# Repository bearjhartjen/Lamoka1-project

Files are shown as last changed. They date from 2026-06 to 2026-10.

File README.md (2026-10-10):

<div align="center">

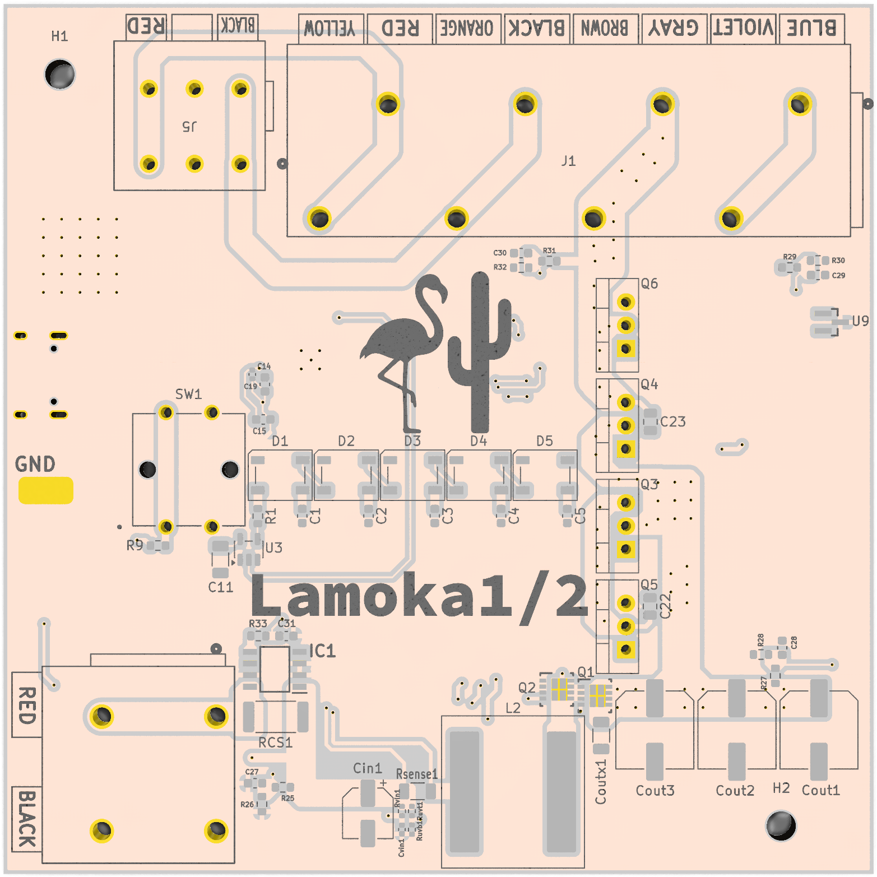
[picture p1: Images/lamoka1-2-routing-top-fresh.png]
Lamoka1/2 main PCB


<br>

<a href="https://www.bestpractices.dev/projects/14750">
  
</a>
&nbsp;&nbsp;
<a href="https://www.repo-grade.com/report/bearjhartjen/lamoka1-project">
  
</a>

</div>

---

## Owego Rotary craft fair 

 For the Owego Rotary craft fair, taking place at the Elks Lodge in Owego, NY, on November 14th from 9am to 3pm, the main project being presented by Flamingo and Cactus will be the Lamoka1/2, an inverter-only version of the Lamoka1. More details will be presented after the event. 

## What is the Lamoka1?

 The Lamoka1 is an open-source inverter/charger system designed for complete transparency and control. Unlike market alternatives that are locked-down black boxes, the Lamoka1 gives you full access to your power conversion. If you don't have technical experience, that's completely fine—our Portal Interface Engine (Lamoka's operating system) provides a solid stock setup. But if you want to get technical, feel free to customize and modify the unit however you like.

---

## Specifications 

 The Lamoka1 inverter section takes an 11V–14V input, steps it up to a 17V rail via the LM5122QMHX-NOPB boost converter, and feeds it into an H-bridge (four CSD19536KCS NMOSs driven by two UCC27735DR gate drivers) controlled by an RP2354A microcontroller—giving you total flexibility to program whatever waveform or output you need. From there, it passes into a VPT24-4170 transformer to step up the voltage.

 We use a Qualtek FAD1-04010BHLW11 fan powered from the 5V buck rail for cooling. GPIO5 and GPIO6 are unused, so the MCU provides no PWM speed control or tach feedback for the fan. The two TMP235A2DBZR temperature sensors are monitored by the system. Voltage and current monitoring is handled by the ADS7128IRTER multiplexer, the 5V rail by the TPS62160DSGR buck converter, and the user interface by ten WS2812B LEDs with a B3F-4055 button.

---

## Usage of AI in this repository 

This repository is checked, maintained, and updated by humans. The Lamoka series is neither “vibe coded” nor blindly applied. Thought, testing, engineering judgment, and practical experience go into every decision made throughout the project.

AI is used as a tool to help us bridge the gap between our current resources and the scale of what we want to accomplish. It may assist with research, development, documentation, and other aspects of the project, but its output is not treated as inherently correct. Human review, testing, and engineering judgment remain essential to the development process.

PIE OS is an exception in that a significant portion of its code was generated with the assistance of AI. However, it has been reviewed, tested extensively, and refined to meet the same standards we apply to the rest of our work.

At Flamingo and Cactus, our goal is to provide the best products, services, and experiences we can to as many people as possible. As a small team, there are limits to what we can accomplish on our own. We have very large dreams, and AI allows us to act as a much larger team without losing the human judgment and responsibility behind what we create.

---

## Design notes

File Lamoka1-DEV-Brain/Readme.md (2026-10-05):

<p align="center">
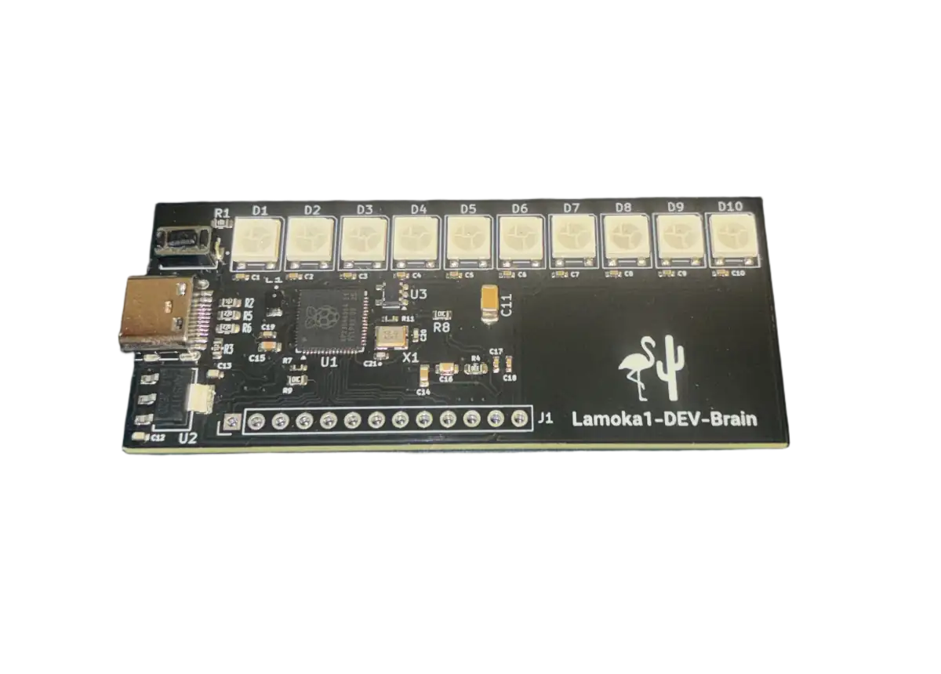
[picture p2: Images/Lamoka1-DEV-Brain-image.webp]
Lamoka1 DEV Brain
  
</p>

<p align="center">
  <strong>Lamoka1-DEV-Brain</strong>
</p>

<p align="center">
  This board can now be ordered
  <a href="https://www.pcbway.com/project/shareproject/Lamoka1_DEV_Brain_49e4fd0a.html">here</a>.
</p>

<p align="center">
  PIE versions v1.8 and below will function on this board.
  For more information on PIE, go
  <a href="../SOFTWARE/README.md">here</a>.
</p>

<p align="center">
  <a href="https://htmlpreview.github.io/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">
    <strong>View Interactive BOM</strong>
  </a>
</p>

---

> [!CAUTION]
> This device is purely for testing. Many decisions were made due to cost and time constraints. The component layout does not follow Raspberry Pi’s recommended layout guidance. Utilize these files at your own discretion.

 Flamingo and Cactus have paid PCBway to manufacture and assemble the DEV Brain. It has arrived and works much better than expected. It does, however, make some high-frequency audible noise when plugged into low-quality power sources, so it is quite sensitive to low-quality sources. 

The DEV-Brain brings the Lamoka1’s MCU, lights, and simplicity into a 70x30mm laminated sandwich (PCB).

We are using the DEV-Brain to get an idea of how things work on the control side. We can use this model board to develop code for the lights and button. We think that the DEV-Brain will be very similar to the Lamoka1, with only ten RGB LEDs and one button.

This board was run through Tomachie to get the design checked; the link is [here](https://tomachie.com/r/a1f3f256-a8ca-43de-aa92-e70ef981c3c2/Lamoka1-DEV-board_report.html#design-summary).

## Why did we develop the Lamoka1-DEV-Brain?

We need an easy platform to better understand how and where to work on the Lamoka1 control. Without a doubt, the control and logic side of the Lamoka1 is extremely important, as it allows us to expose our creativity and community for free, and to just truly have fun. The DEV-Brain also just progresses the project quite a bit and gets us moving; we don't know what to do on designing the inverter and charger sections without getting control down.
 
## How does one reproduce the Lamoka1-DEV-Brain?

 We have published the board to PCBway's share projects platform [here](https://www.pcbway.com/project/shareproject/Lamoka1_DEV_Brain_49e4fd0a.html). There, you will be able to order the Lamoka1-DEV-Brain exactly as we did. 

## Project files

- **KiCad source** — the full KiCad 10 project lives in the `Kicad files` folder. Open [Lamoka1-DEV-board.kicad_sch](<Kicad files/Lamoka1-DEV-board.kicad_sch>) for the schematic, [Lamoka1-DEV-board.kicad_pcb](<Kicad files/Lamoka1-DEV-board.kicad_pcb>) for the board layout, and [Lamoka1-DEV-board.kicad_pro](<Kicad files/Lamoka1-DEV-board.kicad_pro>) for the project settings. The `.kicad_sch` and `.kicad_pcb` files carry embedded symbol, footprint, and 3D model copies, so the design opens and renders without requiring anyone to provide copyrighted material.
- **Fab files** — everything needed to have the board manufactured yourself is in the `Lamoka1-DEV-Brain fab files` folder: the [bill of materials](<Lamoka1-DEV-Brain fab files/Lamoka1-DEV-board BOM.csv>), the [pick and place file](<Lamoka1-DEV-Brain fab files/Lamoka1-DEV-board Pick and Place.csv>), the [Gerber and drill package](<Lamoka1-DEV-Brain fab files/Lamoka1-DEV-board>), and the [PCBway assembly file](<Lamoka1-DEV-Brain fab files/PCBway files/T-1N4W1065266A-1units-Lamoka1-DEV-board+BOM(2026-07-15).xls>) we sent when we ordered our own boards.

## Tests

We were able to run the Lamoka1-DEV-Brain for 72 hours running the idle blue dot bouncing animation seen in [PIE v1.8](<../SOFTWARE/Portal Interface Engine/V1.8.ino>). The environment was an average of 70 degrees Fahrenheit, and an average humidity of 70 percent. We stopped the test early (there were no signs of issues) because we needed to use the Lamoka1-DEV-Brain to test the HTML file creation concept for getting diagnostic data on the Lamoka1.

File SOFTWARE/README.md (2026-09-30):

## What is the Portal Interface Engine?

PIE is the operating system that Lamoka models run on. It provides simple "portals" to whatever you would like with your unit. 

## Compatibility

 PIE versions v1.8 and below will work on the Lamoka1-DEV-Brain (with v1.8 working best). Due to the inclusion of voltage, temperature, and current monitoring on the ADC pins of the Lamoka1, we cannot fully guarantee successful operation of anything newer than v1.8 on the Lamoka1-DEV-Brain.

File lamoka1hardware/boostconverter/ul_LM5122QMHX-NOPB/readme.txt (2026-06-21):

Notes:
 
1. All drill sizes are the maximum size provided by the manufacture (as required to calculate the minimum pad size).
2. All dimensions in building footprints are the maximum (including any tolerance) as defined by the manufacturer with the exception of row pitch (which is always nominal).  If only the normal sizing is provided we will input that dimension in mils, rounded to the nearest mil per our standards.
3. Slots are currently identified as entities describing the size of the slot (arcs, lines, etc.) on the board outline layer.  The extremities are identified with a via at each end.  These slots will either need to be:
	a. identified and dimensioned on your fabrication document
	b. or they will need to be converted to slots (assuming the targeted tool has a slot capability) using the process defined in your cad tool for identifying a padstack as a slot.  
		i. Typically this is only capable of a width and length of the slot and a size of the mill radius that creates the slot.  
		ii. Choosing to use the native tool slots will require removing entities on the board outline and the associated pads in the footprint.

		"I greatly appreciate Texas Instruments for their absolute commitment to providing the best doccumentation, tools, calculators, etc."
		-Bear J. Hartjen

		Texas Instruments is fully responsible for the creation of the LM5122 these kicad files were found on ultra librarian.

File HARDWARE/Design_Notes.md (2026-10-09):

## MCU GPIO pin connections

 GPIO0: Connected high to 3v3 by a 10k resistor, then goes to a B3F-4055 button made by Aratas that, when pressed, pulls the pin low to ground 

 GPIO1: Controls Q3 MOSFET (CSD19536KCS made by TI) through UCC27735DR IC made by TI

 GPIO2: Controls Q5 MOSFET (CSD19536KCS made by TI) through UCC27735DR IC made by TI

 GPIO3: Controls Q4 MOSFET (CSD19536KCS made by TI) through UCC27735DR IC made by TI

 GPIO4: Controls Q6 MOSFET (CSD19536KCS made by TI) through UCC27735DR IC made by TI

 GPIO5: Not in use (unused, no connection)

 GPIO6: Not in use (unused, no connection)

 GPIO8: Connects to ADS7128IRTER made by TI SDA pin for serial data pulled up to 3v3 by a 4.7k resistor

 GPIO9: Connects to ADS7128IRTER made by TI SCL pin for serial clock pulled up to 3v3 by a 4.7k resistor

 GPIO11: Goes to a level shifter to get up to 5v, then to a 330 ohm resistor, then connects to a string of ten WS2812B lights made by WorldSemi arranged next to each other from left to right with D1 starting and D10 finishing. The press button (B3F-4055 made by Aratas) is to the left of D1.

 GPIO26: Output of the TMP235A2DBZR temp sensor made by TI located in the Control-Section

 GPIO27: Output of the TMP235A2DBZR temp sensor made by TI located in the Inverter-Section 

---

## MUX AIN pin connections (ADS7128IRTER made by TI)

 AIN0: input rail voltage sensing, top resistor 36.5k, bottom resistor 10k, 47nF cap to ground on AIN pin  

 AIN1: output of 17v boost converter voltage sensing, top resistor 43.2k, bottom resistor 10k, 47nF cap to ground on AIN pin 

 AIN2: SW_A (Leg A of H-bridge) voltage sensing, top resistor 45.3k, bottom resistor 10k, 47nF cap to ground on AIN pin

 AIN3: SW_B (Leg B of H-bridge) voltage sensing, top resistor 45.3k, bottom resistor 10k, 47nF cap to ground on AIN pin 

 AIN4: Current sensing for source rail, 11-14v goes through a 2m shunt; the shunt is connected to the INA240A2DR IC, the OUT pin of that IC goes to a 22 ohm resistor to the AIN pin, the AIN pin has a 100nF cap to ground.

---

## H-bridge (Inversion-Section) — four CSD19536KCS NMOSs made by TI, two UCC27735DR gate drivers made by TI

| H-bridge leg | High-side MOSFET | Low-side MOSFET | Gate driver | RP2354A control |
|---|---|---|---|---|
| Leg A | Q3 | Q5 | U5 | GPIO1 / GPIO2 |
| Leg B | Q4 | Q6 | U6 | GPIO3 / GPIO4 |

> **H-bridge switching:** Q3/Q5 and Q4/Q6 are the complementary MOSFET pairs for Leg A and Leg B respectively. Dead time must be implemented between the high-side and low-side devices of each leg to prevent shoot-through.

---

## Design constraints

 We are refraining from putting in a 5v USB output for the Lamoka1. This is because our 11-14v to 5v buck converter (TPS62160DSGR made by TI) is designed for usage up to one amp. In future Lamoka models, if a USB output (preferably USB-C) is established, the buck converter would have to be beefed up; however, it would be even better if we had a USB-C PD circuit in so the user could get a better experience across a wider range of usage. 

 The transformer applied to the Lamoka1 is the VPT24-4170 made by Triad Magnetics, five pounds and around $80. We understand this may be a strong downside to some people; however, we found this was the best widely available option, plus it adds efficiency prospects. 

## User interface board

Unfortunately, we had to create a whole separate board for the user interface due to how large the VPT24-4170 transformer is. Both boards will be attached with mouse bites so that they can be easily fabricated and assembled together; then you can simply break them apart when you receive them. The two boards will be attached by a wired connector, allowing us to route in a heatsink and other airflow-conscious design choices, instead of having to accommodate ten RGB LEDs and a button.

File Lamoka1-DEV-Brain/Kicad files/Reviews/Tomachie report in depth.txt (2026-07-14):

Generated by Tomachie v3.85 2026-07-14 13:27:31
Copyright © 2026 Tomachie LLC. All rights reserved.

Lamoka1-DEV-board Design Analysis
1  Design Summary

  97
  out of 100

Design TypeFlat (1 sheets)
Total Components92
Total Pins293
Total Nets42
Total Test Points0

Improve your score:

Improve fault coverage (opens/shorts) +2
Use IPC-compliant footprint names +1

Points deducted for open High/Medium AI findings:

0 High, 1 Medium -0.5

AI findings to review:

Power findings — 1 Medium

AI assistance is enabled for this report. Each section marked "AI-Assisted" contains AI-generated engineering observations produced during schematic-phase design review. Findings are based solely on connectivity, component values, and net annotations present in the schematic data at the time of analysis. The AI has no access to PCB layout, routing, thermal data, BOM pricing or availability, assembly constraints, or any information outside the schematic. Findings are observations to investigate, not pass/fail judgments. The absence of a finding for a given device or net does not constitute a clearance. STANDARD MODE — this analysis was produced by the standard model tier.
1.1  Design Overview
AI-Assisted —
The board is a single-sheet microcontroller development platform built around U1, a Raspberry Pi RP2040 dual-core Arm Cortex-M0+ microcontroller (marked SC1511-A4) in a QFN-60 package with an exposed pad. The design pairs the microcontroller with a USB 2.0 Type-C interface, a 12.000 MHz crystal timebase, a ten-node addressable RGB LED chain, a general-purpose I/O header, and a single momentary pushbutton. The board is fully instrumented with flying-probe test points across its signal and power nets.

Processing and Clocking

U1 provides the digital core, on-chip QSPI flash interface, ADC inputs, and USB full-speed PHY. The system timebase is X1, an Abracon ABM8-272-T3 12.000 MHz fundamental-mode crystal with a 10 pF load capacitance, matched to two 15p loading capacitors and a series/return network on the XIN/XOUT terminals. The crystal is rated -40°C to +85°C. Programming and debug are served by the RP2040 SWD port.

Interfaces

External connectivity is provided by J3, a 14-pin USB Type-C receptacle wired for USB 2.0 signalling, with the two CC pins terminated through 5.1k configuration resistors R2 and R3 establishing the board as an upstream-facing (device) port. The D+/D- pair reaches U1 through 27 series resistors R5 and R6. J1 is a 1x13 vertical 2.54 mm pin header breaking out thirteen GPIO lines and supply/ground for expansion. SW1 is a momentary pushbutton on GPIO0. Ten Worldsemi WS2812B integrated RGB LEDs (D1-D10) form a single-wire NZR data chain running from U1 through a level-translating buffer; the WS2812B operates over -25°C to +80°C junction. U3, a Texas Instruments SN74AHCT1G125 single tri-state buffer, level-shifts the 3V3 LED data output up to the 5V logic level required by the WS2812B chain.

Power Tree

Board power originates from the USB Type-C VBUS at 5 V, forming the 5V rail that supplies the LED chain and the buffer. U2, an Advanced Monolithic Systems AMS1117-3.3 SOT-223 linear regulator, derives the 3V3 rail from 5V; its datasheet typical output is 3.300 V. The RP2040 on-chip core regulator generates the 1V1 core rail through switching node VREG_LX and the 3.3u inductor L1, and VREG_AVDD supplies the regulator's analog domain. Detailed rail sourcing and pin connectivity are covered in the power analysis section.

Temperature Range

The assembled operating range is bounded by the WS2812B LEDs at -25°C to +80°C; the crystal (-40°C to +85°C), regulator, and buffer are all rated at or beyond that window.

Boundary Scan

No boundary-scan-capable device with a matched BSDL model is present on this board; the RP2040 exposes an SWD debug port rather than an IEEE 1149.1 TAP, and no other device provides a boundary-scan chain. Interconnect and structural coverage rely on the flying-probe test-point instrumentation, which is addressed in the Design-for-Test section.
1.2  Processed Sheets

#Sheet Name

1Lamoka1-DEV-board.kicad_sch

1.3  Footprint Compliance
Production pick-n-place, AOI, AXI, ATE and Design Quality tools rely on proper descriptions of component footprints.

Footprint NamingStatus

15 SMT footprints do not follow IPC-7351B naming✗
2 footprints (connectors, specialty) — compliance unknown
1 footprints could not be classified for inspection✗

2  Component Value Properties
Component values should be in the VALUE property, either as a direct value (e.g. 100nF) or as a formula reference (e.g. =Capacitance). The typed property (Resistance, Capacitance, Inductance, Impedance, etc.) holds the actual electrical value; VALUE should point to it or contain the same data.

Value Property Check

TypeCheckCountComponentsStatus

CapacitorsValues in VALUE or Capacitance21C4, C2, C11, C14, C1, C15, C7, C3 (+13 more)
ResistorsValues in VALUE or Resistance10R2, R8, R1, R7, R9, R3, R6, R11 (+2 more)
InductorsValues in VALUE or Inductance1L1
OscillatorsValues in VALUE or Frequency1X1

3  Pin Connectivity Report
All pins properly connected or marked.
3.1  Implied/Hidden Net Connections
No components with implied/hidden net connections found.
3.2  Open-Collector Pull-up Audit
Examined 0 candidate pin(s) on 0 net(s).
3.3  Summary

Total NO_ERC markers in design26
Pins needing attention (warnings)0
Pins for information only0

4  Power Overview

Power rails2
Power management sources identified1

Analysis of passive component footprint suitability, voltage ratings, and power dissipation is not performed in this revision.
Power architecture overview. For test point coverage, see Design-for-Test section.
4.1  Power Rail Analysis

Power Rails

RailVoltageSourceConsumers

5V5.00VJ1ExternalU2 (AMS1117-3.3),U3 (SN74AHCT1G125DBVR)
GND-J1External-

4.2  AI-Assisted Analysis
This section is created by AI and should be reviewed for accuracy. There may be some incorrect analysis, especially if any errors are called out in the Design Summary or Component Value sections. STANDARD MODE — this analysis was produced by the standard model tier.
4.2.1  Power Tree Overview
AI-Assisted —
Board power originates off-board at 5 V: USB Type-C VBUS (J3 pins A4/A9/B4/B9) and header J1 pin 13 form the 5V rail. The rail is bulk-decoupled with 111 µF total (1x100u + 1x10u + 10x100n). 5V feeds three loads: the AMS1117-3.3 LDO (U2) input, the SN74AHCT1G125 buffer (U3) VCC, and the VDD of the ten WS2812B pixels (D1-D10). U2 produces the 3V3 rail (VOUT typ 3.300 V, AMS1117 datasheet p.2), which supplies the RP2354 (U1) IOVDD/ADC_AVDD/USB_OTP_VDD group and the internal-regulator input VREG_VIN (pin 49). U1's on-chip buck regulator switches on VREG_LX (pin 48) through the 3.3u inductor L1 to generate the 1V1 core rail that returns to VREG_FB (pin 50) and powers the DVDD pins. Sequencing is monotonic and self-timed: 5V rises first, the LDO brings up 3V3, then the RP2354 internal regulator brings up 1V1; RUN (pin 26) is released by the 10k pull-up R8 to 3V3, so the core comes out of reset only once 3V3 is valid. All supply and ground pins of both power devices (U2 VIN/VOUT/GND; U1 VREG_VIN/VREG_PGND/VREG_LX/VREG_FB) sit on nets with proper DC paths.
4.2.2  AMS1117-3.3 Linear Regulator (U2)
AI-Assisted —
The fixed 3.3 V SOT-223 LDO takes 5V on VIN (pin 3) and drives 3V3 on the doubled VOUT pins (2, 4); GND (pin 1) returns to the ground rail. Input decoupling on 5V is generous. The dropout at 0.8 A is 1.1 V typ (datasheet p.3), so 1.7 V of headroom from 5 V is ample. At an estimated few-hundred-mA core/IO load the SOT-223 dissipates roughly 0.5 W (1.7 V x 0.3 A); with θ_JA 55-80 °C/W (datasheet Table 1, p.5) the junction rise stays well below the 165 °C thermal-shutdown point. The concern is output capacitance: the AMS1117 datasheet (p.4) calls for a 22 µF solid tantalum output capacitor for loop compensation. The 3V3 node carries C13 10u + C14 4.7u + C17 100n + C18 100n (about 14.9 µF nominal, all ceramic, further derated under DC bias) plus C16 4.7u behind R4 33. The total is below the 22 µF minimum and uses low-ESR ceramic rather than the specified tantalum, which can compromise the regulator's stability margin.
4.2.3  RP2354 On-Chip Core Regulator (U1, 1V1)
AI-Assisted —
The RP2354's integrated buck regulator generates the 1.1 V core. VREG_VIN (pin 49) is powered from 3V3; the switching node VREG_LX (pin 48) drives inductor L1 (3.3u) to the 1V1 output; VREG_FB (pin 50) senses 1V1; VREG_PGND (pin 47) returns to GND. The 1V1 rail carries C15 4.7u + C19 100n (4.8 µF) of output decoupling to GND, and the DVDD core pins (6, 23, 39) sit on it. The regulator's analog supply VREG_AVDD (pin 46) is filtered from 3V3 by R4 33 with C16 4.7u to GND, forming an RC supply filter. The output-referenced feedback and inductor topology match an internally compensated buck; L1 is a 3.3u part, consistent with the switching converter. No external ground- or supply-pin faults exist on the regulator pins.
4.2.4  5 V Input, USB and LED Signal Domain
AI-Assisted —
USB Type-C is configured as a sink/UFP: CC1 and CC2 carry 5.1k pull-downs to GND (R2 on Net-(J3-CC1), R3 on USB_CC2), the correct Rd terminations. D+/D- pairs are strapped together and series-terminated with 27 R (R6 on USB_CONN_DP, R5 on USB_CONN_DM) into U1's USB_DP/USB_DM. The connector shield bonds to logic ground through net-tie NT2. The WS2812B pixels run their VDD on 5V, inside the device's 4.5-5.5 V operating window (WS2812B datasheet p.3); each pixel has a 100n local bypass (C1-C10), meeting the datasheet's 0.1 µF-per-device recommendation (p.5). Because the WS2812B input threshold is VIH = 0.7·VDD = 3.5 V at 5 V VDD, the 3.3 V GPIO11 cannot drive DIN directly; U3 (SN74AHCT1G125, TTL-compatible, VIH min 2 V) correctly translates the level to 5 V, with its OE (pin 1) tied low to keep the output enabled, and R1 330 R provides series damping into the D1 DIN. The bootsel/QSPI_SS sense (R7 1k from BTN to QSPI_SS_N, R9 10k pull-up, SW1 to GND) is the standard button arrangement; the RP2354A's on-die flash makes external QSPI memory unnecessary, so the unused QSPI pins are intentionally left open.
4.3  Observations
AI-Assisted —
The 5V input has no series overcurrent fuse or TVS between the Type-C connector and the downstream loads; for a development board this is acceptable but leaves VBUS unprotected against a downstream short or transient. The 12.000 MHz crystal X1 (Abracon ABM8-272, CL 10 pF) uses two 15p load capacitors (C20, C21) with a 1k series resistor R11 on the XOUT leg; the resulting effective load of about 11.5 pF (7.5 pF from the two caps plus stray) slightly exceeds the crystal's 10 pF specification and will pull the frequency marginally low, still within the USB clock budget. Every regulator supply and ground pin has been traced to a valid DC node. All capacitors on the board are ceramic (unpolarized), so no polarity risk exists.
4.4  Findings
AI-Assisted —

DeviceRailObservationSeverity

U2 (AMS1117-3.3)3V3Output capacitance ~14.9 µF ceramic (C13/C14/C17/C18), below the 22 µF solid-tantalum minimum specified for loop stability; low-ESR ceramic differs from recommended dielectric (AMS1117 datasheet p.4)Medium
X1 (ABM8-272)-12.000 MHz, R11 1k series on XOUT, 15p load caps give ~11.5 pF effective vs 10 pF spec CL — slight low-frequency pull, within USB budget (Abracon ABM8-272 datasheet)Review
J3 (USB-C)5VNo series fuse or TVS between VBUS and downstream loads — acceptable for a dev board but VBUS is unprotected (design review note)Review
U2 (AMS1117-3.3)5V→3V3VIN (pin 3) on 5V, VOUT (pins 2/4) on 3V3, GND (pin 1) on GND — all supply/ground pins have valid DC paths (AMS1117 datasheet p.1)
U2 (AMS1117-3.3)5VInput decoupling 111 µF (100u+10u+10x100n) ample (AMS1117 datasheet p.4)
U2 (AMS1117-3.3)3V31.7 V drop vs 1.1 V dropout at 0.8 A; ~0.5 W in SOT-223, θ_JA 55-80 °C/W keeps Tj below 165 °C shutdown (AMS1117 datasheet p.3, Table 1 p.5)
U1 (RP2354 VREG)1V1On-chip buck: VREG_LX→L1 3.3u→1V1, VREG_FB senses output, output decoupling C15 4.7u + C19 100n = 4.8 µF to GND
U1 (RP2354 VREG)3V3/1V1/GNDVREG_VIN (49) on 3V3, VREG_PGND (47) on GND, VREG_LX (48)/VREG_FB (50) correctly on switching/feedback nets — all DC paths valid
U1 (RP2354)VREG_AVDDAnalog regulator supply RC-filtered from 3V3 via R4 33 + C16 4.7u to GND
U1 (RP2354)RUNReset released by 10k pull-up R8 (pin 1 on 3V3) to RUN_N — correct power-up sequencing
U1 (RP2354)QSPI_SS_NBOOTSEL sense via R7 1k to BTN with R9 10k pull-up (pin 1 on 3V3) and SW1 to GND; internal flash makes external QSPI memory unnecessary
U3 (SN74AHCT1G125)5VAHCT buffer level-shifts 3.3 V GPIO to 5 V for WS2812B (VIH 0.7·VDD = 3.5 V); OE (pin 1) tied low = output enabled (TI SN74AHCT1G125 datasheet p.4, WS2812B datasheet p.3)
U3 (SN74AHCT1G125)-R1 330 R series damping on buffered data into D1 DIN
D1-D10 (WS2812B)5VVDD at 5 V within 4.5-5.5 V window; 100n per pixel (C1-C10) meets 0.1 µF decoupling recommendation (WS2812B datasheet p.3/p.5)
J3 (USB-C)-CC1/CC2 5.1k Rd pull-downs (R2/R3) configure device/UFP role correctly
J3 (USB-C)-D+/D- 27 R series terminations (R5/R6) into U1 USB pins
NT2-USB shield bonded to logic GND through the net tie — intended chassis-to-signal bond

4.5  Citations
AI-Assisted —

References

ABM8-272 (Abracon) — datasheetdatasheet.lcsc.com/datasheet/pdf/d5520a242c89eeaef42f6496...
AMS1117-3.3 (Advanced Monolithic Systems) — datasheet, cited pages 1micmodshop.ir/wp-content/uploads/2021/11/AMS1117-DataShee...
SN74AHCT1G125 (Texas Instruments) — datasheetwww.ti.com/lit/ds/symlink/sn74ahct1g125.pdf
WS2812B (Worldsemi) — datasheet, cited pages 1,5cdn-shop.adafruit.com/datasheets/WS2812B.pdf

5  Connector Pinouts

Total connectors2

5.1  J1 TSW-113-07-G-S

J1 - TSW-113-07-G-S (TSW-113-07-G-S)

PinPin NameNetNotes

1Pin_1GPIO1
2Pin_2GPIO2
3Pin_3GPIO3
4Pin_4GPIO4
5Pin_5GPIO5
6Pin_6GPIO6
7Pin_7GPIO7
8Pin_8GPIO8
9Pin_9GPIO9
10Pin_10GPIO10
11Pin_11GND
12Pin_123V3
13Pin_135V

5.2  J3 TYPE-C-31-M-12

J3 - TYPE-C-31-M-12 (TYPE-C-31-M-12)

PinPin NameNetNotes

A1GNDGND
A4VBUS5V
A5CC1Net-(J3-CC1)
A6D+USB_CONN_DP
A7D-USB_CONN_DM
A9VBUS5V
A12GNDGND
B1GNDGND
B4VBUS5V
B5CC2USB_CC2
B6D+USB_CONN_DP
B7D-USB_CONN_DM
B9VBUS5V
B12GNDGND
SHSHIELDSHIELD_GND_TYPE_C

6  Indicator Documentation
10 indicator device(s) found.
6.1  Indicator Assignments

Indicators

RefDesTypeColorSignalSheetNotes

D6WS2812B-LED_D6_DOUTLamoka1-DEV-board.kicad_schNo current-limiting resistor; A:5V K:LED_D6_DOUT
D5WS2812B-LED_D5_DOUTLamoka1-DEV-board.kicad_schNo current-limiting resistor; A:5V K:LED_D5_DOUT
D8WS2812B-LED_D8_DOUTLamoka1-DEV-board.kicad_schNo current-limiting resistor; A:5V K:LED_D8_DOUT
D3WS2812B-LED_D3_DOUTLamoka1-DEV-board.kicad_schNo current-limiting resistor; A:5V K:LED_D3_DOUT
D2WS2812B-LED_D2_DOUTLamoka1-DEV-board.kicad_schNo current-limiting resistor; A:5V K:LED_D2_DOUT
D10WS2812B-LED_D9_DOUTLamoka1-DEV-board.kicad_schNo current-limiting resistor
D4WS2812B-LED_D4_DOUTLamoka1-DEV-board.kicad_schNo current-limiting resistor; A:5V K:LED_D4_DOUT
D1WS2812B-LED_D1_DOUTLamoka1-DEV-board.kicad_schR1 (330); A:5V K:LED_D1_DOUT
D9WS2812B-LED_D9_DOUTLamoka1-DEV-board.kicad_schNo current-limiting resistor; A:5V K:LED_D9_DOUT
D7WS2812B-LED_D7_DOUTLamoka1-DEV-board.kicad_schNo current-limiting resistor; A:5V K:LED_D7_DOUT

6.2  Indicator Testability
10 of 10 indicators have test coverage.

Indicator Testability

RefDesDriverControl SignalDFT StatusTestable

D6DirectLED_D6_DOUTTestpoint available. Drive HIGH to turn on.
D5DirectLED_D5_DOUTTestpoint available. Drive HIGH to turn on.
D8DirectLED_D8_DOUTTestpoint available. Drive HIGH to turn on.
D3DirectLED_D3_DOUTTestpoint available. Drive HIGH to turn on.
D2DirectLED_D2_DOUTTestpoint available. Drive HIGH to turn on.
D10DirectLED_D9_DOUTTestpoint available. Drive HIGH to turn on.
D4DirectLED_D4_DOUTTestpoint available. Drive HIGH to turn on.
D1DirectLED_D1_DOUTTestpoint available. Drive HIGH to turn on.
D9DirectLED_D9_DOUTTestpoint available. Drive HIGH to turn on.
D7DirectLED_D7_DOUTTestpoint available. Drive HIGH to turn on.

7  Switch Documentation
1 switch(es) found in design.
7.1  Switch Configurations

  A
  B

SW1 Contact Pairs (PTS636 SM43J SMTR LFS)

ContactPin ANet APin BNet BWhen OpenWhen ClosedNotes

12GND1BTNSIGNALLOW

SW1 All Pins

Pin #Pin NameNetPaired WithType

22GND1CONTACT
11BTN2CONTACT

7.2  Switch DFT Analysis
Switches for mode selection are useful for development and manual debug, but production test environments require electrical override capability. Latching switches (DIP) that hold a signal to GND need isolation resistors so ATE can override. Momentary switches (push buttons) don't hold the signal, but ATE still needs test point access to stimulate the signal.

  VCC

  IC Pin

  TP

  Rs

  SW

  GND

    Testpoint and Rs isolation resistor placement

Design Rationale: Switches for mode selection are valuable for engineering development and bench debug. However, production test and field returns require electrical override capability without manual intervention. Adding test points and isolation resistors creates a lifecycle-robust design that works across development, production test, and field returns without requiring procedure documentation or specialized knowledge of switch positions. The goal is a self-documenting, procedure-proof test interface. BOM impact: One 0201/0402 resistor per controlled signal.

SwitchSignalFunctionPullupRailIssueTest Point?

SW1QSPI_SS_NSwitch-controlled signal(not found)BTNExisting isolation R7 — add TP on QSPI_SS_N

8  Low-Speed Serial Interfaces (LSSI)
Detected: 1 SWD
8.1  SWD

SWD

SignalNet NameConnectorTest Point

SWCLK(none)(none)
SWDIO(none)(none)

8.2  LSSI DFT Analysis
2 signal(s) missing test point coverage. Test points allow ATE to run tests without requiring operator intervention and setup. They should be considered mandatory for high volume products.
During test, ATE can override functional operation to explicitly test through the interface in ways that functional operation cannot, or is not available at certain test stages.

Missing Test Points

SignalNet NameConnectorInterface

SWCLK(none)SWD
SWDIO(none)SWD

9  High-Speed Serial Interfaces (HSSI)
No controlled impedance nets detected in design.
10  Memory Interface Analysis
No memory devices with detectable bus interfaces found.
11  Functional Analysis
5 device(s) to review across 1 category(ies)

Device Inventory

RefDesCategoryPart NumberDescriptionInterfacesHSSI

NT1DEVICENetTie_2Net tie, 2 pins--
NT2DEVICEUSB_SHIELD_BONDExplicit USB Type-C shield-to-logic-ground bond intent--
U1DEVICESC1511-A4A microcontroller by Raspberry Pi, dual CPU architecture (ARM Cortex-M33 / RISC-V Hazard3), 150MHz, 2MB flash, 520KB SRAM, 12 PIO state machines, VQFN-60--
U3DEVICESN74AHCT1G125DBVRSingle Buffer Gate Tri-State, Low-Voltage CMOS--
X1DEVICEABM8-272-T3--

11.1  Functional Analysis
This section is created by AI and should be reviewed for accuracy. There may be some incorrect analysis, especially if any errors are called out in the Design Summary or Component Value sections. STANDARD MODE — this analysis was produced by the standard model tier.
11.1.1  Microcontroller U1 (SC1511-A4 / RP2350)
AI-Assisted —
The core switch-mode supply matches the RP2350 reference design: VREG_LX drives a 3.3µF inductor (L1, AOTA-B201610S3R3, 3.3u) into the 1V1 core rail, VREG_FB senses 1V1 for regulation, and the core rail carries 4.8µF of decoupling (1x4.7u + 1x100n). VREG_VIN and the analog rails derive from 3V3; VREG_AVDD is correctly filtered by R4 (33) with C16 (4.7u) to the pin, and ADC_AVDD ties to 3V3. Both ground returns, U1_61 GND and U1_47 VREG_PGND, sit on the GND net with a valid DC path. RUN is held by R8 (10k) to 3V3 as reset pull-up. The BOOTSEL path is correct: SW1 pulls the QSPI chip-select node low through R7 (1k) against R9 (10k) pull-up on GPIO0/BTN. The external QSPI data/clock pins are intentionally left unconnected, consistent with use of the device's internal 2MB flash. USB D+/D- use 27R series resistors R6/R5 to the Type-C receptacle, and CC1/CC2 each carry an independent 5.1k Rd pull-down (R2, R3) — the correct sink (UFP) termination. One observation: the 3V3 rail feeds six IOVDD pins plus ADC_AVDD, VREG_VIN, USB_OTP_VDD and QSPI_IOVDD, but only two 100n high-frequency capacitors (plus 10u and 4.7u bulk) are present; Raspberry Pi guidance suggests ~100nF per supply pin, so additional local decoupling would improve margin. Not a functional defect on a development board.
11.1.2  Crystal X1 (ABM8-272-T3, 12 MHz)
AI-Assisted —
X1 provides the 12.000 MHz reference. Terminal 1 connects directly to XIN and terminal 2 returns through R11 (1k) to XOUT — the series drive resistor recommended for the RP2350 crystal oscillator, which limits drive level against the crystal's 200µW maximum. Load capacitors C20 and C21 (15p each, C0G) sit from each crystal terminal to GND; for the datasheet load capacitance of 10 pF the required per-leg value with a few pF of stray is ~14–16 pF, so 15p is well matched. The two case pads (X1_2, X1_4) are grounded. Frequency tolerance and stability of ±30 ppm are comfortably within USB full-speed timing requirements. Wiring and passive values are correct per the Abracon ABM8-272 datasheet.
11.1.3  Level Buffer U3 (SN74AHCT1G125DBVR)
AI-Assisted —
U3 is used as a 3.3 V→5 V level translator for the WS2812B data line, exploiting the TTL-compatible AHCT inputs: input A (pin 2) receives the 3.3 V LED_DATA_3V3 signal from U1 GPIO11, and the buffered output Y (pin 4) drives the LED chain through a 330 series resistor (R1). Per the TI SN74AHCT1G125 datasheet VIH(min) is 2 V, so the 3.3 V logic high is reliably recognized. VCC (pin 5) is on the 5V rail, within the recommended 4.5–5.5 V range, and GND (pin 3) is on GND. Output-enable OE (pin 1) is tied to GND, holding the output permanently enabled — a legitimate fixed-enable configuration. For bench debug a resistor soft-tie plus a test point on OE would improve testability, but this is a preference, not a fault. The 5V rail carries ample 100n decoupling adjacent to the device, satisfying the datasheet's 0.1 µF bypass recommendation. The fitted DBVR (SOT-23-5) order option is production status; only the DBVT/DCKT reel variants are obsolete, so no lifecycle concern applies here.
11.1.4  Ground and Shield Net Ties (NT1, NT2)
AI-Assisted —
NT1 is a deliberate copper net tie merging the regulator ground reference into the main GND node as a single star point; both pins reside on GND. This is an intentional join, not a shorted or duplicated net. NT2 implements the Type-C shield-to-logic-ground bond, connecting the receptacle SHIELD/CHASSIS_GND to GND. Both are intended connectivity. The direct shield bond is acceptable; a parallel resistor-plus-capacitor bond is an alternative EMC option but not required, and either choice is a design preference.
11.2  Findings
AI-Assisted —

DeviceFindingSeverity

U1 (SC1511-A4)3V3 supplies many IOVDD/analog pins but only two 100n high-frequency caps; below Raspberry Pi ~100nF-per-pin guidance — added local decoupling would improve margin.Review
U1 (SC1511-A4)Core SMPS correct: VREG_LX→L1 (3.3u)→1V1, VREG_FB senses 1V1, 4.8µF core decoupling — matches RP2350 reference design.
U1 (SC1511-A4)VREG_AVDD filtered from 3V3 via R4 (33) + C16 (4.7u); ADC_AVDD on 3V3 per datasheet.
U1 (SC1511-A4)Ground returns U1_61 (GND) and U1_47 (VREG_PGND) both on GND — valid DC path.
U1 (SC1511-A4)USB D+/D- use 27R series resistors (R6/R5) to Type-C; correct series termination.
U1 (SC1511-A4)USB-C CC1/CC2 each carry independent 5.1k Rd pull-down (R2/R3) — correct sink termination.
U1 (SC1511-A4)RUN held to 3V3 by R8 (10k) reset pull-up; BOOTSEL via QSPI_SS/R7 (1k)/SW1 against R9 (10k) — correct.
U1 (SC1511-A4)External QSPI data/clock pins intentionally unused, consistent with internal 2MB flash.
X1 (ABM8-272-T3)12 MHz crystal: 15p load caps (C20/C21) match datasheet CL=10pF with stray; XOUT series R11 (1k) limits drive per RP2350 oscillator guidance.
X1 (ABM8-272-T3)±30 ppm tolerance/stability adequate for USB full-speed; case pads grounded.
U3 (SN74AHCT1G125DBVR)AHCT TTL inputs perform 3.3V→5V translation for WS2812B data; VIH(min)=2V recognizes 3.3V high (TI datasheet).
U3 (SN74AHCT1G125DBVR)VCC on 5V within 4.5–5.5V recommended range; GND on GND; 0.1µF bypass present on 5V rail.
U3 (SN74AHCT1G125DBVR)OE tied to GND = permanently enabled — legitimate fixed-enable configuration, not a fault.
NT1 (NetTie_2)Intentional net tie joining regulator ground into GND star point; both pins on GND.
NT2 (USB_SHIELD_BOND)Intentional Type-C shield-to-GND bond; acceptable EMC choice.

11.3  Citations
AI-Assisted —

References

ABM8-272 (Abracon) — datasheetdatasheet.lcsc.com/datasheet/pdf/d5520a242c89eeaef42f6496...
AMS1117-3.3 (Advanced Monolithic Systems) — datasheet, cited pages 1micmodshop.ir/wp-content/uploads/2021/11/AMS1117-DataShee...
SN74AHCT1G125 (Texas Instruments) — datasheetwww.ti.com/lit/ds/symlink/sn74ahct1g125.pdf
WS2812B (Worldsemi) — datasheet, cited pages 1,5cdn-shop.adafruit.com/datasheets/WS2812B.pdf

12  Designer Annotated Nets
No designer-annotated nets found.
13  EMC & ESD Protection Checks

Checks run1
Passed1
Issues found0

EMC Check Summary

CheckIssuesStatus

Connector Shell Grounding0

13.1  EMC & ESD Analysis
This section is created by AI and should be reviewed for accuracy. There may be some incorrect analysis, especially if any errors are called out in the Design Summary or Component Value sections. STANDARD MODE — this analysis was produced by the standard model tier.
13.1.1  EMC Architecture — Grounding, Filtering and Shielding
AI-Assisted —
The board runs a single logic ground (GND) with one deliberate star join: NT1 merges VREG_GND into GND. The USB Type-C shell is not dropped onto that same logic net — J3 pin SH lands on a dedicated node SHIELD_GND_TYPE_C, which reaches GND only through the explicit bond part NT2. This captures the shield-bond strategy as design intent and gives the layout engineer net-level guidance to keep the connector shield pour separable from the plane. Line filtering that is present is appropriate: the two USB high-speed pairs carry R5/R6 27-ohm series resistors (matching the Raspberry Pi RP2040 Hardware Design guide recommendation for USB_DP/USB_DM edge control), the WS2812B chain input carries R1 330-ohm series damping, and the crystal net uses R11 1k series with C20/C21 15p load caps. The 5V rail entering from VBUS is bulk/HF decoupled with 111uF total (1x100u + 1x10u + 10x100n). Clock energy from X1 (ABM8) and the WS2812B 800 kHz data edges are the primary internal emission sources; the series resistors slow those edges and support CISPR 32 / EN 55032 radiated-emission margins for consumer equipment.
13.1.2  USB Type-C Receptacle (J3) — External Consumer Port
AI-Assisted —
J3 is a 14-pin USB 2.0 Type-C receptacle and is the only enclosure-penetrating, user-mated interface — it is subject to IEC 61000-4-2 contact/air discharge and USB Type-C R2.5. Configuration channel handling is correct for a fixed sink: CC1 and CC2 each carry a 5.1k pull-down to GND (R2 on Net-(J3-CC1), R3 on USB_CC2), the Rd presentation required by the Type-C spec; neither CC pin drives a PD controller, so the board is a 5V-only device. VBUS (A4/A9/B4/B9) feeds the 5V rail and U2 VIN. The two data pairs are shorted per Type-C convention (A6/B6, A7/B7) and pass through R6/R5 27-ohm series resistors to U1 USB_DP/USB_DM. No transient-voltage protection is fitted on VBUS, D+/D- or CC. The RP2040 pads carry only device-level HBM ESD tolerance, well below the ±8 kV contact / ±15 kV air stress a user port sees under IEC 61000-4-2; a low-capacitance USB TVS array on the data pair and a VBUS clamp are worth investigating for field robustness. The shield (SH) is bonded to GND via NT2 on the dedicated SHIELD_GND_TYPE_C net, satisfying USB-C R2.5 Section 3.2.1 (shell to PCB ground).
13.1.3  USB Type-C Shield Bond — Enclosure-Dependent Options
AI-Assisted —
The schematic shows J3's shell on SHIELD_GND_TYPE_C bonded to logic GND through NT2, so the intent is explicit and layout-visible. The correct completion depends on enclosure type, which the schematic does not reveal. In a plastic consumer enclosure (Scenario A) no earth exists, the logic GND plane is the only ESD sink, and the shell pour should tie directly to GND through dense via stitching with no isolation network so the plane and shell rise together during a strike, keeping pin-to-pin differential near zero. In a metal-chassis / earthed product (Scenario B) review whether a 1 Mohm || 4.7 nF (>=2 kV) R||C isolation between the shield pour and logic GND, plus a mechanical bond of the pour to chassis at the opening, is needed to avoid ground loops while still shunting HF ESD. Either way the shell pad wants thermal reliefs plus compensating vias into a low-inductance pour under J3 for an IEC 61000-4-2 return path. No layout claim is made here — only that the net-level bond intent exists and the enclosure decision remains open.
13.2  Observations
AI-Assisted —
J1 is a 13-pin 2.54 mm pin header breaking out GPIO0-GPIO10 plus 3V3 (pin 12), GND (pin 11) and 5V (pin 13). It is an unshielded board-level expansion/debug header with no series filtering or ESD clamps on the GPIO lines; if wiring leaves the enclosure through it, immunity and radiated behavior become dependent on the attached harness, and the mating assembly would carry any needed protection. All fitted capacitors are ceramic (X7R/X5R/C0G classes per the specified part numbers) — there are no electrolytic or tantalum parts and no polarity-sensitive passives to orient, and no directional TVS/zener devices exist in the design, so no orientation faults arise. The WS2812B devices D1-D10 are four-terminal addressable LED-drivers with explicitly numbered VDD/VSS/DIN/DOUT pins rather than simple diodes; their daisy-chained DOUT->DIN data path is intact from LED_DATA_IN through to LED_D9_DOUT and orientation follows the pin table, not a symbol graphic. No conducted-emissions concern is introduced on the 5V input because power arrives from the USB cable rather than a mains supply.
13.3  Findings
AI-Assisted —

ConnectorFindingSeverity

J3USB Type-C shell (SH) bonded to logic GND via dedicated net SHIELD_GND_TYPE_C and bond part NT2 — shield-bond intent captured per USB-C R2.5 Sec. 3.2.1; final direct-bond vs R||C isolation is enclosure-dependent (IEC 61000-4-2).Review
J3No TVS/ESD array on D+/D- or CC lines; port is user-mated and subject to IEC 61000-4-2 ±8 kV contact / ±15 kV air. Investigate a low-capacitance USB TVS array; RP2040 pads carry only device-level HBM rating.Review
J3No transient clamp on VBUS/5V input; consumer USB port. Investigate a VBUS clamp for hot-plug/ESD robustness (IEC 61000-4-2, CISPR 35).Review
J1Unshielded 13-pin GPIO/power expansion header, no series filtering or ESD clamp on GPIO0-GPIO10; if routed off-board the harness/mating assembly must provide protection (IEC 61000-4-2).Review
D1-D10WS2812B are four-terminal LED-driver ICs with numbered VDD/VSS/DIN/DOUT pins; daisy-chain DOUT->DIN intact, orientation per device datasheet pin table, not a diode polarity concern.Review
J3CC1/CC2 each present a 5.1k pull-down to GND (R2, R3) — correct Rd sink configuration per USB Type-C spec R2.5.
J3USB_DP/USB_DM carry 27-ohm series resistors (R6/R5) to U1 — matches Raspberry Pi RP2040 Hardware Design guide.
J35V rail from VBUS decoupled with 111µF total (1x100u + 1x10u + 10x100n) — adequate bulk/HF bypass, supports CISPR 32 emissions margin.
GeneralSingle logic GND with one deliberate star join (NT1 merges VREG_GND into GND) — clean single-point ground architecture, supports EMC (CISPR 32).
GeneralWS2812B data chain (D1-D10) damped by R1 330-ohm series at the buffer output; edge-rate control aids radiated-emission margin (CISPR 32/EN 55032).
GeneralCrystal X1 network (R11 1k series, C20/C21 15p) contains clock energy; internal source, no enclosure penetration.
GeneralAll capacitors are ceramic; no electrolytic/tantalum or directional TVS/zener parts — no polarity or orientation faults present.

14  Design-for-Test
Design for Testability (DFT) analysis for ICT/bed-of-nails test coverage.
14.1  DFx Options Selected

OptionSettingDescription

Test Point Insertion
Insert on power railsNoPlace test points on power rail nets in schematic
Insert on all netsNoExtend TP insertion to signal nets beyond power rails
Exclude HSSI netsYesExclude HSSI/differential pair nets from TP insertion
Exclude DRAM netsYesExclude SDRAM/DDR nets from TP insertion
Exclude BSCAN opens (full)YesExclude nets with 100% boundary scan opens coverage
Exclude BSCAN opens (partial)NoExclude nets with partial boundary scan opens coverage
Exclude BSCAN shortsNoExclude nets with boundary scan shorts coverage
GND test points6Number of GND test points to insert for BON fixture ground connections
Target PCOLA-SOQ0%Insert TPs in priority order until this PCOLA-SOQ % is reached
Target fault coverage0%Insert TPs in priority order until this shorts/opens fault coverage % is reached
Kelvin min resistance0.000 ohmLower bound (ohms) for Kelvin 4-wire TP insertion range
Kelvin max resistance1.000 ohmUpper bound (ohms) for Kelvin 4-wire TP insertion range
Tester Styles
OpticalAOIAutomated Optical Inspection of visible solder joints
AXIYesAutomated X-ray Inspection of hidden solder joints (BGA, QFN)
ATENoneNo automated test equipment
Test Access
JTAG/LSSI ConnectorNoConnector access to JTAG, SPI, I2C buses
IO ConnectorsYesIO connectors available for external stimulus/observation
TP AccessFlying_probeFlying probe access without fixture
Test Point Identification
BON TP refdesTP#,TP-*,TP_*,TP#*Refdes patterns identifying BON test points
BON TP footprints*All footprints accepted
FP TP refdesTP#,TP-*,TP_*,TP#*,MP#Refdes patterns identifying flying probe test points
FP TP footprints*All footprints accepted
LoopbackNoneNo loopback cables
Test Types
Powered-Off Shorts/OpensYesUnpowered shorts and opens detection via probe access
PassivesNoR, C, L value measurement via probe or fixture access
Active AnalogNoVoltage regulator, reference, and op-amp output verification
Non-BSCAN DigitalNoDigital ICs without boundary scan: pin observability analysis
Boundary ScanNoneNo boundary scan analysis
LSSINoJTAG chain, SPI, I2C, UART bus test coverage analysis
JTAG FunctionalNoFunctional verification beyond structural scan
Require Rail TPs for Diode TestNoRequire TPs on all IO power rails for ESD diode opens test (default: basic test with GND TP only)
Capacitance Probe Plate Target Devices—Refdes or footprint patterns for capacitance probe plate targets (ICs and vertical connectors)
Use Boundary Scan for Capacitance Probe Plate StimulusNoCount boundary scan drive cells on other devices as valid stimulus for the capacitance probe plate (applicable to VTEP / IEEE 1149.8.1-capable hardware)
NVM Programming
Default MethodDirectProgram via direct pin access; TPs on flash data/control lines
Environment
Test environmentlabPrototype/NPI: manual probing, bench JTAG, longer test times acceptable

14.2  Power Rail Test Point Check

Power rails found2
Rails with TPs2
Rails without TPs0

Power Rail Coverage

Net NameAnnotationTest PointStatus

5VTP1
GNDTP23

14.3  Kelvin Test Points Check

Threshold0.000 < R ≤ 1.000 Ω
Current sense resistors found0

No current sense resistors found in range (0 < R < 1.000 ohm).
14.4  Current Test Points

Total test points41

Test Points by Footprint

FootprintDescriptionCount

TPS127Tomachie_TP_E41

14.4.1  By Sheet

Test PointNet NameFootprint

Lamoka1-DEV-board (41 test points)
TP15VTPS127
TP2GNDTPS127
TP3GNDTPS127
TP43V3TPS127
TP51V1TPS127
TP6GPIO1TPS127
TP7GPIO2TPS127
TP8GPIO3TPS127
TP9GPIO4TPS127
TP10GPIO5TPS127
TP11GPIO6TPS127
TP12GPIO7TPS127
TP13GPIO8TPS127
TP14GPIO9TPS127
TP15GPIO10TPS127
TP16BTNTPS127
TP17XINTPS127
TP18XOUTTPS127
TP19USB_DMTPS127
TP20USB_DPTPS127
TP21USB_CONN_DPTPS127
TP22USB_CONN_DMTPS127
TP23GNDTPS127
TP24USB_CC2TPS127
TP25QSPI_SS_NTPS127
TP26RUN_NTPS127
TP27VREG_LXTPS127
TP28VREG_AVDDTPS127
TP29XTAL_RETURNTPS127
TP30LED_DATA_3V3TPS127
TP31LED_DATA_5V_BUFTPS127
TP32LED_DATA_INTPS127
TP33LED_D1_DOUTTPS127
TP34LED_D2_DOUTTPS127
TP35LED_D3_DOUTTPS127
TP36LED_D4_DOUTTPS127
TP37LED_D5_DOUTTPS127
TP38LED_D6_DOUTTPS127
TP39LED_D7_DOUTTPS127
TP40LED_D8_DOUTTPS127
TP41LED_D9_DOUTTPS127

14.4.2  All Test Points

Test PointNet NameSheetFootprint

TP15VLamoka1-DEV-boardTPS127
TP2GNDLamoka1-DEV-boardTPS127
TP3GNDLamoka1-DEV-boardTPS127
TP43V3Lamoka1-DEV-boardTPS127
TP51V1Lamoka1-DEV-boardTPS127
TP6GPIO1Lamoka1-DEV-boardTPS127
TP7GPIO2Lamoka1-DEV-boardTPS127
TP8GPIO3Lamoka1-DEV-boardTPS127
TP9GPIO4Lamoka1-DEV-boardTPS127
TP10GPIO5Lamoka1-DEV-boardTPS127
TP11GPIO6Lamoka1-DEV-boardTPS127
TP12GPIO7Lamoka1-DEV-boardTPS127
TP13GPIO8Lamoka1-DEV-boardTPS127
TP14GPIO9Lamoka1-DEV-boardTPS127
TP15GPIO10Lamoka1-DEV-boardTPS127
TP16BTNLamoka1-DEV-boardTPS127
TP17XINLamoka1-DEV-boardTPS127
TP18XOUTLamoka1-DEV-boardTPS127
TP19USB_DMLamoka1-DEV-boardTPS127
TP20USB_DPLamoka1-DEV-boardTPS127
TP21USB_CONN_DPLamoka1-DEV-boardTPS127
TP22USB_CONN_DMLamoka1-DEV-boardTPS127
TP23GNDLamoka1-DEV-boardTPS127
TP24USB_CC2Lamoka1-DEV-boardTPS127
TP25QSPI_SS_NLamoka1-DEV-boardTPS127
TP26RUN_NLamoka1-DEV-boardTPS127
TP27VREG_LXLamoka1-DEV-boardTPS127
TP28VREG_AVDDLamoka1-DEV-boardTPS127
TP29XTAL_RETURNLamoka1-DEV-boardTPS127
TP30LED_DATA_3V3Lamoka1-DEV-boardTPS127
TP31LED_DATA_5V_BUFLamoka1-DEV-boardTPS127
TP32LED_DATA_INLamoka1-DEV-boardTPS127
TP33LED_D1_DOUTLamoka1-DEV-boardTPS127
TP34LED_D2_DOUTLamoka1-DEV-boardTPS127
TP35LED_D3_DOUTLamoka1-DEV-boardTPS127
TP36LED_D4_DOUTLamoka1-DEV-boardTPS127
TP37LED_D5_DOUTLamoka1-DEV-boardTPS127
TP38LED_D6_DOUTLamoka1-DEV-boardTPS127
TP39LED_D7_DOUTLamoka1-DEV-boardTPS127
TP40LED_D8_DOUTLamoka1-DEV-boardTPS127
TP41LED_D9_DOUTLamoka1-DEV-boardTPS127

14.5  Powered-off Testing
40 nets with test points: 84 pins with opens coverage, 18 pins with partial opens, 182 pins with shorts coverage.
Open pin faults may be masked when two or more IC pins share a net (current flow through one internal pin ESD diode may mask the open on another).

Export to Excel

Powered-off Test Coverage by Net

Pin ⇅Net ⇅Type ⇅Opens ⇅Shorts ⇅

C15_11V1Capacitor-●
C19_11V1Capacitor-●
L1_21V1Passive●●
U1_61V1IC◐●
U1_231V1IC◐●
U1_391V1IC◐●
U1_501V1IC◐●
C13_13V3Capacitor-●
C14_13V3Capacitor-●
C17_13V3Capacitor-●
C18_13V3Capacitor-●
J1_123V3Connector-●
R4_13V3Passive●●
R8_13V3Passive●●
R9_13V3Passive●●
U1_13V3IC◐●
U1_113V3IC◐●
U1_203V3IC◐●
U1_303V3IC◐●
U1_383V3IC◐●
U1_443V3IC◐●
U1_453V3IC◐●
U1_493V3IC◐●
U1_533V3IC◐●
U1_543V3IC◐●
U2_23V3IC◐●
U2_43V3IC◐●
C1_15VCapacitor-●
C2_15VCapacitor-●
C3_15VCapacitor-●
C4_15VCapacitor-●
C5_15VCapacitor-●
C6_15VCapacitor-●
C7_15VCapacitor-●
C8_15VCapacitor-●
C9_15VCapacitor-●
C10_15VCapacitor-●
C11_15VCapacitor-●
C12_25VCapacitor-●
D1_15VPassive●●
D2_15VPassive●●
D3_15VPassive●●
D4_15VPassive●●
D5_15VPassive●●
D6_15VPassive●●
D7_15VPassive●●
D8_15VPassive●●
D9_15VPassive●●
D10_15VPassive-●
J1_135VConnector-●
J3_A45VConnector-●
J3_A95VConnector-●
J3_B45VConnector-●
J3_B95VConnector-●
U2_35VIC-●
U3_55VIC-●
R7_1BTNPassive●●
R9_2BTNPassive●●
SW1_1BTNPassive●●
U1_2BTNIC●●
C1_2GNDCapacitor-●
C2_2GNDCapacitor-●
C3_2GNDCapacitor-●
C4_2GNDCapacitor-●
C5_2GNDCapacitor-●
C6_2GNDCapacitor-●
C7_2GNDCapacitor-●
C8_2GNDCapacitor-●
C9_2GNDCapacitor-●
C10_2GNDCapacitor-●
C11_2GNDCapacitor-●
C12_1GNDCapacitor-●
C13_2GNDCapacitor-●
C14_2GNDCapacitor-●
C15_2GNDCapacitor-●
C16_2GNDCapacitor-●
C17_2GNDCapacitor-●
C18_2GNDCapacitor-●
C19_2GNDCapacitor-●
C20_2GNDCapacitor-●
C21_2GNDCapacitor-●
D1_3GNDPassive●●
D2_3GNDPassive●●
D3_3GNDPassive●●
D4_3GNDPassive●●
D5_3GNDPassive●●
D6_3GNDPassive●●
D7_3GNDPassive●●
D8_3GNDPassive●●
D9_3GNDPassive●●
D10_3GNDPassive-●
J1_11GNDConnector-●
J3_A1GNDConnector-●
J3_A12GNDConnector-●
J3_B1GNDConnector-●
J3_B12GNDConnector-●
NT1_1GNDPassive●●
NT1_2GNDPassive●●
NT2_2GNDPassive-●
R2_2GNDPassive-●
R3_2GNDPassive●●
SW1_2GNDPassive●●
U1_47GNDIC-●
U1_61GNDIC-●
U2_1GNDIC-●
U3_1GNDIC-●
U3_3GNDIC-●
X1_2GNDPassive●●
X1_4GNDPassive●●
J1_1GPIO1Connector-●
U1_3GPIO1IC●●
J1_10GPIO10Connector-●
U1_14GPIO10IC●●
J1_2GPIO2Connector-●
U1_4GPIO2IC●●
J1_3GPIO3Connector-●
U1_5GPIO3IC●●
J1_4GPIO4Connector-●
U1_7GPIO4IC●●
J1_5GPIO5Connector-●
U1_8GPIO5IC●●
J1_6GPIO6Connector-●
U1_9GPIO6IC●●
J1_7GPIO7Connector-●
U1_10GPIO7IC●●
J1_8GPIO8Connector-●
U1_12GPIO8IC●●
J1_9GPIO9Connector-●
U1_13GPIO9IC●●
D1_2LED_D1_DOUTPassive●●
D2_4LED_D1_DOUTPassive●●
D2_2LED_D2_DOUTPassive●●
D3_4LED_D2_DOUTPassive●●
D3_2LED_D3_DOUTPassive●●
D4_4LED_D3_DOUTPassive●●
D4_2LED_D4_DOUTPassive●●
D5_4LED_D4_DOUTPassive●●
D5_2LED_D5_DOUTPassive●●
D6_4LED_D5_DOUTPassive●●
D6_2LED_D6_DOUTPassive●●
D7_4LED_D6_DOUTPassive●●
D7_2LED_D7_DOUTPassive●●
D8_4LED_D7_DOUTPassive●●
D8_2LED_D8_DOUTPassive●●
D9_4LED_D8_DOUTPassive●●
D9_2LED_D9_DOUTPassive●●
D10_4LED_D9_DOUTPassive-●
U1_15LED_DATA_3V3IC◐●
U3_2LED_DATA_3V3IC◐●
R1_2LED_DATA_5V_BUFPassive●●
U3_4LED_DATA_5V_BUFIC●●
D1_4LED_DATA_INPassive●●
R1_1LED_DATA_INPassive●●
R7_2QSPI_SS_NPassive●●
U1_60QSPI_SS_NIC●●
R8_2RUN_NPassive●●
U1_26RUN_NIC●●
J3_B5USB_CC2Connector-●
R3_1USB_CC2Passive●●
J3_A7USB_CONN_DMConnector-●
J3_B7USB_CONN_DMConnector-●
R5_1USB_CONN_DMPassive●●
J3_A6USB_CONN_DPConnector-●
J3_B6USB_CONN_DPConnector-●
R6_1USB_CONN_DPPassive●●
R5_2USB_DMPassive●●
U1_51USB_DMIC●●
R6_2USB_DPPassive●●
U1_52USB_DPIC●●
C16_1VREG_AVDDCapacitor-●
R4_2VREG_AVDDPassive●●
U1_46VREG_AVDDIC●●
L1_1VREG_LXPassive●●
U1_48VREG_LXIC●●
C21_1XINCapacitor-●
U1_21XINIC●●
X1_1XINPassive●●
R11_2XOUTPassive●●
U1_22XOUTIC●●
C20_1XTAL_RETURNCapacitor-●
R11_1XTAL_RETURNPassive●●
X1_3XTAL_RETURNPassive●●

14.6  Inspection
Total: 49 components, 202 of 208 pins with inspection coverage.
14.6.1  AOI

Assumed Classification (Non-IPC Footprints)
Footprint names are not IPC-7351B or IPC-7251. Package type inferred from Pkg Type property or designator prefix. Classification may be incorrect.

FootprintSize (mil)Pkg TypeClassificationMethodCountPinsRefdes

Opens + Shorts (all joints visible)
Package_TO_SOT_SMD
SOT-23-5SOT (Small Outline Transistor)Footprint15U3
components
SOT-223_UMWSOT (Small Outline Transistor)Footprint14U2
Capacitor_SMD
C_0402_1005MetricChip PassiveDesignator24C20, C21
C_1206_3216MetricChip PassiveDesignator12C11
Resistor_SMD
R_0603_1608MetricChip PassiveDesignator48R1, R4, R5, R6
components
AOTAB201610S3R3101TChip PassiveDesignator12L1
CAP_0402_SAMChip PassiveDesignator1326C1, C10, C17, C18, C19, C2, C3, C4 ...+5 more
CAP_0603_CL10A_1P6XP8_SAMChip PassiveDesignator36C14, C15, C16
CAP_CL_05_SAMChip PassiveDesignator24C12, C13
RC0402N_PANChip PassiveDesignator24R11, R7
RC0603N_YAGChip PassiveDesignator24R2, R3
RES_CRCW_0603Chip PassiveDesignator24R8, R9
LED_SMD
LED_WS2812B_PLCC4_5.0x5.0mm_P3.2mmSOD (Diode Package)Designator1040D1, D10, D2, D3, D4, D5, D6, D7 ...+2 more
Subtotal: 44 components, 113 pins
Presence check (manual verification)
Connector_PinHeader_2.54mm
PinHeader_1x13_P2.54mm_VerticalConnectorDesignator113J1
Connector_USB
USB_C_Receptacle_HRO_TYPE-C-31-M-12ConnectorDesignator115J3
Subtotal: 2 components, 28 pins

14.6.2  AXI

Assumed Classification (Non-IPC Footprints)
Hidden-joint classification inferred from Pkg Type property or designator prefix. Footprint names are not IPC-7351B or IPC-7251.

FootprintSize (mil)Pkg TypeClassificationMethodCountPinsRefdes

Package_DFN_QFN
QFN-60-1EP_7x7mm_P0.4mm_EP3.4x3.4mmQFN/DFN (No-Lead)Footprint161U1
Subtotal: 1 components, 61 pins

14.6.3  Unclassified Components

These components could not be classified for inspection. The library model lacks a Pkg Type property and the footprint name is not IPC-7351B or IPC-7251.

FootprintSize (mil)Pkg TypeClassificationMethodCountPinsRefdes

components
ABM8-272-T3_ABROscillator / CrystalDesignator14X1
SW_PTS636_CNKUnclassifiedUnknown12SW1
Subtotal: 2 components, 6 pins

14.7  Pin Fault Coverage
Predicted status of each pin for shorts and opens based on DFx options selected in section 13.1.
14.7.1  Fault Coverage Summary

Fault Coverage Summary (212 pins)

Test MethodOpensShorts

X-ray (AXI)0 (0.0%)0 (0.0%)
Optical (AOI)0 (0.0%)0 (0.0%)
Electrical
   Powered-off Testing89 (42.0%)182 (85.8%)
   Boundary Scan--
   LSSI--
   Total89 (42.0%)182 (85.8%)
Total Fault Coverage89 (42.0%)182 (85.8%)
No coverage123 (58.0%)30 (14.2%)

14.7.2  Uncovered Pins (30)

Export to Excel

These pins have no electrical, optical, or X-ray test coverage even with all available test techniques applied.

Pin ⇅Net ⇅

R2_1Net-(J3-CC1)
J3_SHSHIELD_GND_TYPE_C
J3_A5Net-(J3-CC1)
D10_2
U1_27
U1_28
U1_25
U1_24
U1_19
U1_18
U1_17
U1_55
U1_16
U1_56
U1_57
U1_35
U1_58
U1_59
U1_29
U1_43
U1_42
U1_41
U1_40
U1_31
U1_32
U1_33
U1_34
U1_36
U1_37
NT2_1SHIELD_GND_TYPE_C

14.7.3  Per-Pin Coverage Matrix
● = Detected  ◐ = Partially detected  - = Not tested   |   E = Electrical (ICT/flying probe)  O = Optical (AOI)  X = X-ray (AXI)

Export to Excel

Pin ⇅Net ⇅E Opens ⇅E Shorts ⇅O Opens ⇅O Shorts ⇅X Opens ⇅X Shorts ⇅

D6_15V●●----
D6_3GND●●----
D6_2LED_D6_DOUT●●----
D6_4LED_D5_DOUT●●----
D5_15V●●----
D5_3GND●●----
D5_2LED_D5_DOUT●●----
D5_4LED_D4_DOUT●●----
R2_1Net-(J3-CC1)------
R2_2GND-●----
D8_15V●●----
D8_3GND●●----
D8_2LED_D8_DOUT●●----
D8_4LED_D7_DOUT●●----
J3_B12GND-●----
J3_SHSHIELD_GND_TYPE_C------
J3_A12GND-●----
J3_B45V-●----
J3_A95V-●----
J3_B1GND-●----
J3_B95V-●----
J3_B7USB_CONN_DM-●----
J3_B6USB_CONN_DP-●----
J3_B5USB_CC2-●----
J3_A5Net-(J3-CC1)------
J3_A7USB_CONN_DM-●----
J3_A45V-●----
J3_A6USB_CONN_DP-●----
J3_A1GND-●----
C4_15V-●----
C4_2GND-●----
C2_15V-●----
C2_2GND-●----
D3_15V●●----
D3_3GND●●----
D3_2LED_D3_DOUT●●----
D3_4LED_D2_DOUT●●----
C11_15V-●----
C11_2GND-●----
SW1_2GND●●----
SW1_1BTN●●----
C14_13V3-●----
C14_2GND-●----
L1_1VREG_LX●●----
L1_21V1●●----
D2_15V●●----
D2_3GND●●----
D2_2LED_D2_DOUT●●----
D2_4LED_D1_DOUT●●----
R8_2RUN_N●●----
R8_13V3●●----
R1_2LED_DATA_5V_BUF●●----
R1_1LED_DATA_IN●●----
C1_15V-●----
C1_2GND-●----
R7_2QSPI_SS_N●●----
R7_1BTN●●----
D10_15V-●----
D10_3GND-●----
D10_2------
D10_4LED_D9_DOUT-●----
R9_2BTN●●----
R9_13V3●●----
C15_11V1-●----
C15_2GND-●----
D4_15V●●----
D4_3GND●●----
D4_2LED_D4_DOUT●●----
D4_4LED_D3_DOUT●●----
D1_15V●●----
D1_3GND●●----
D1_2LED_D1_DOUT●●----
D1_4LED_DATA_IN●●----
U1_453V3-●----
U1_26RUN_N●●----
U1_27------
U1_28------
U1_48VREG_LX●●----
U1_12GPIO8●●----
U1_25------
U1_493V3-●----
U1_24------
U1_231V1-●----
U1_501V1-●----
U1_22XOUT●●----
U1_51USB_DM●●----
U1_21XIN●●----
U1_203V3-●----
U1_19------
U1_52USB_DP●●----
U1_18------
U1_17------
U1_55------
U1_16------
U1_56------
U1_15LED_DATA_3V3-●----
U1_57------
U1_14GPIO10●●----
U1_13GPIO9●●----
U1_35------
U1_58------
U1_59------
U1_443V3-●----
U1_60QSPI_SS_N●●----
U1_29------
U1_61GND-●----
U1_43------
U1_42------
U1_41------
U1_40------
U1_113V3-●----
U1_9GPIO6●●----
U1_10GPIO7●●----
U1_31------
U1_4GPIO2●●----
U1_5GPIO3●●----
U1_303V3-●----
U1_391V1-●----
U1_46VREG_AVDD●●----
U1_543V3-●----
U1_13V3-●----
U1_32------
U1_383V3-●----
U1_61V1-●----
U1_33------
U1_34------
U1_36------
U1_47GND-●----
U1_533V3-●----
U1_2BTN●●----
U1_3GPIO1●●----
U1_7GPIO4●●----
U1_8GPIO5●●----
U1_37------
C7_15V-●----
C7_2GND-●----
R3_1USB_CC2●●----
R3_2GND●●----
NT1_1GND●●----
NT1_2GND●●----
C3_15V-●----
C3_2GND-●----
R6_2USB_DP●●----
R6_1USB_CONN_DP●●----
D9_15V●●----
D9_3GND●●----
D9_2LED_D9_DOUT●●----
D9_4LED_D8_DOUT●●----
C21_1XIN-●----
C21_2GND-●----
C13_13V3-●----
C13_2GND-●----
U3_3GND●●----
U3_4LED_DATA_5V_BUF●●----
U3_55V●●----
U3_1GND●●----
U3_2LED_DATA_3V3-●----
C8_15V-●----
C8_2GND-●----
D7_15V●●----
D7_3GND●●----
D7_2LED_D7_DOUT●●----
D7_4LED_D6_DOUT●●----
J1_3GPIO3-●----
J1_1GPIO1-●----
J1_2GPIO2-●----
J1_6GPIO6-●----
J1_135V-●----
J1_123V3-●----
J1_8GPIO8-●----
J1_9GPIO9-●----
J1_10GPIO10-●----
J1_11GND-●----
J1_5GPIO5-●----
J1_4GPIO4-●----
J1_7GPIO7-●----
C6_15V-●----
C6_2GND-●----
R11_2XOUT●●----
R11_1XTAL_RETURN●●----
R5_2USB_DM●●----
R5_1USB_CONN_DM●●----
C19_2GND-●----
C19_11V1-●----
C5_15V-●----
C5_2GND-●----
C12_1GND-●----
C12_25V-●----
C16_1VREG_AVDD-●----
C16_2GND-●----
C9_15V-●----
C9_2GND-●----
U2_43V3-●----
U2_35V●●----
U2_23V3-●----
U2_1GND●●----
R4_13V3●●----
R4_2VREG_AVDD●●----
C20_1XTAL_RETURN-●----
C20_2GND-●----
C18_2GND-●----
C18_13V3-●----
X1_2GND●●----
X1_4GND●●----
X1_1XIN●●----
X1_3XTAL_RETURN●●----
C17_2GND-●----
C17_13V3-●----
C10_15V-●----
C10_2GND-●----
NT2_1SHIELD_GND_TYPE_C------
NT2_2GND-●----

14.8  PCOLA/SOQ Fault Coverage
PCOLA/SOQ scores how well the configured test methods cover each component and each connection. PCOLA evaluates five device-level properties: Presence, Correctness, Orientation, Live (functional), and Alignment. SOQ evaluates three connection-level properties: Shorts detection, Opens detection, and solder joint Quality. Scores are on a 0–100,000 scale where 100,000 means every property is fully covered. The Combined score is the average of PCOLA and SOQ.
14.8.1  Coverage by Test Method
P=Presence  C=Correctness  O=Orientation  L=Live  A=Alignment  |  S=Shorts  O(pins)=Opens  Q=Quality

PCOLA/SOQ coverage scores by test method. Scores: 0 (None), 0.5 (Partial), 1.0 (Full).

Test MethodPCOLASOpensSolder Quality

Electrical Test81.6%63.3%0.0%0.0%0.0%43.0%41.8%0.0%
Optical Inspection (AOI)0.0%0.0%0.0%0.0%0.0%0.0%0.0%0.0%
X-Ray Inspection (AXI)0.0%0.0%0.0%0.0%0.0%0.0%0.0%0.0%
Combined81.6%63.3%0.0%0.0%0.0%43.0%41.8%0.0%

14.8.2  PCB Device/Pin Count
Devices (PCOLA): 49Pins (SOQ): 208
14.8.3  Board-Level Scores

Board-Level Coverage (0 – 100,000 scale)

DimensionScoreCoverage

PCOLA28980 / 100,00029.0%
SOQ28285 / 100,00028.3%
Combined28632 / 100,00028.6%

Electrical vs Inspection

SourcePCOLA ScoreSOQ Score

Electrical Test28980 / 100,00028285 / 100,000
Optical/X-ray Inspection0 / 100,0000 / 100,000
Combined (max)28980 / 100,00028285 / 100,000

14.8.4  PCOLA (49 devices)
● = Full (1.0)   ◐ = Partial (0.5)   ○ = None (0)   — = N/A (excluded)* Footprint not IPC-7351B/7251 compliant — no inspection coverage scored

Export to Excel

Score ⇅RefDes ⇅Type / Footprint ⇅Class ⇅P ⇅C ⇅O ⇅L ⇅A ⇅Method ⇅

40%C2100n / CAP_0402_SAM *Capacitor●●○—○Passive_Meas, Powered_Off
40%R111k / RC0402N_PAN *Resistor●●○—○Passive_Meas, Powered_Off
40%R527 / R_0603_1608Metric *Resistor●●○—○Passive_Meas, Powered_Off
40%C19100n / CAP_0402_SAM *Capacitor●●○—○Passive_Meas, Powered_Off
40%C5100n / CAP_0402_SAM *Capacitor●●○—○Passive_Meas, Powered_Off
40%C4100n / CAP_0402_SAM *Capacitor●●○—○Passive_Meas, Powered_Off
40%R35.1k / RC0603N_YAG *Resistor●●○—○Passive_Meas, Powered_Off
40%C1210u / CAP_CL_05_SAM *Capacitor●●○—○Passive_Meas, Powered_Off
40%C11100u / C_1206_3216Metric *Capacitor●●○—○Passive_Meas, Powered_Off
40%C164.7u / CAP_0603_CL10A_1P6XP8_SAM *Capacitor●●○—○Passive_Meas, Powered_Off
40%C144.7u / CAP_0603_CL10A_1P6XP8_SAM *Capacitor●●○—○Passive_Meas, Powered_Off
40%L13.3u / AOTAB201610S3R3101T *Inductor●●○—○Passive_Meas, Powered_Off
40%C9100n / CAP_0402_SAM *Capacitor●●○—○Passive_Meas, Powered_Off
40%R810k / RES_CRCW_0603 *Resistor●●○—○Passive_Meas, Powered_Off
40%R1330 / R_0603_1608Metric *Resistor●●○—○Passive_Meas, Powered_Off
40%C1100n / CAP_0402_SAM *Capacitor●●○—○Passive_Meas, Powered_Off
40%R71k / RC0402N_PAN *Resistor●●○—○Passive_Meas, Powered_Off
40%R433 / R_0603_1608Metric *Resistor●●○—○Passive_Meas, Powered_Off
40%R910k / RES_CRCW_0603 *Resistor●●○—○Passive_Meas, Powered_Off
40%C154.7u / CAP_0603_CL10A_1P6XP8_SAM *Capacitor●●○—○Passive_Meas, Powered_Off
40%C2015p / C_0402_1005Metric *Capacitor●●○—○Passive_Meas, Powered_Off
40%C18100n / CAP_0402_SAM *Capacitor●●○—○Passive_Meas, Powered_Off
40%C17100n / CAP_0402_SAM *Capacitor●●○—○Passive_Meas, Powered_Off
40%C7100n / CAP_0402_SAM *Capacitor●●○—○Passive_Meas, Powered_Off
40%C10100n / CAP_0402_SAM *Capacitor●●○—○Passive_Meas, Powered_Off
40%C3100n / CAP_0402_SAM *Capacitor●●○—○Passive_Meas, Powered_Off
40%R627 / R_0603_1608Metric *Resistor●●○—○Passive_Meas, Powered_Off
40%C2115p / C_0402_1005Metric *Capacitor●●○—○Passive_Meas, Powered_Off
40%C1310u / CAP_CL_05_SAM *Capacitor●●○—○Passive_Meas, Powered_Off
40%C8100n / CAP_0402_SAM *Capacitor●●○—○Passive_Meas, Powered_Off
40%C6100n / CAP_0402_SAM *Capacitor●●○—○Passive_Meas, Powered_Off
10%D5WS2812B / LED_WS2812B_PLCC4_5.0x5.0mm_P3.2mm *Diode◐○○○○Powered_Off
10%R25.1k / RC0603N_YAG *Resistor◐○○—○Powered_Off
10%D8WS2812B / LED_WS2812B_PLCC4_5.0x5.0mm_P3.2mm *Diode◐○○○○Powered_Off
10%J3USB_C_Receptacle_USB2.0_14P / USB_C_Receptacle_HRO_TYPE-C-31-M-12 *Connector◐○○—○Powered_Off
10%D3WS2812B / LED_WS2812B_PLCC4_5.0x5.0mm_P3.2mm *Diode◐○○○○Powered_Off
10%SW1PTS636 SM43J SMTR LFS / SW_PTS636_CNK *Switch◐○○○○Powered_Off
10%D2WS2812B / LED_WS2812B_PLCC4_5.0x5.0mm_P3.2mm *Diode◐○○○○Powered_Off
10%D10WS2812B / LED_WS2812B_PLCC4_5.0x5.0mm_P3.2mm *Diode◐○○○○Powered_Off
10%D4WS2812B / LED_WS2812B_PLCC4_5.0x5.0mm_P3.2mm *Diode◐○○○○Powered_Off
10%D1WS2812B / LED_WS2812B_PLCC4_5.0x5.0mm_P3.2mm *Diode◐○○○○Powered_Off
10%U1RP2354A / QFN-60-1EP_7x7mm_P0.4mm_EP3.4x3.4mm *IC◐○○○○Powered_Off
10%D6WS2812B / LED_WS2812B_PLCC4_5.0x5.0mm_P3.2mm *Diode◐○○○○Powered_Off
10%U374AHCT1G125 / SOT-23-5 *IC◐○○○○Powered_Off
10%D9WS2812B / LED_WS2812B_PLCC4_5.0x5.0mm_P3.2mm *Diode◐○○○○Powered_Off
10%D7WS2812B / LED_WS2812B_PLCC4_5.0x5.0mm_P3.2mm *Diode◐○○○○Powered_Off
10%X1ABM8-272-T3 / ABM8-272-T3_ABR *Oscillator◐○○○○Powered_Off
10%J1Conn_01x13_Pin / PinHeader_1x13_P2.54mm_Vertical *Connector◐○○—○Powered_Off
10%U2AMS1117-3.3 / SOT-223_UMW *IC◐○○○○Powered_Off

14.8.5  SOQ (208 pins)
● = Full (1.0)   ◐ = Partial (0.5)   ○ = None (0)

Export to Excel

Score ⇅Pin ⇅Net ⇅S ⇅O ⇅Q ⇅

50%D6_15V◐●○
50%D6_3GND◐●○
50%D6_2LED_D6_DOUT◐●○
50%D6_4LED_D5_DOUT◐●○
50%D5_15V◐●○
50%D5_3GND◐●○
50%D5_2LED_D5_DOUT◐●○
50%D5_4LED_D4_DOUT◐●○
50%D7_4LED_D6_DOUT◐●○
50%R11_2XOUT◐●○
50%D8_15V◐●○
50%D8_3GND◐●○
50%D8_2LED_D8_DOUT◐●○
50%D8_4LED_D7_DOUT◐●○
50%U1_52USB_DP◐●○
50%R11_1XTAL_RETURN◐●○
50%R5_2USB_DM◐●○
50%R5_1USB_CONN_DM◐●○
50%U2_35V◐●○
50%U2_1GND◐●○
50%R4_13V3◐●○
50%R4_2VREG_AVDD◐●○
50%U1_14GPIO10◐●○
50%U1_13GPIO9◐●○
50%X1_2GND◐●○
50%X1_4GND◐●○
50%R1_1LED_DATA_IN◐●○
50%X1_1XIN◐●○
50%X1_3XTAL_RETURN◐●○
50%U1_60QSPI_SS_N◐●○
50%U1_3GPIO1◐●○
50%U1_9GPIO6◐●○
50%U1_10GPIO7◐●○
50%D3_15V◐●○
50%D3_3GND◐●○
50%D3_2LED_D3_DOUT◐●○
50%D3_4LED_D2_DOUT◐●○
50%U1_4GPIO2◐●○
50%U1_5GPIO3◐●○
50%SW1_2GND◐●○
50%SW1_1BTN◐●○
50%U1_46VREG_AVDD◐●○
50%U1_2BTN◐●○
50%L1_1VREG_LX◐●○
50%L1_21V1◐●○
50%D2_15V◐●○
50%D2_3GND◐●○
50%D2_2LED_D2_DOUT◐●○
50%D2_4LED_D1_DOUT◐●○
50%R8_2RUN_N◐●○
50%R8_13V3◐●○
50%R1_2LED_DATA_5V_BUF◐●○
50%U1_7GPIO4◐●○
50%U1_8GPIO5◐●○
50%R3_1USB_CC2◐●○
50%R7_2QSPI_SS_N◐●○
50%R7_1BTN◐●○
50%R3_2GND◐●○
50%R6_2USB_DP◐●○
50%R6_1USB_CONN_DP◐●○
50%D9_15V◐●○
50%R9_2BTN◐●○
50%R9_13V3◐●○
50%D9_3GND◐●○
50%D9_2LED_D9_DOUT◐●○
50%D4_15V◐●○
50%D4_3GND◐●○
50%D4_2LED_D4_DOUT◐●○
50%D4_4LED_D3_DOUT◐●○
50%D1_15V◐●○
50%D1_3GND◐●○
50%D1_2LED_D1_DOUT◐●○
50%D1_4LED_DATA_IN◐●○
50%D9_4LED_D8_DOUT◐●○
50%U1_26RUN_N◐●○
50%U3_3GND◐●○
50%U3_4LED_DATA_5V_BUF◐●○
50%U1_48VREG_LX◐●○
50%U1_12GPIO8◐●○
50%U3_55V◐●○
50%U3_1GND◐●○
50%D7_15V◐●○
50%D7_3GND◐●○
50%D7_2LED_D7_DOUT◐●○
50%U1_22XOUT◐●○
50%U1_51USB_DM◐●○
50%U1_21XIN◐●○
17%J3_A1GND◐○○
17%R2_2GND◐○○
17%J3_B12GND◐○○
17%C12_25V◐○○
17%J3_A12GND◐○○
17%J3_B45V◐○○
17%J3_A95V◐○○
17%J3_B1GND◐○○
17%J3_B95V◐○○
17%J3_B7USB_CONN_DM◐○○
17%J3_B6USB_CONN_DP◐○○
17%J3_B5USB_CC2◐○○
17%C16_1VREG_AVDD◐○○
17%J3_A7USB_CONN_DM◐○○
17%J3_A6USB_CONN_DP◐○○
17%D10_4LED_D9_DOUT◐○○
17%C4_15V◐○○
17%C4_2GND◐○○
17%C2_15V◐○○
17%C2_2GND◐○○
17%C11_15V◐○○
17%C11_2GND◐○○
17%C14_13V3◐○○
17%C14_2GND◐○○
17%J3_A45V◐○○
17%C1_15V◐○○
17%C1_2GND◐○○
17%D10_15V◐○○
17%D10_3GND◐○○
17%C16_2GND◐○○
17%C9_15V◐○○
17%C15_11V1◐○○
17%C15_2GND◐○○
17%U1_453V3◐○○
17%C9_2GND◐○○
17%U2_43V3◐○○
17%C10_2GND◐○○
17%U1_493V3◐○○
17%C7_15V◐○○
17%U1_231V1◐○○
17%U1_501V1◐○○
17%U1_203V3◐○○
17%C7_2GND◐○○
17%C20_1XTAL_RETURN◐○○
17%C20_2GND◐○○
17%C21_2GND◐○○
17%C18_2GND◐○○
17%C18_13V3◐○○
17%U1_15LED_DATA_3V3◐○○
17%C3_15V◐○○
17%C3_2GND◐○○
17%C17_2GND◐○○
17%C17_13V3◐○○
17%U1_443V3◐○○
17%U1_303V3◐○○
17%U1_391V1◐○○
17%C10_15V◐○○
17%U1_543V3◐○○
17%U1_13V3◐○○
17%C21_1XIN◐○○
17%J1_1GPIO1◐○○
17%C13_13V3◐○○
17%C13_2GND◐○○
17%U1_383V3◐○○
17%U1_61V1◐○○
17%U3_2LED_DATA_3V3◐○○
17%C8_15V◐○○
17%C8_2GND◐○○
17%U1_47GND◐○○
17%U1_533V3◐○○
17%J1_3GPIO3◐○○
17%J1_2GPIO2◐○○
17%J1_6GPIO6◐○○
17%J1_135V◐○○
17%J1_123V3◐○○
17%J1_8GPIO8◐○○
17%J1_9GPIO9◐○○
17%J1_10GPIO10◐○○
17%J1_11GND◐○○
17%J1_5GPIO5◐○○
17%J1_4GPIO4◐○○
17%J1_7GPIO7◐○○
17%C6_15V◐○○
17%C6_2GND◐○○
17%U1_113V3◐○○
17%U2_23V3◐○○
17%U1_61GND◐○○
17%C19_2GND◐○○
17%C19_11V1◐○○
17%C5_15V◐○○
17%C5_2GND◐○○
17%C12_1GND◐○○
0%J3_SHSHIELD_GND_TYPE_C○○○
0%J3_A5Net-(J3-CC1)○○○
0%D10_2○○○
0%R2_1Net-(J3-CC1)○○○
0%U1_27○○○
0%U1_28○○○
0%U1_25○○○
0%U1_24○○○
0%U1_19○○○
0%U1_18○○○
0%U1_17○○○
0%U1_16○○○
0%U1_56○○○
0%U1_57○○○
0%U1_35○○○
0%U1_58○○○
0%U1_59○○○
0%U1_40○○○
0%U1_55○○○
0%U1_36○○○
0%U1_37○○○
0%U1_42○○○
0%U1_43○○○
0%U1_33○○○
0%U1_41○○○
0%U1_32○○○
0%U1_31○○○
0%U1_34○○○
0%U1_29○○○

14.8.6  Scoring Matrix
PCOLA/SOQ scoring premises used for this analysis. Each cell shows the score assigned when a test method applies to a component or pin.

MethodPCOLASOpensQ

AOIFullFullFull—PartialPartialPartialPartial
AXI————PartialPartialPartialPartial
JTAG/BSCANFullFullFullPartial—FullFull—
BSCAN_PassivesFullFullFullFull—FullFull—
I2CPartialPartial—Partial—PartialPartial—
SPIPartialPartial—Partial—PartialPartial—
UART———Partial————
Passive_MeasFullFullFullFull—FullFull—
Powered_OffPartial————PartialFull—

15  Component Properties
Schematic symbol and library model quality analysis.
15.1  Library Model Grades
Grading schematic library model quality based on pin electrical type definitions:

Grade Definitions

GradeRatingDescription

AExcellentHas Power pins AND properly typed I/O pins (>=90% typed)
BGood>=70% typed OR (>=50% typed AND has Power)
CFairMix of typed and Passive pins (>=40% typed)
DPoorMostly Passive with few typed pins (>=10% typed)
FFailAll pins Passive/Unknown (<10% typed, no ERC)

IC Library Model Grades (sorted worst to best)

RefDesGrdPinsPwrInOutIOOCOEHiZPasPart NumberCreator

U1C611033370008RP2354A
U2B420200000AMS1117-3.3
U3A52200001074AHCT1G125

15.1.1  Library Quality Summary

Total ICs evaluated3
Grade A (excellent)1 (33.3%)
Grade B (good)1 (33.3%)
Grade C (fair)1 (33.3%)
Grade D (poor)0 (0.0%)
Grade F (fail)0 (0.0%)
OVERALL LIBRARY QUALITYA (3.60/4.00)

15.2  Component Library Validation
Checking for generic/incomplete library models using statistical patterns.

Library Model Issues (2 models)

Library NameIndustry NamePart NumberRefDesPinsDistributionIssues

AMS1117-3.3AMS1117-3.3-U24Pwr:2 O:2 Power-named pins not typed as Power - library pin types incomplete [VOUT=Output, VOUT=Output]
RP2354ASC1511-A4-U161P:8 Pwr:10 Bi:37 I:3 O:3 Pin 45 (IOVDD) at same location as pin 20 (IOVDD); Pin 45 (IOVDD) at same location as pin 11 (IOVDD); Pin 45 (IOVDD) at same location as pin 30 (IOVDD); Pin 45 (IOVDD) at same location as pin 1 (IOVDD); Pin 45 (IOVDD) at same location as pin 38 (IOVDD); Pin 23 (DVDD) at same location as pin 39 (DVDD); Pin 23 (DVDD) at same location as pin 6 (DVDD); Pin 20 (IOVDD) at same location as pin 11 (IOVDD); Pin 20 (IOVDD) at same location as pin 30 (IOVDD); Pin 20 (IOVDD) at same location as pin 1 (IOVDD); Pin 20 (IOVDD) at same location as pin 38 (IOVDD); Pin 11 (IOVDD) at same location as pin 30 (IOVDD); Pin 11 (IOVDD) at same location as pin 1 (IOVDD); Pin 11 (IOVDD) at same location as pin 38 (IOVDD); Pin 30 (IOVDD) at same location as pin 1 (IOVDD); Pin 30 (IOVDD) at same location as pin 38 (IOVDD); Pin 39 (DVDD) at same location as pin 6 (DVDD); Pin 1 (IOVDD) at same location as pin 38 (IOVDD); Power-named pins not typed as Power - library pin types incomplete [DVDD=Passive, VREG_FB=Passive, DVDD=Passive]

15.2.1  Validation Heuristics
All pins same type: Generic library with no electrical rules
High % passive pins on IC: Incomplete type information
No power pins: May indicate separate power symbol
Low type diversity: Very underspecified library model
Power-named pins not typed as Power: Library pin types incomplete
15.3  Shielded Connector Model Quality

Shielded connectors with missing pin names0

All shielded connectors have proper pin names for EMC analysis.
15.4  Footprints and Other Models

Components with model data57

Component Model Assignments

RefDesIndustry NamePinsModel TypeModel

D1TZ-5050S2RGB-5V-I4-H14FootprintLED_SMD:LED_WS2812B_PLCC4_5.0x5.0mm_P3.2mm
D2TZ-5050S2RGB-5V-I4-H14FootprintLED_SMD:LED_WS2812B_PLCC4_5.0x5.0mm_P3.2mm
D3TZ-5050S2RGB-5V-I4-H14FootprintLED_SMD:LED_WS2812B_PLCC4_5.0x5.0mm_P3.2mm
D4TZ-5050S2RGB-5V-I4-H14FootprintLED_SMD:LED_WS2812B_PLCC4_5.0x5.0mm_P3.2mm
D5TZ-5050S2RGB-5V-I4-H14FootprintLED_SMD:LED_WS2812B_PLCC4_5.0x5.0mm_P3.2mm
D6TZ-5050S2RGB-5V-I4-H14FootprintLED_SMD:LED_WS2812B_PLCC4_5.0x5.0mm_P3.2mm
D7TZ-5050S2RGB-5V-I4-H14FootprintLED_SMD:LED_WS2812B_PLCC4_5.0x5.0mm_P3.2mm
D8TZ-5050S2RGB-5V-I4-H14FootprintLED_SMD:LED_WS2812B_PLCC4_5.0x5.0mm_P3.2mm
D9TZ-5050S2RGB-5V-I4-H14FootprintLED_SMD:LED_WS2812B_PLCC4_5.0x5.0mm_P3.2mm
D10TZ-5050S2RGB-5V-I4-H14FootprintLED_SMD:LED_WS2812B_PLCC4_5.0x5.0mm_P3.2mm
J1TSW-113-07-G-S13FootprintConnector_PinHeader_2.54mm:PinHeader_1x13_P2.54mm_Vertical
J3TYPE-C-31-M-1215FootprintConnector_USB:USB_C_Receptacle_HRO_TYPE-C-31-M-12
TP1Tomachie_TP_E1FootprintPads:TPS127
TP2Tomachie_TP_E1FootprintPads:TPS127
TP3Tomachie_TP_E1FootprintPads:TPS127
TP4Tomachie_TP_E1FootprintPads:TPS127
TP5Tomachie_TP_E1FootprintPads:TPS127
TP6Tomachie_TP_E1FootprintPads:TPS127
TP7Tomachie_TP_E1FootprintPads:TPS127
TP8Tomachie_TP_E1FootprintPads:TPS127
TP9Tomachie_TP_E1FootprintPads:TPS127
TP10Tomachie_TP_E1FootprintPads:TPS127
TP11Tomachie_TP_E1FootprintPads:TPS127
TP12Tomachie_TP_E1FootprintPads:TPS127
TP13Tomachie_TP_E1FootprintPads:TPS127
TP14Tomachie_TP_E1FootprintPads:TPS127
TP15Tomachie_TP_E1FootprintPads:TPS127
TP16Tomachie_TP_E1FootprintPads:TPS127
TP17Tomachie_TP_E1FootprintPads:TPS127
TP18Tomachie_TP_E1FootprintPads:TPS127
TP19Tomachie_TP_E1FootprintPads:TPS127
TP20Tomachie_TP_E1FootprintPads:TPS127
TP21Tomachie_TP_E1FootprintPads:TPS127
TP22Tomachie_TP_W1FootprintPads:TPS127
TP23Tomachie_TP_W1FootprintPads:TPS127
TP24Tomachie_TP_W1FootprintPads:TPS127
TP25Tomachie_TP_W1FootprintPads:TPS127
TP26Tomachie_TP_W1FootprintPads:TPS127
TP27Tomachie_TP_W1FootprintPads:TPS127
TP28Tomachie_TP_W1FootprintPads:TPS127
TP29Tomachie_TP_W1FootprintPads:TPS127
TP30Tomachie_TP_W1FootprintPads:TPS127
TP31Tomachie_TP_W1FootprintPads:TPS127
TP32Tomachie_TP_W1FootprintPads:TPS127
TP33Tomachie_TP_W1FootprintPads:TPS127
TP34Tomachie_TP_W1FootprintPads:TPS127
TP35Tomachie_TP_W1FootprintPads:TPS127
TP36Tomachie_TP_W1FootprintPads:TPS127
TP37Tomachie_TP_W1FootprintPads:TPS127
TP38Tomachie_TP_W1FootprintPads:TPS127
TP39Tomachie_TP_W1FootprintPads:TPS127
TP40Tomachie_TP_W1FootprintPads:TPS127
TP41Tomachie_TP_W1FootprintPads:TPS127
U1SC1511-A461FootprintPackage_DFN_QFN:QFN-60-1EP_7x7mm_P0.4mm_EP3.4x3.4mm
U2AMS1117-3.34Footprintcomponents:SOT-223_UMW
U3SN74AHCT1G125DBVR5FootprintPackage_TO_SOT_SMD:SOT-23-5
X1ABM8-272-T34Footprintcomponents:ABM8-272-T3_ABR

15.5  IC Pin Electrical Properties

Unique IC models3
Total IC instances3

IC Library Models

Industry NameLibrary NameRefDesNotes

SN74AHCT1G125DBVR74AHCT1G125U3
AMS1117-3.3AMS1117-3.3U2
SC1511-A4RP2354AU1

15.5.1  74AHCT1G125 (SN74AHCT1G125DBVR)

PinPin NameElectricalNotes

1Input
2Input
3GNDPower In
4High Impedance
5VCCPower In

15.5.2  AMS1117-3.3 (AMS1117-3.3)

PinPin NameElectricalNotes

1GNDPower Out
2VOUTOutput
3VINPower In
4VOUTOutput

15.5.3  RP2354A (SC1511-A4)

PinPin NameElectricalNotes

1IOVDDPower In
2GPIO0Bidirectional
3GPIO1Bidirectional
4GPIO2Bidirectional
5GPIO3Bidirectional
6DVDDPower In
7GPIO4Bidirectional
8GPIO5Bidirectional
9GPIO6Bidirectional
10GPIO7Bidirectional
11IOVDDPassive
12GPIO8Bidirectional
13GPIO9Bidirectional
14GPIO10Bidirectional
15GPIO11Bidirectional
16GPIO12Bidirectional
17GPIO13Bidirectional
18GPIO14Bidirectional
19GPIO15Bidirectional
20IOVDDPassive
21XINInput
22XOUTOutput
23DVDDPassive
24SWCLKInput
25SWDIOBidirectional
26RUNInput
27GPIO16Bidirectional
28GPIO17Bidirectional
29GPIO18Bidirectional
30IOVDDPassive
31GPIO19Bidirectional
32GPIO20Bidirectional
33GPIO21Bidirectional
34GPIO22Bidirectional
35GPIO23Bidirectional
36GPIO24Bidirectional
37GPIO25Bidirectional
38IOVDDPassive
39DVDDPassive
40GPIO26/ADC0Bidirectional
41GPIO27/ADC1Bidirectional
42GPIO28/ADC2Bidirectional
43GPIO29/ADC3Bidirectional
44ADC_AVDDPower In
45IOVDDPassive
46VREG_AVDDPower In
47VREG_PGNDPower In
48VREG_LXPower Out
49VREG_VINPower In
50VREG_FBPassive
51USB_DMBidirectional
52USB_DPBidirectional
53USB_OTP_VDDPower In
54QSPI_IOVDDPower In
55QSPI_SD3Bidirectional
56QSPI_SCLKOutput
57QSPI_SD0Bidirectional
58QSPI_SD2Bidirectional
59QSPI_SD1Bidirectional
60QSPI_SSOutput
61GNDPower In

Generated by Tomachie v3.85 2026-07-14 13:27:32
https://tomachie.com

Copyright © 2026 Tomachie LLC. All rights reserved.

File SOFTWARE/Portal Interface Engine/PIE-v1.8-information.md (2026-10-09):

## Lamoka1 DEV-Brain — PIE Version V1.8

The **Lamoka1 DEV-Brain V1.8** is the Raspberry Pi RP2354A firmware that operates the Lamoka1-DEV-Brain's user interface, ten WS2812B RGB LEDs, and a single control button. V1.8 is built around a simple one-button interface, with the button's different press durations and combinations used to navigate menus, select modes, change settings, play the Fireball game, and return to the default idle state.

The firmware is written using Arduino functionality together with the **FastLED** library for LED control and the Raspberry Pi Pico boot ROM interface for USB BOOTSEL mode.

### Hardware Interface

V1.8 directly defines the following hardware connections (per HARDWARE/COMPONENTS.md, MCU is RP2354A made by Raspberry Pi):

* **GPIO 11** — WS2812B LED data (WS2812B made by WorldSemi)
* **GPIO 0** — User button (B3F-4055 made by Aratas)
* **GPIO 5** — Additional digital entropy input
* **GPIO 26 / ADC0**
* **GPIO 27 / ADC1**
* **GPIO 28 / ADC2**
* **GPIO 29 / ADC3**

The firmware controls **10 WS2812B LEDs** as a single FastLED array. The LEDs are configured for the WS2812B's **GRB** color order.

The default operating values are:

* **Brightness:** 6
* **Speed:** 100
* **Frame interval:** 16 ms
* **Menu timeout:** 16 seconds
* **Minimum brightness:** 6

The firmware also deliberately disables FastLED dithering.

### One-Button Interface

The entire user interface is controlled through one button connected using `INPUT_PULLUP`. V1.8 does not simply detect whether the button is pressed; it measures the length and timing of each press to determine what the user is trying to do.

The firmware recognizes five useful gestures:

* **Tap** — a short press
* **Double tap** — two taps within 380 ms
* **Hold** — approximately 550 ms
* **Long hold** — approximately 1200 ms
* **Very long hold** — approximately 2800 ms

Button input has a **28 ms debounce period** to prevent electrical switch bounce from being interpreted as multiple presses.

A tap behaves slightly differently depending on whether the user is already inside a menu. Outside a menu, the firmware waits to determine whether the tap becomes a double tap. Inside a menu, the tap is immediately returned as a menu-selection gesture.

This allows a single physical button to provide multiple controls without requiring additional switches.

### User Interface State Machine

V1.8 is organized around several UI states:

* **Mode** — normal lighting operation
* **Main Menu**
* **Games Menu**
* **Settings Menu**
* **Brightness**
* **Speed**
* **Info**
* **In Game**
* **Sleep**

The firmware uses these states to determine how each gesture should behave. For example, a tap in the main menu moves the cursor, while a tap during normal operation is passed to the currently active lighting mode.

The menus also remember their previous cursor positions. This means that returning to the Games or Settings menu does not automatically reset the cursor to the first item.

### Main Menu

The main menu contains six positions:

1. **Status**
2. **Fireplace**
3. **Lightsaber**
4. **Rainbow**
5. **Games**
6. **Settings**

The first four menu positions use the cactus-green menu color. Games is orange and Settings is blue.

The currently selected position is displayed in **hot pink** and uses a breathing brightness animation. This makes the cursor visually distinct from the menu items.

A tap moves forward through the menu, while a double tap moves backward. A hold selects the highlighted item.

A long hold from the menu returns directly to the default idle state.

### Default Status Mode

The default idle display is a **blue bouncing ball**.

The main blue LED moves from LED 0 through LED 9 and then back again. Two additional LEDs are used behind the main LED to create a short blue trail, giving the movement the appearance of a moving light rather than a single LED simply turning on and off.

The movement rate is affected by the global speed setting.

When the system starts, Status mode is selected automatically. Returning from shutdown, timing out of a menu, or using the appropriate long-hold action also returns the system to this default status mode.

### Fireplace Mode

The Fireplace mode is one of the major V1.8 upgrades. Instead of simply displaying a fixed red/orange pattern, it maintains a **10-element heat model** representing the temperature of each LED position.

When Fireplace mode starts, every LED receives an initial amount of heat. A moving heat source then injects energy into the model.

The source continuously chooses new target positions, moves toward them, and can receive a small velocity from the random system. The source is constrained to the middle portion of the LED array so the fire remains concentrated around its base rather than behaving like an unconstrained moving light.

The fire simulation contains several layers:

* **Heat cooling** — every LED gradually loses heat.
* **Source injection** — the moving fire source adds new heat.
* **Neighbor injection** — heat is also added around the source.
* **Diffusion** — neighboring LED temperatures are blended together.
* **Rising heat** — heat is biased upward to imitate hot air and flames rising.
* **Random flame licks** — occasional additional bursts appear above the source.
* **High sparks** — rare hotter events appear higher in the fire.
* **Base glow** — LED 0 is prevented from becoming completely cold.
* **Noise modulation** — FastLED noise changes the intensity of individual LEDs.
* **Flare effects** — button interactions can temporarily inject significantly more heat.

The color of each LED is calculated from its simulated heat. The palette progresses through several stages:

**dark red → red → orange → yellow → white-hot**

Low heat produces a dark red glow, while the hottest portions transition toward a pale white-hot color.

A normal tap creates a stronger flare. A double tap creates an even stronger flare and also changes the fire's source target and velocity. This gives the Fireplace mode an interactive component rather than making it a completely passive animation.

### Lightsaber Mode

Lightsaber mode generates a colored animated blade across the LED array.

Every time a blade is launched, V1.8 selects a new hue using the entropy system. The code explicitly prevents the newly selected hue from being identical to the previous blade's hue, so two consecutive launches cannot have exactly the same hue.

Each launch also randomly determines:

* Blade saturation
* Animation pattern
* Instability
* Ignition state

The blade starts with zero power and **extends** outward. The power value controls the visible blade length, allowing the blade to grow into position rather than appearing at full length immediately.

The blade has several animation patterns that can change its brightness, flicker, pulsing behavior, and instability. The first LEDs are also blended toward white to create a brighter blade core.

During the first 170 ms of ignition, LED 0 receives an additional white flash to emphasize the blade starting up.

A tap stops an extending blade. Once stopped, another tap launches a new blade. A double tap immediately launches another blade. A hold creates a short **clash effect**, during which portions of the blade are repeatedly brightened toward white.

Additional random white flashes are occasionally placed along the blade to make it look less static.

### Rainbow Mode

Rainbow mode continuously generates a rainbow across all ten LEDs using FastLED's `fill_rainbow()` function.

The rainbow has its own speed value, and the global speed setting also affects how quickly the hue moves.

A tap cycles through ten rainbow animation speeds.

A double tap reverses the direction of the rainbow.

When Rainbow mode is entered, the starting hue is randomized so it does not always begin at exactly the same point in the color spectrum.

### Fireball Game

V1.8 also contains a complete LED-based game called **Fireball**.

The game uses LED 0 as the target. The player waits for a fireball traveling from the opposite end of the LED array to reach that target and presses the button at the correct moment.

The game starts with:

* **3 lives**
* **115 ms fireball movement interval**
* **10 ms speed increase per successful catch**
* **30 ms minimum movement interval**

The fireball begins at LED 9 and travels toward LED 0.

The visual fireball consists of:

* A white leading LED
* A hot/orange section behind it
* A red trailing section

This creates a moving projectile rather than simply moving a single colored LED.

When the player taps while the fireball is exactly on LED 0, the catch is successful. The score increases by one and the fireball becomes faster. The game then produces a short expanding blast animation before displaying the score.

The score is displayed using the ten LEDs as a **binary display**. Each LED represents one binary bit, with the cactus-green LEDs showing the active bits.

If the player misses, one life is removed. The game briefly flashes red and then immediately launches another fireball if lives remain.

After all three lives are lost, the game enters the Game Over state. The LEDs display a pulsing red background while the binary score remains visible in cactus green.

A tap during Game Over starts a new game. A long hold while playing exits the game and returns to the Games menu, with the Games cursor remaining on Fireball.

### Settings Menu

The Settings menu contains six positions:

1. **Back**
2. **Brightness**
3. **Speed**
4. **Info**
5. **BOOTSEL**
6. **Shutdown**

The same one-button navigation system is used here: tap moves forward, double tap moves backward, and hold selects the current option.

### Brightness Control

Brightness provides ten predefined levels:

`6, 12, 20, 30, 42, 56, 72, 88, 106, 125`

The current level is represented across the ten LEDs. LEDs up to the selected position are hot pink, while the remaining LEDs are cactus green.

A tap moves to the next brightness level. A double tap moves to the previous level.

The selected value is immediately applied to FastLED.

The firmware also enforces a hard minimum brightness of **6**, meaning the brightness cannot be reduced below that value through the brightness setting.

### Speed Control

Speed also provides ten predefined values:

`40, 55, 70, 85, 100, 120, 145, 170, 200, 240`

The current speed level is displayed using the same ten-LED bar-style interface used for brightness.

A tap moves forward through the available speeds, while a double tap moves backward.

The global speed value is then used by the individual animations to change their timing or movement rate.

### Information Screen

The Info section contains three pages.

The first page displays all ten LEDs in cactus green with LED 0 highlighted hot pink.

The second page displays a changing number of illuminated LEDs based on the current time, creating a simple animated information display.

The third page displays the ten LEDs in cactus green.

A tap advances through the three pages and a double tap moves backward. A hold returns to the Settings menu.

### Entropy and Randomness

V1.8 contains a dedicated `EntropyService` rather than relying entirely on a fixed pseudo-random sequence.

The entropy service reads the four analog inputs and the additional digital entropy input, combines those readings with the microsecond timer, and repeatedly mixes the resulting value using XOR and bit-shift operations.

The service can then provide:

* 32-bit random values
* 8-bit random values
* Random values within a specified range
* Random true/false decisions

The entropy system is initialized by performing **300 mixing operations** before normal operation begins.

During normal operation, the entropy service is updated continuously.

This randomness is used throughout the firmware, including the Fireplace movement and flame behavior, Lightsaber colors and patterns, Rainbow starting position, game effects, and other animation variations.

### Menu Timeout

V1.8 includes an automatic menu timeout of **16 seconds**.

Whenever the user interacts with a menu, the firmware updates the menu activity timer. If the user stops interacting with the menu for more than 16 seconds, the firmware automatically leaves the menu and returns to the default blue Status mode.

Returning to idle resets the main mode to Status and resets the main cursor to the first position.

### Very-Long-Hold Function

A very long button hold is treated as a global escape command.

When the button has been held for approximately 2.8 seconds, the firmware briefly fills all ten LEDs with hot pink and then forces the interface back into the default Status mode.

This provides a general way to escape from the current interface state.

### Shutdown Mode

Shutdown is implemented as a software sleep state.

When Shutdown is selected, the firmware:

1. Changes the UI state to `UI_SLEEP`.
2. Clears the LEDs.
3. Sets FastLED brightness to zero.
4. Shows the blank LED state.
5. Waits for the button to be released.

Once the button has been released, holding it again for approximately **1.5 seconds** wakes the interface.

On wake-up, the firmware restores the configured brightness, returns to Status mode, resets the main cursor, and starts the blue bouncing-ball animation again.

While asleep, the LEDs remain off and the normal rendering loop is bypassed.

### USB BOOTSEL Mode

The Settings menu also provides a BOOTSEL option.

When selected, V1.8 turns the LEDs off, sets FastLED brightness to zero, waits briefly, and calls:

`reset_usb_boot(0, 0)`

This restarts the Raspberry Pi controller into USB boot mode so firmware can be loaded through the RP2354A's bootloader interface.

### Startup Sequence

At startup, V1.8 initializes FastLED for the ten WS2812B LEDs, disables dithering, applies the configured brightness, and clears the LEDs.

The entropy and button services are then initialized.

The firmware performs a short startup sweep across all ten LEDs. Each LED is assigned a different HSV hue as the sweep progresses, with the LEDs being displayed individually with an 18 ms delay.

After the sweep, the firmware waits briefly, clears the LEDs, and enters the default Status mode.

This means the board has a defined visual startup sequence before entering normal operation.

### Main Program Loop

The V1.8 main loop operates continuously.

On every iteration it:

1. Checks whether the system is in Shutdown mode.
2. Updates the entropy service.
3. Checks the menu timeout.
4. Polls the button for a gesture.
5. Passes the gesture to the appropriate UI or application.
6. Updates the LED animation when the 16 ms frame interval has elapsed.
7. Renders the current UI state.
8. Sends the resulting LED data to the WS2812B LEDs with `FastLED.show()`.

The normal renderer therefore operates at a target interval of approximately **16 ms per frame**, or about **62.5 frames per second**, while individual animations control their own movement rates internally.

Shutdown mode is handled separately so that normal animation rendering does not continue while the system is asleep.

### V1.8 Overall

In V1.8, the DEV-Brain is more than an LED controller. It is a complete single-button user interface running on the Raspberry Pi RP2354A.

The firmware combines:

* Ten individually controlled WS2812B RGB LEDs
* A single multi-gesture button interface
* Persistent menu cursors
* Four main lighting modes
* A simulated Fireplace effect
* An interactive Lightsaber effect
* A configurable Rainbow effect
* The Fireball LED game
* Adjustable brightness
* Adjustable animation speed
* An information interface
* Automatic menu timeout
* Software shutdown and wake-up
* USB BOOTSEL entry
* Hardware-derived entropy for randomized effects
* A centralized UI state machine
* A 16 ms animation/rendering cycle

The result is a self-contained control system for the Lamoka1-DEV-Brain where the same ten LEDs function both as the primary visual output and as the user interface itself. V1.8 uses those LEDs not only for animations, but also for menu selection, settings indicators, game graphics, binary score display, status information, and system-state feedback.

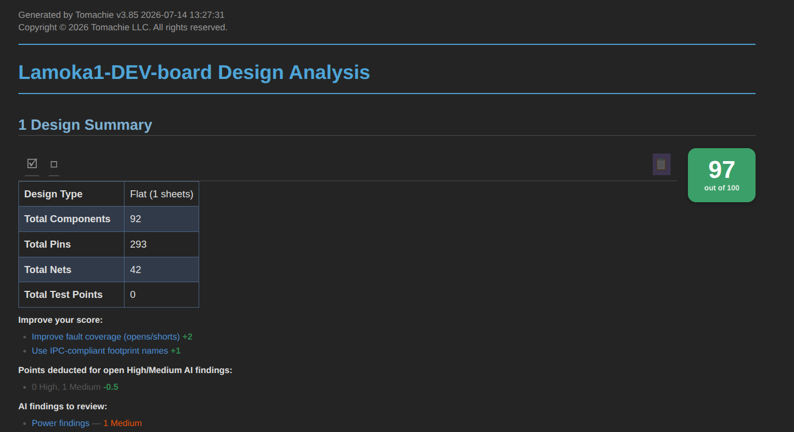
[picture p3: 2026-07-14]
Lamoka1-DEV-Brain/Kicad files/Reviews/Tomachie report.png

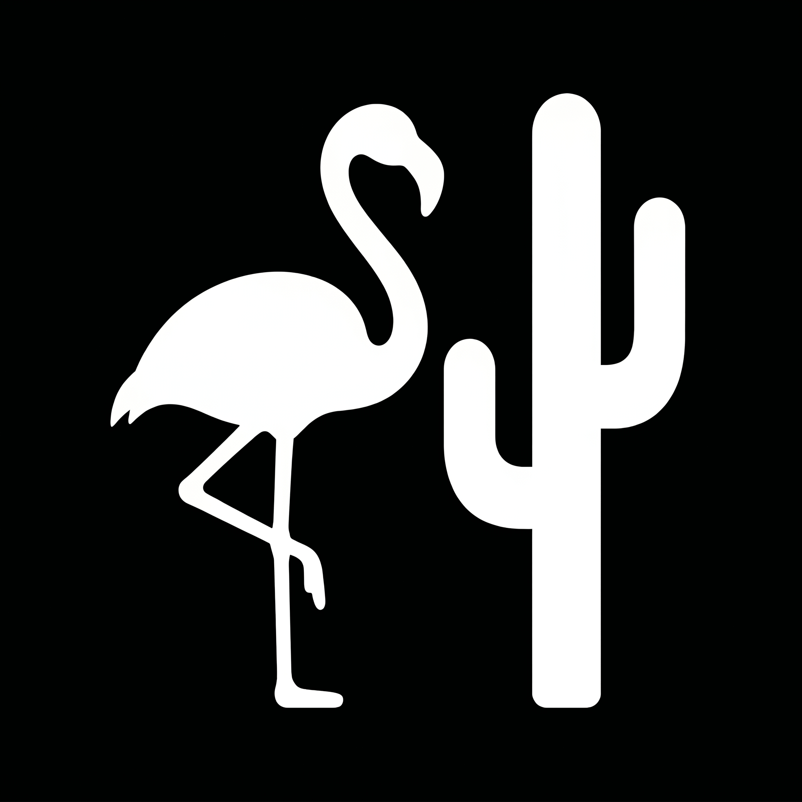
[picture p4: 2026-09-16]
Images/FlamingonCactus.png

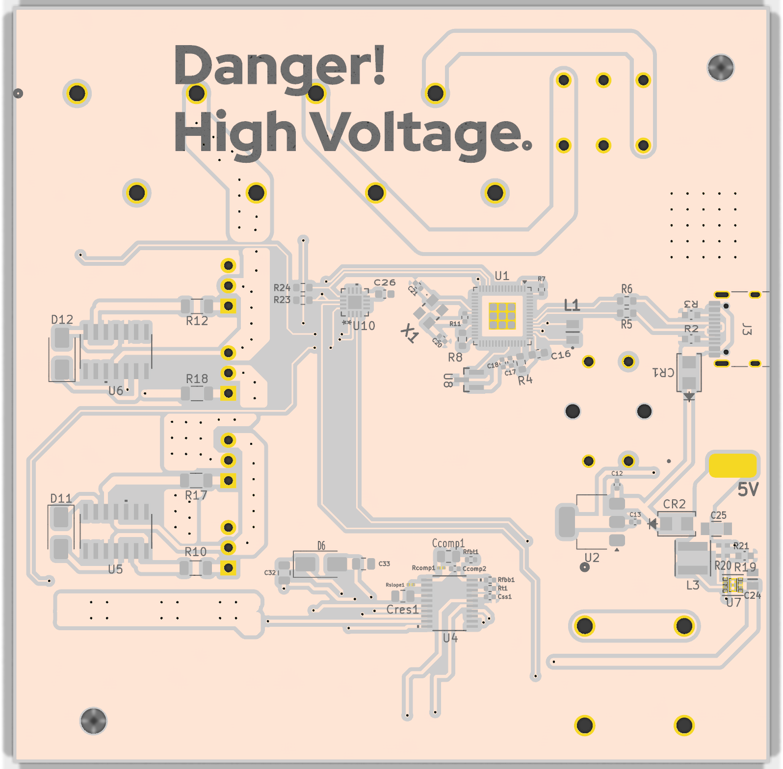
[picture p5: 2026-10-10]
Images/lamoka1-2-routing-bottom-fresh.png

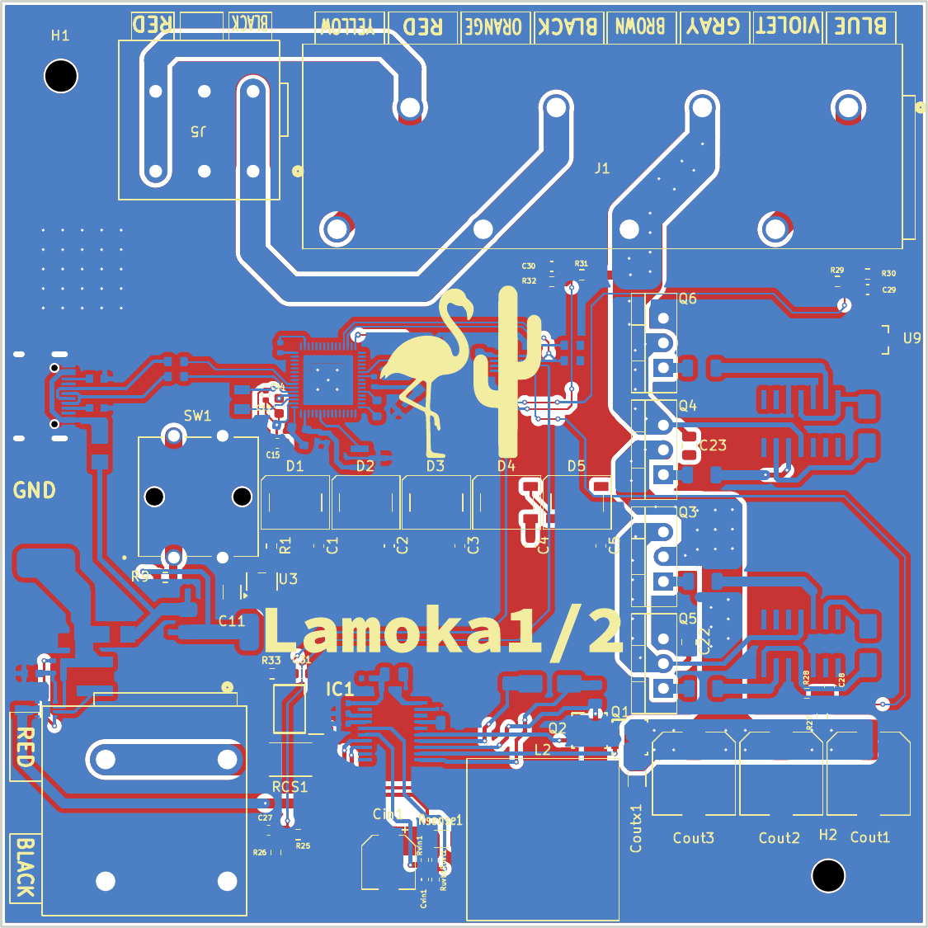
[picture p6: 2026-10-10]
Images/lamoka1-2-routing-copper-fresh.png

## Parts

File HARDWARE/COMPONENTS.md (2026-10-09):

## Exact manufacturer part numbers used in the schematic explained in plain English (component alternatives may be used) 

> [!Warning]
> This is not verified to be the full BOM for the Lamoka1. For all components, please refer to the official BOM. This is purely for reference and learning, not to be used as a BOM.

 NMOS for H-bridge (Inversion-section): CSD19536KCS made by TI  x4

 Transformer (Inversion-section): VPT24-4170 made by Triad Magnetics

 Main microcontroller for full system: RP2354A made by Raspberry Pi

 Addressable RGB LEDs: WS2812B made by WorldSemi

 Low-side NMOS for boost converter (Inversion-section): CSD17304Q3 made by TI

 High-side NMOS for boost converter (Inversion-section): CSD16323Q3 made by TI

 Gate driver for H-bridge NMOSs: UCC27735DR made by TI x2

 IC for 11-14v to 5v buck converter: TPS62160DSGR made by TI

 Input capacitor for buck converter: TMK212BBJ106KG made by Taiyo Yuden

 Cooling fan for unit: FAD1-04010BHLW11 made by Qualtek

 Pin header to connect fan to PCB: 0470531000 made by Molex

 Output capacitor for buck converter: GRM31CR71A226KE15L made by Murata

 Inductor for buck converter: PA4332.222NLT made by Pulse Electronics

 Bottom resistor for buck converter FB: RC0603FR-07180KL made by Yageo

 Top resistor for buck converter FB: CRCW0402953KFKED made by Vishay Dale

 Power-good pull-up resistor for buck converter: CRCW0402100KFKED made by Vishay Dale

 Diode for 5v source to eliminate buck output and USB 5v interactions: SS14-E3/61T made by Vishay x2

 Temp sensor for unit: TMP235A2DBZR made by TI x2

 Connector for transformer's connection to the PCB: 2606-1108/010-000 made by Wago

 Connector for 11-14v DC source: 2606-1352 made by Wago

 Outlet for inverter (120v AC North American): 3-119-054 made by SCHURTER Inc.

 Connector for hooking outlet to PCB: 2604-1103 made by Wago

 Multiplexer for voltage and current monitoring: ADS7128IRTER made by TI

 Tactile button for RP2354A control: B3F-4055 made by Aratas (Formerly Omron Components)

 IC for 11-14v to 17v boost converter: LM5122QMHX-NOPB made by TI

 Converter to go from 5v to 3v3 for control: AMS1117-3.3 made by Advanced Monolithic Systems

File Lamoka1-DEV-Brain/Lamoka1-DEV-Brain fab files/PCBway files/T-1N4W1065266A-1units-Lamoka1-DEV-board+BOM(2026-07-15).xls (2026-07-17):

PCBWay Bom Quotation, Product No.:T-1N4W1065266A
Item # | *Designator | *Qty | Manufacturer | *Mfg Part # | Description / Value | *Package/Footprint | Category | *Unit Price(1 unit) | *Total | *Delivery Time | *Actual Purchase Mfg Part # | *PCBWay Note | Customer Reply | PCBWay Update
1 | C1,C2,C3,C4,C5,C6,C7,C8,C9,C10,C17,C18,C19 | 13 | Samsung Electro-Mechanics | CL05B104KO5NNNC | 100 nF ceramic capacitor | 0402 | SMT | $0.021 | $0.273 |  | CL05B104KO5NNNC
2 | C11 | 1 | Murata Electronics | GRM31CR61A107MEA8K | 100 uF ceramic capacitor | 1206 | SMT | $2.265 | $2.265 |  | GRM31CR61A107MEA8K
3 | C12,C13 | 2 | Samsung Electro-Mechanics | CL05A106MQ5NUNC | 10 uF ceramic capacitor | 0402 | SMT | $0.405 | $0.810 |  | CL05A106MQ5NUNC
4 | C14,C15,C16 | 3 | Samsung Electro-Mechanics | CL10A475KP8NNNC | 4.7 uF ceramic capacitor | 0603 | SMT | $0.165 | $0.495 |  | CL10A475KP8NNNC
5 | C20,C21 | 2 | FH | 0402CG150J500NT | 15 pF C0G/NP0 ceramic capacitor | 0402 | SMT | $0.564 | $1.128 |  | 0402CG150J500NT
6 | D1,D2,D3,D4,D5,D6,D7,D8,D9,D10 | 10 | TUOZHAN | TZ-5050S2RGB-5V-I4-H1 | 5 V addressable RGB LED, WS2812B-compatible | 5050-4P | SMT | $0.071 | $0.710 |  | TZ-5050S2RGB-5V-I4-H1
7 | J3 | 1 | HRO Electronics | TYPE-C-31-M-12 | USB Type-C receptacle, USB 2.0 | HRO TYPE-C-31-M-12 | SMT / mechanical THT tabs | $1.110 | $1.110 |  | TYPE-C-31-M-12
8 | L1 | 1 | Abracon | AOTA-B201610S3R3-101-T | 3.3 uH power inductor | 2016 / 0806 | SMT | $0.688 | $0.688 | 7-10 Workdays | AOTA-B201610S3R3-101-T
9 | R1 | 1 | YAGEO | RC0603FR-07330RL | 330 ohm 1% resistor | 0603 | SMT | $0.457 | $0.457 | 7-10 Workdays | RC0603FR-07330RL
10 | R2,R3 | 2 | YAGEO | RC0603FR-075K1L | 5.1 kohm 1% resistor | 0603 | SMT | $0.054 | $0.108 |  | RC0603FR-075K1L
11 | R4 | 1 | YAGEO | RC0603FR-0733RL | 33 ohm 1% resistor | 0603 | SMT | $0.735 | $0.735 | 7-10 Workdays | RC0603FR-0733RL
12 | R5,R6 | 2 | YAGEO | RC0603FR-0727RL | 27 ohm 1% resistor | 0603 | SMT | $0.027 | $0.054 |  | RC0603FR-0727RL
13 | R7,R11 | 2 | YAGEO | RC0402FR-071KL | 1 kohm 1% resistor | 0402 | SMT | $0.147 | $0.294 |  | RC0402FR-071KL
14 | R8,R9 | 2 | YAGEO | RC0603FR-0710KL | 10 kohm 1% resistor | 0603 | SMT | $0.153 | $0.306 |  | RC0603FR-0710KL
15 | SW1 | 1 | C&K | PTS636SM43JSMTR LFS | Momentary tactile switch | PTS636 SMD | SMT | $0.812 | $0.812 | 7-10 Workdays | PTS636SM43JSMTR LFS
16 | U1 | 1 | Raspberry Pi | SC1511-A4 | RP2354A microcontroller | QFN-60 7x7 mm, 0.4 mm pitch, exposed pad | SMT / QFN | $1.719 | $1.719 | 7-10 Workdays | SC1511-A4
17 | U2 | 1 | EVVO | AMS1117-3.3 | 3.3 V linear regulator | SOT-223 | SMT | $0.937 | $0.937 | 7-10 Workdays | AMS1117-3.3 | AMS1117-3.3（5272-AMS1117-3.3CT-ND），Brand : EVVO Footprint ：SOT-223-3L ，pls confirm datasheet.
18 | U3 | 1 | Texas Instruments | SN74AHCT1G125DBVR | Single bus buffer / level shifter | SOT-23-5 | SMT | $0.138 | $0.138 |  | SN74AHCT1G125DBVR
19 | X1 | 1 | Abracon LLC | ABM8-272-T3 | Crystal resonator | SMD 3225-4P | SMT | $1.621 | $1.621 |  | ABM8-272-T3
 |  |  |  |  |  |  |  | Component Cost | $14.66
 |  |  |  |  |  |  |  | Assembly Cost | $29.00
 |  |  |  |  |  |  |  | PCB Cost | $5.00
 |  |  |  |  |  |  |  | V0 Member 0% off | $0.00
 |  |  |  |  |  |  |  | All Total 1 Units | $48.66

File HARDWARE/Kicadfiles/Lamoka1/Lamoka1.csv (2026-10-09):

Reference | Qty | Value | Footprint | MPN | Description
U5,U6 | 2 | UCC27735DR | UCC27735DR:SOIC_14L_TEX | UCC27735DR
U7 | 1 | TPS62160DSGR | TPS62160DSGR:DSG8_1P6X0P9 | TPS62160DSGR
U8,U9 | 2 | TMP235A2DBZR | TMP235A2DBZR:DBZ0003A-IPC_A | TMP235A2DBZR
C24 | 1 | 10uF | TMK212BBJ106KG-T:CAPC2114X145N | TMK212BBJ106KG-T
CR1,CR2 | 2 | 40V 1A Schottky | SS14-E3/61T:DO-214AC_VIS | SS14-E3/61T
RCS1 | 1 | 2m | Resistor_SMD:R_2512_6332Metric | CSNL2512FT2L00 | Resistor
R10,R12,R17,R18,Rsense1 | 5 | 10,2m | Resistor_SMD:R_1206_3216Metric | CSNL1206FT2L00,RC1206FR-0710RL | Resistor
R1,R4,R5,R6,R8,R9,R23,R24,R25,R26,R27,R28,R29,R30,R31,R32,R33 | 17 | 10k,22,27,33,330,36.5k,4.7k,43.2k,45.3k | Resistor_SMD:R_0603_1608Metric | RC0603FR-0710KL,RC0603FR-0722RL,RC0603FR-0727RL,RC0603FR-07330RL,RC0603FR-0733RL,RC0603FR-0736K5L,RC0603FR-0743K2L,RC0603FR-0745K3L,RC0603FR-074K7L | Resistor
R7,R11,Rfbb1,Rfbt1,Rt1,Ruvb1,Ruvt1,Rvin1 | 8 | 18.2k,1k,3.01,3.79k,49.9k,7.15k | Resistor_SMD:R_0402_1005Metric | CRCW040218K2FKED,CRCW04023K79FKED,CRCW04023R01FKED,CRCW040249K9FKED,CRCW04027K15FKED,RC0402FR-071KL | Resistor
Rcomp1,Rslope1 | 2 | 105k,28.7k | Resistor_SMD:R_0201_0603Metric | RC0201FR-07105KL,RC0201FR-0728K7L | Resistor
R2,R3,R19 | 3 | 180k,5.1k | RC0603FR-07180KL:RC0603N_YAG | RC0603FR-07180KL,RC0603FR-075K1L | Resistor
Q3,Q4,Q5,Q6 | 4 | 100V 150A N-Ch | Package_TO_SOT_THT:TO-220-3_Vertical | CSD19536KCS | N-channel NexFET power MOSFET, 100V 150A, TO-220 (1=G 2=D 3=S)
U3 | 1 | 74AHCT1G125 | Package_TO_SOT_SMD:SOT-23-5 | SN74AHCT1G125DBVR | Single Buffer Gate Tri-State, Low-Voltage CMOS
U2 | 1 | AMS1117-3.3 | Package_TO_SOT_SMD:SOT-223-3_TabPin2 | AMS1117-3.3 | 3.3 V SOT-223 linear regulator; output network is 10uF + 4.7uF + 2x100nF ceramic.
U1 | 1 | RP2354A | Package_DFN_QFN:QFN-60-1EP_7x7mm_P0.4mm_EP3.4x3.4mm | RP2354A | A microcontroller by Raspberry Pi, dual CPU architecture (ARM Cortex-M33 / RISC-V Hazard3), 150MHz, 2MB flash, 520KB SRAM, 12 PIO state machines, VQFN-60
L3 | 1 | 2.2uH | PA4332.222NLT:IND_PA4332.222NLT_PUL | PA4332.222NLT
U4 | 1 | LM5122MH/NOPB | LM5122QMHX-NOPB:PWP20_3P0X4P2 | LM5122MH/NOPB
D1,D2,D3,D4,D5 | 5 | WS2812B | LED_SMD:LED_WS2812B_PLCC4_5.0x5.0mm_P3.2mm | WS2812B | RGB LED with integrated controller
L2 | 1 | 1.8uH | Inductor_SMD:L_Coilcraft_XAL1580-182 | XAL1580-182MEB | Inductor
IC1 | 1 | INA240A2DR | INA240A2DR:SOIC127P600X175-8N | INA240A2DR | 80V, Low-/High-Side, Bi-Directional, Zero-Drift, Current Sense Amp w/Enhanced PWM Rejection
C25 | 1 | 22uF | GRM31CR71A226KE15L:G-31_MUR | GRM31CR71A226KE15L
D6,D11,D12 | 3 | D | Diode_SMD:D_SMA | SK215ATR,SS14-E3/61T | Diode
Q2 | 1 | 30V 56A N-Ch | CSD17304Q3:DQG0008A | CSD17304Q3
Q1 | 1 | 25V 60A N-Ch | CSD16323Q3:DQG0008A | CSD16323Q3
R20 | 1 | 953k | CRCW0402953KFKED:RC0402N_VIS | CRCW0402953KFKED
R21 | 1 | 100k | CRCW0402100KFKED:RES_CRCW_0402_VIS | CRCW0402100KFKED
J4,J6 | 2 | FAN 5V,FAN GND | Connector_Wire:SolderWirePad_1x01_SMD_3x6mm |  | Generic connector, single row, 01x01, script generated
J3 | 1 | USB_C_Receptacle_USB2.0_14P | Connector_USB:USB_C_Receptacle_HRO_TYPE-C-31-M-12 | TYPE-C-31-M-12 | USB 2.0-only 14P Type-C Receptacle connector
Cout1,Cout2,Cout3 | 3 | 180uF | Capacitor_SMD:CP_Elec_8x11.9 | 25SVPF180M | Unpolarized capacitor
Cin1 | 1 | 56uF | Capacitor_SMD:CP_Elec_5x5.9 | 20SVPF56MX | Unpolarized capacitor
C11,Coutx1 | 2 | 100u,47uF | Capacitor_SMD:C_1206_3216Metric | C3216X5R1E476M160AC,GRM31CR61A107MEA8K | Unpolarized capacitor
C22,C23,C32,C33,Ccomp1,Cres1 | 6 | 100nF,1uF,3.9nF,4.7uF,470nF | Capacitor_SMD:C_0805_2012Metric | 08053C104KAT2A,CGA4C2C0G1H392J060AA,GRM21BR71H105KA12L,MSAST21GAB5475MTNAO1,TMK212BJ474KD-T | Unpolarized capacitor
C1,C2,C3,C4,C5,C14,C15,C16,C26,C27,C28,C29,C30,C31 | 14 | 100n,100nF,1uF,4.7u,47nF | Capacitor_SMD:C_0603_1608Metric | CL10A105KA8NNNC,CL10A475KP8NNNC,CL10B104KB8NNNC,CL10B104KO8NNNC,CL10B473KB8NNNC | Unpolarized capacitor
C12,C13,C17,C18,C19,C20,C21,Ccomp2,Css1,Cvin1 | 10 | 100n,10u,130pF,15p,33nF,470nF | Capacitor_SMD:C_0402_1005Metric | 0402CG150J500NT,C1005X5R1V474K050BC,CL05A106MQ5NUNC,CL05B104KO5NNNC,GRM1555C1H131GA01D,GRM155R71A333KA01D | Unpolarized capacitor
SW1 | 1 | B3F-4055 | B3F-4055:SW_B3F-4050_OMR | B3F-4055
L1 | 1 | 3.3u | AOTA-B201610S3R3-101-T:AOTAB201610S3R3101T | AOTA-B201610S3R3-101-T | Inductor
U10 | 1 | ADS7128IRTER | ADS7128IRTER:WQFN16_RTE_TEX | ADS7128IRTER
X1 | 1 | ABM8-272-T3 | ABM8-272-T3:ABM8272T3 | ABM8-272-T3
J2 | 1 | 2606-1352 | 2606-1352:CONN2_2606-1352_WAG
J1 | 1 | 2606-1108/010-000 | 2606-1108/010-000:CONN8_2606-1108&slash_010-000_WAG
J5 | 1 | 2604-1103 | 2604-1103:CONN3_2604-1103_WAG

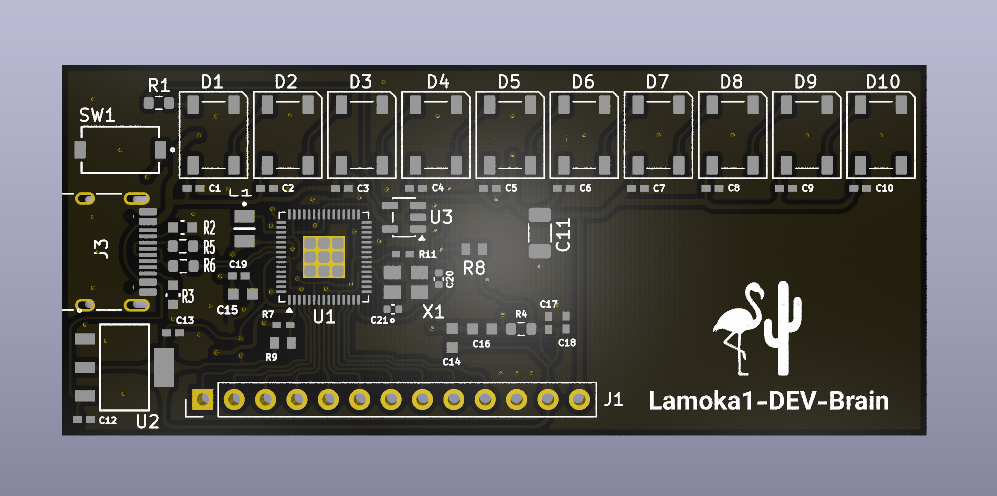
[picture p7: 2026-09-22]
Lamoka1-DEV-Brain/Renderings/Lamoka1-DEV-Brain-PCB-No-components.png

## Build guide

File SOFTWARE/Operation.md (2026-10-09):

When the Lamoka1/2 is connected to USB-C 5v, it will display a similar yet improved version of the PIE v1.8 interface. As soon as the unit's MUX (ADS7128IRTER made by TI) shows a voltage on the input net that is above 11v yet below 14v, the device will commence a boot-up sequence. The unit's fan (FAD1-04010BHLW11 made by Qualtek) is only connected to the buck 5v rail (TPS62160DSGR made by TI). The boot sequence will go upstream to verify everything is working correctly. 

 ## First phase 

 The MUX (ADS7128IRTER) will be detecting the source rail. If this rail is at an appropriate voltage (which it will be in order to even start the sequence), stage one will be validated as functioning. 

 ## Second phase

 Next, the MCU (RP2354A made by Raspberry Pi) verifies the buck 5V rail is present, which also powers the fan (FAD1-04010BHLW11). GPIO5 and GPIO6 are unused, so there is no PWM speed command or tach verification; the fan runs whenever the 5V rail is up. The two TMP235A2DBZR temperature sensors are monitored separately from fan control. Once the 5V rail is confirmed, the second phase will be confirmed functioning. 

 ## Third phase

 Up next, the MUX (ADS7128IRTER) will detect the output of the 11-14v to 17v boost converter (LM5122QMHX-NOPB made by TI). If this rail is within 3/4 of a volt of 17v, this stage will be verified as correctly operating. 

 ## Fourth phase

 Things will get a bit tricky now; we are monitoring alternating current waveforms after this point.

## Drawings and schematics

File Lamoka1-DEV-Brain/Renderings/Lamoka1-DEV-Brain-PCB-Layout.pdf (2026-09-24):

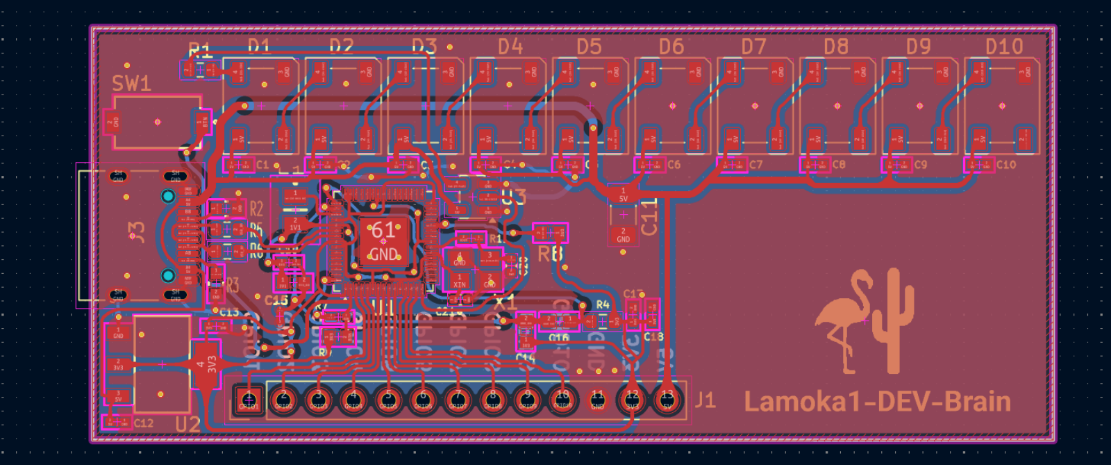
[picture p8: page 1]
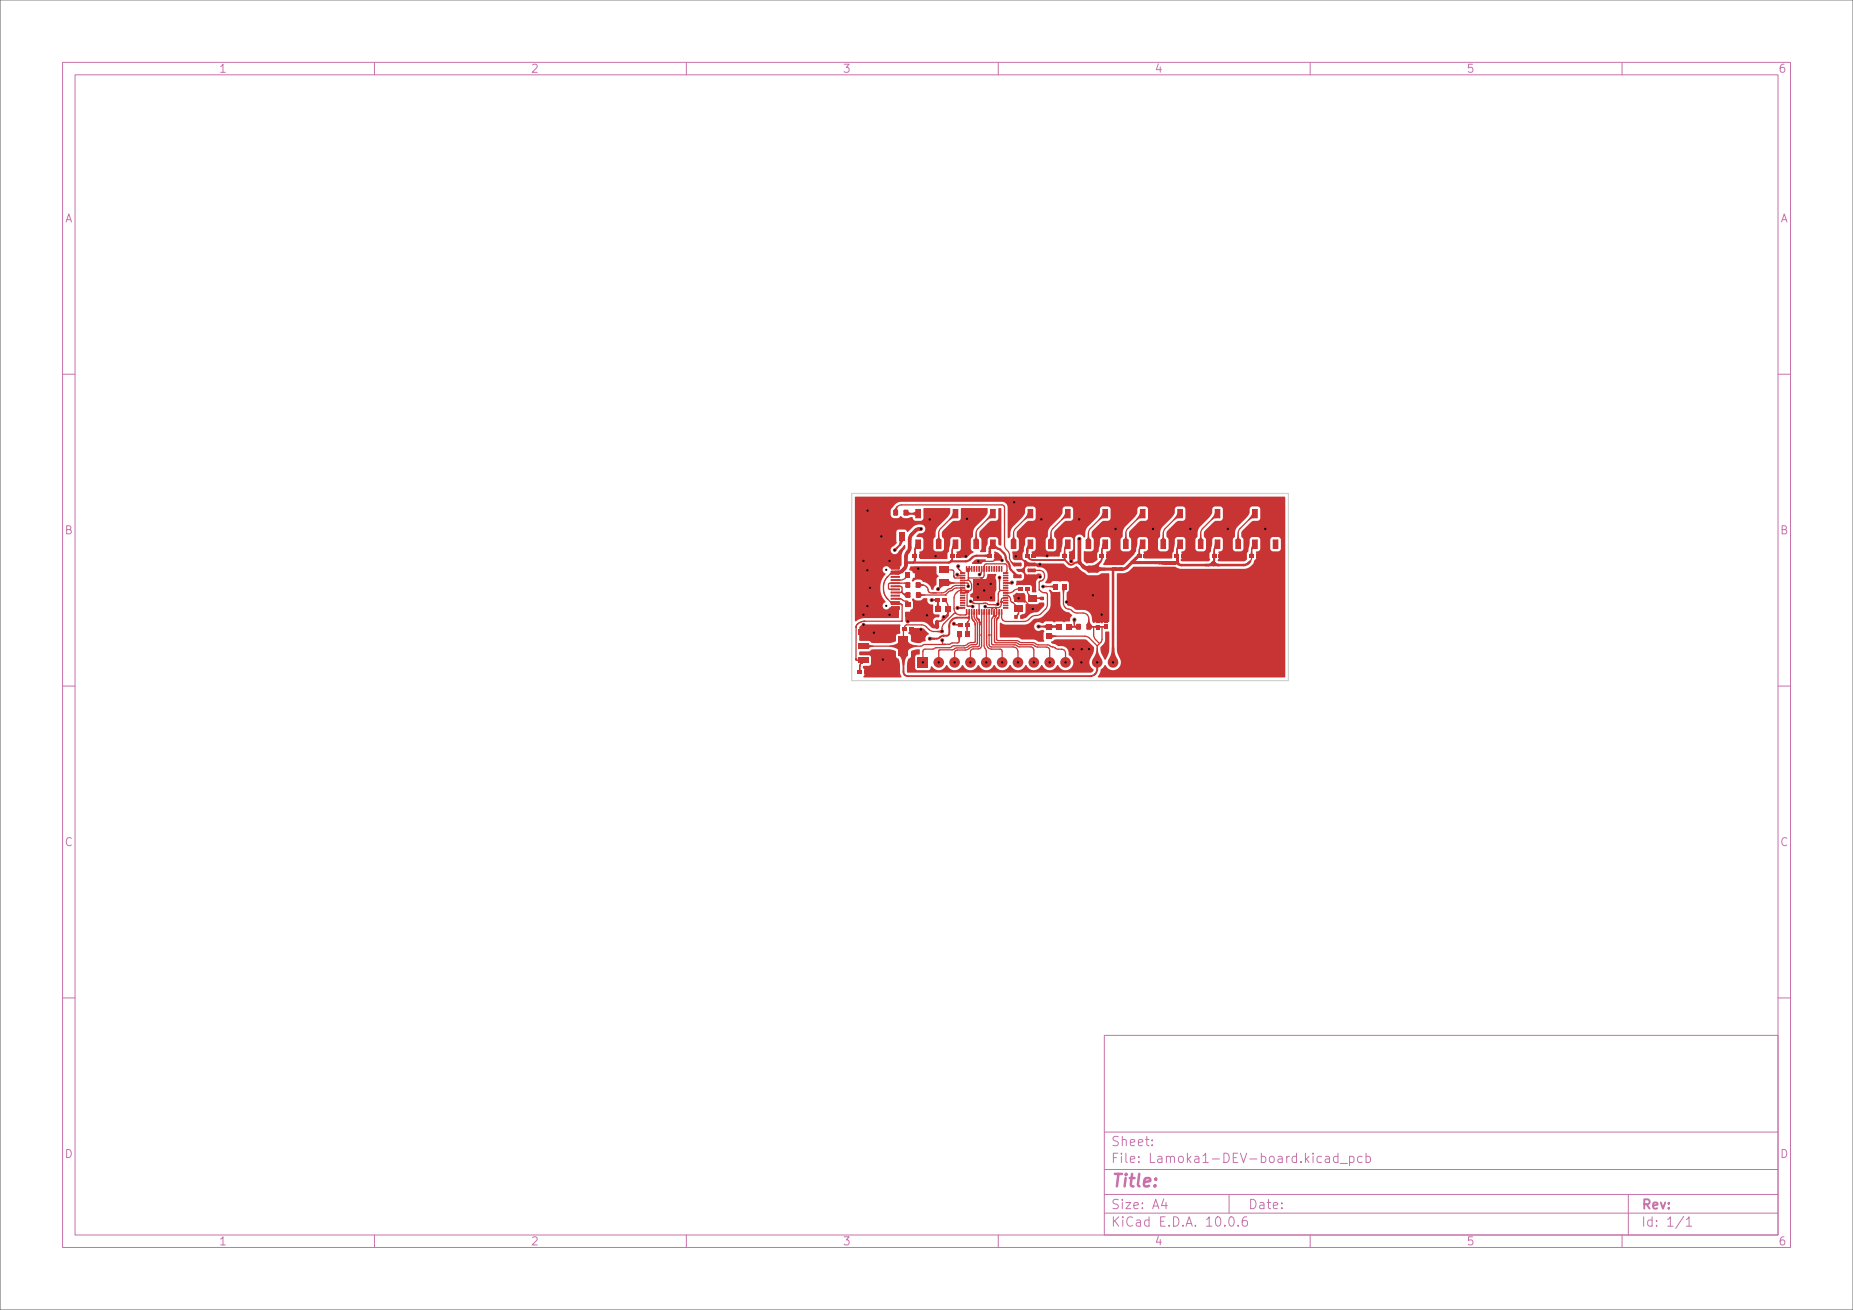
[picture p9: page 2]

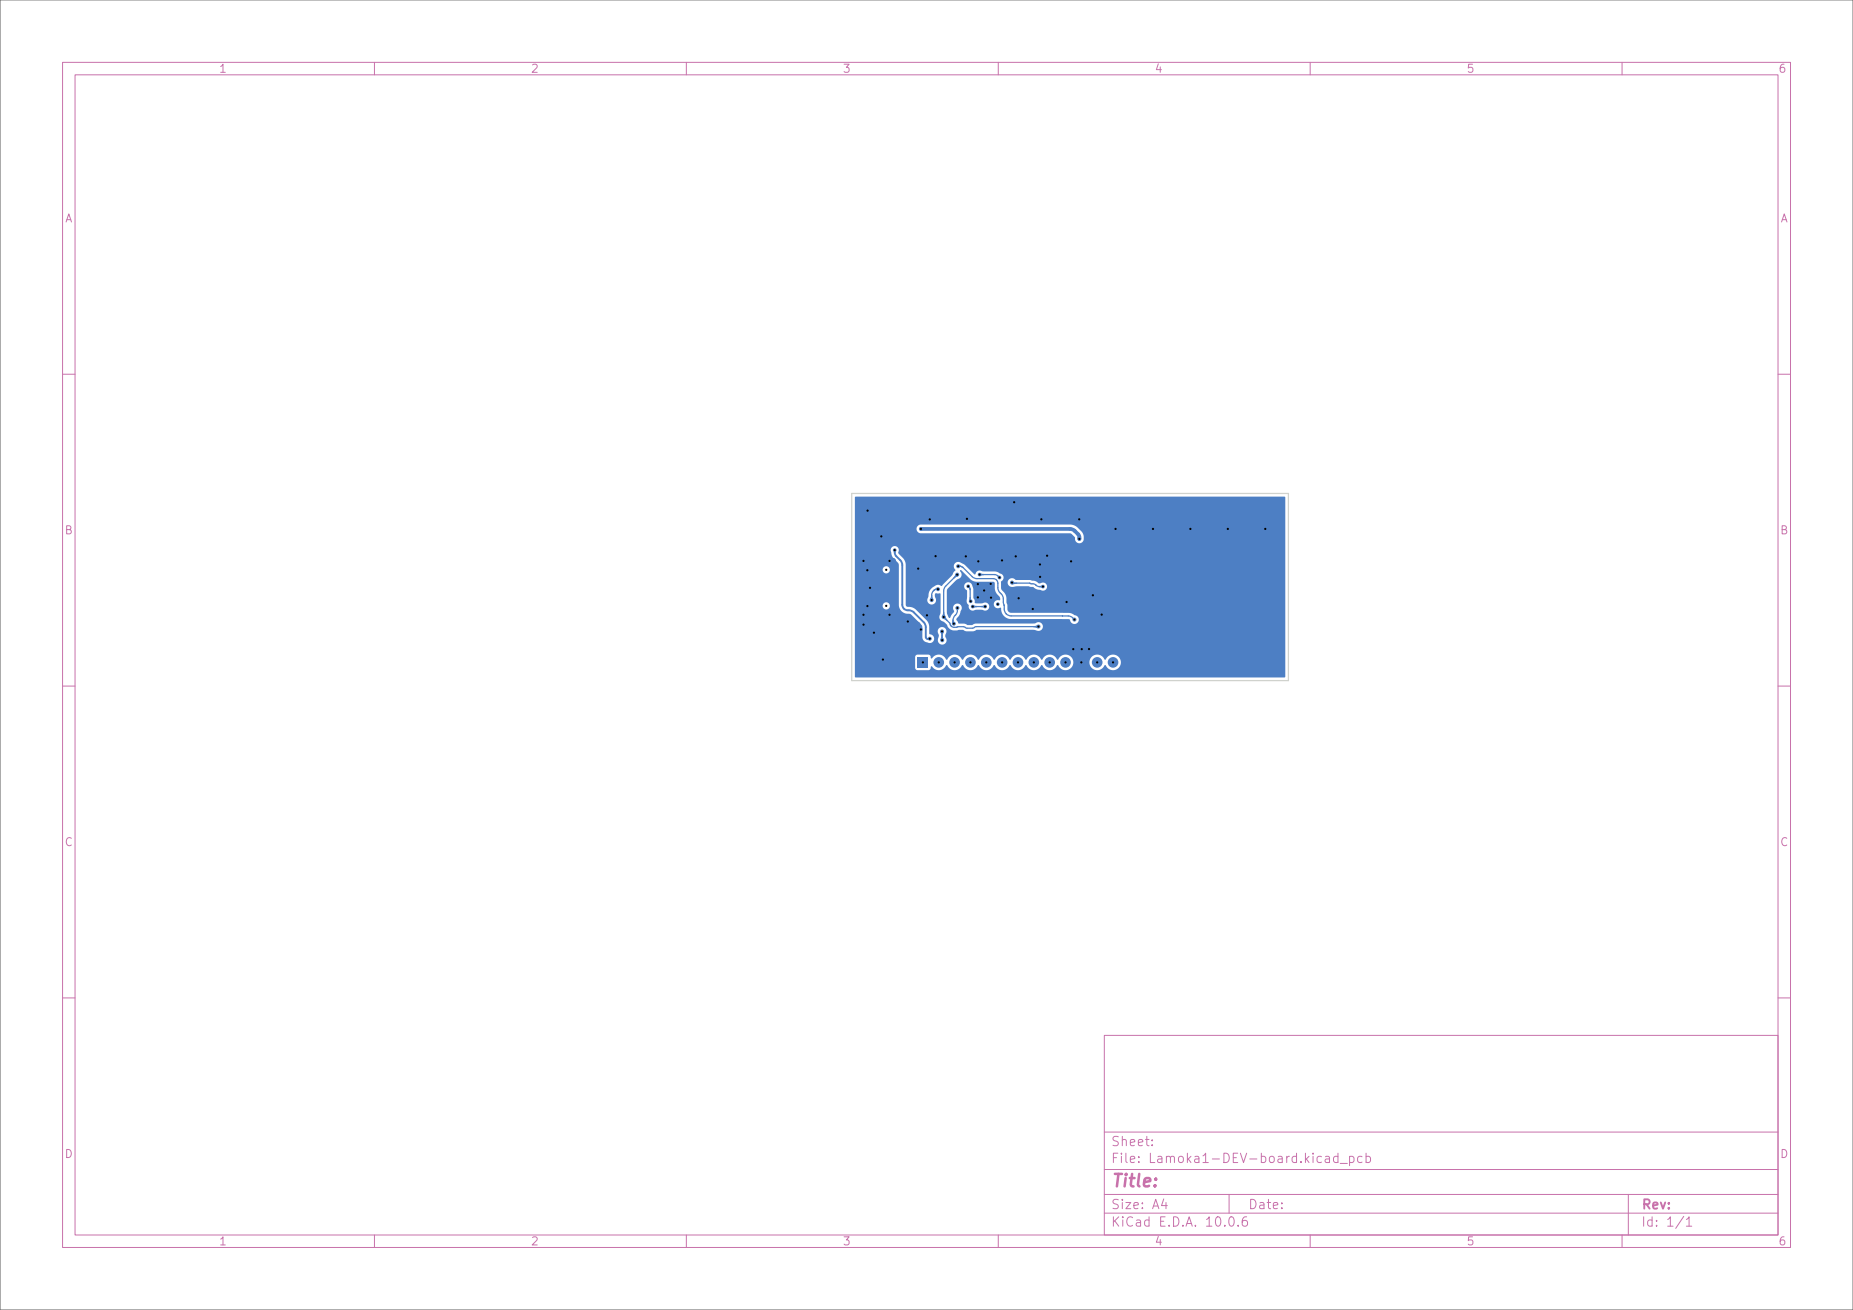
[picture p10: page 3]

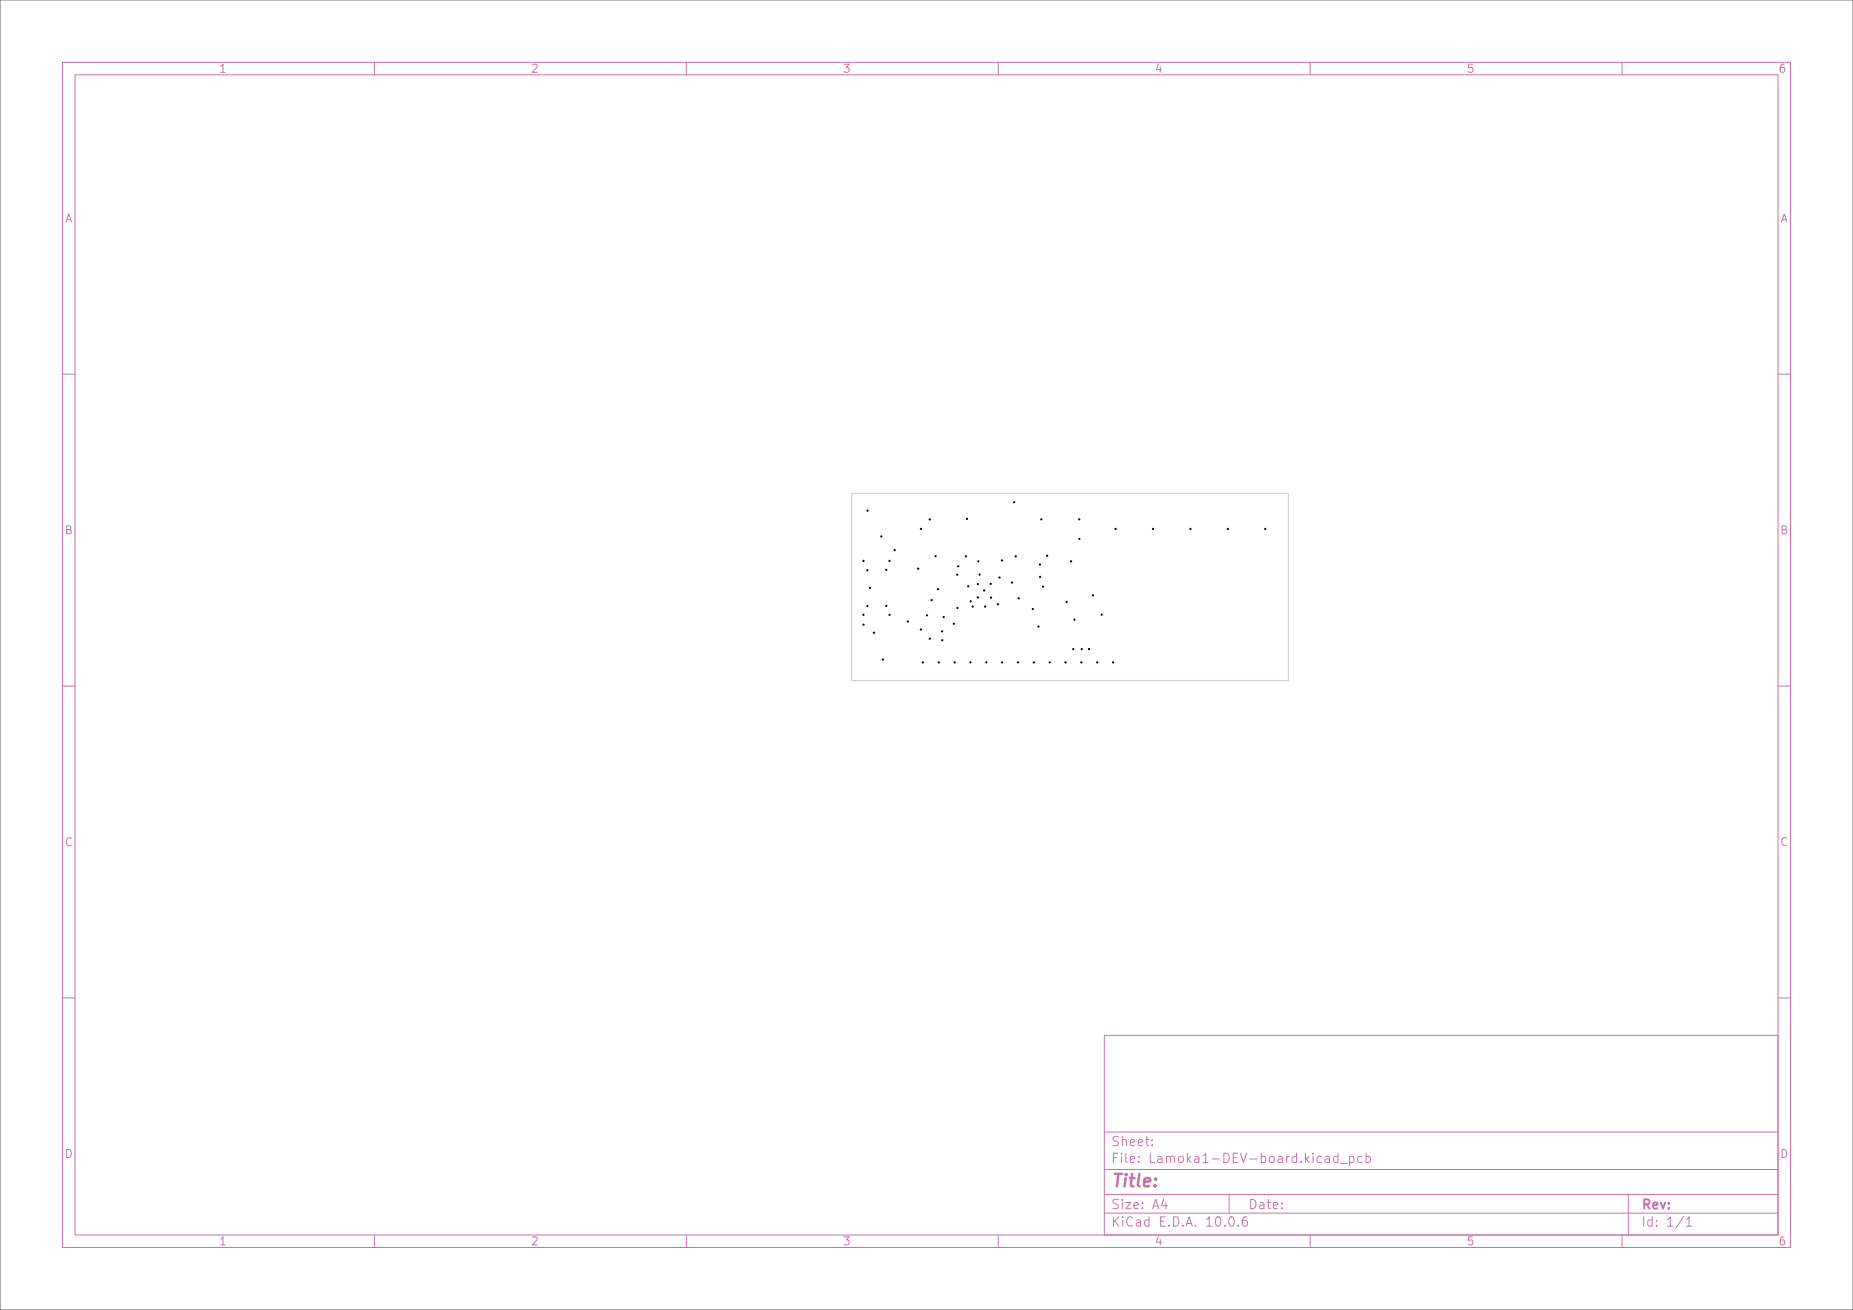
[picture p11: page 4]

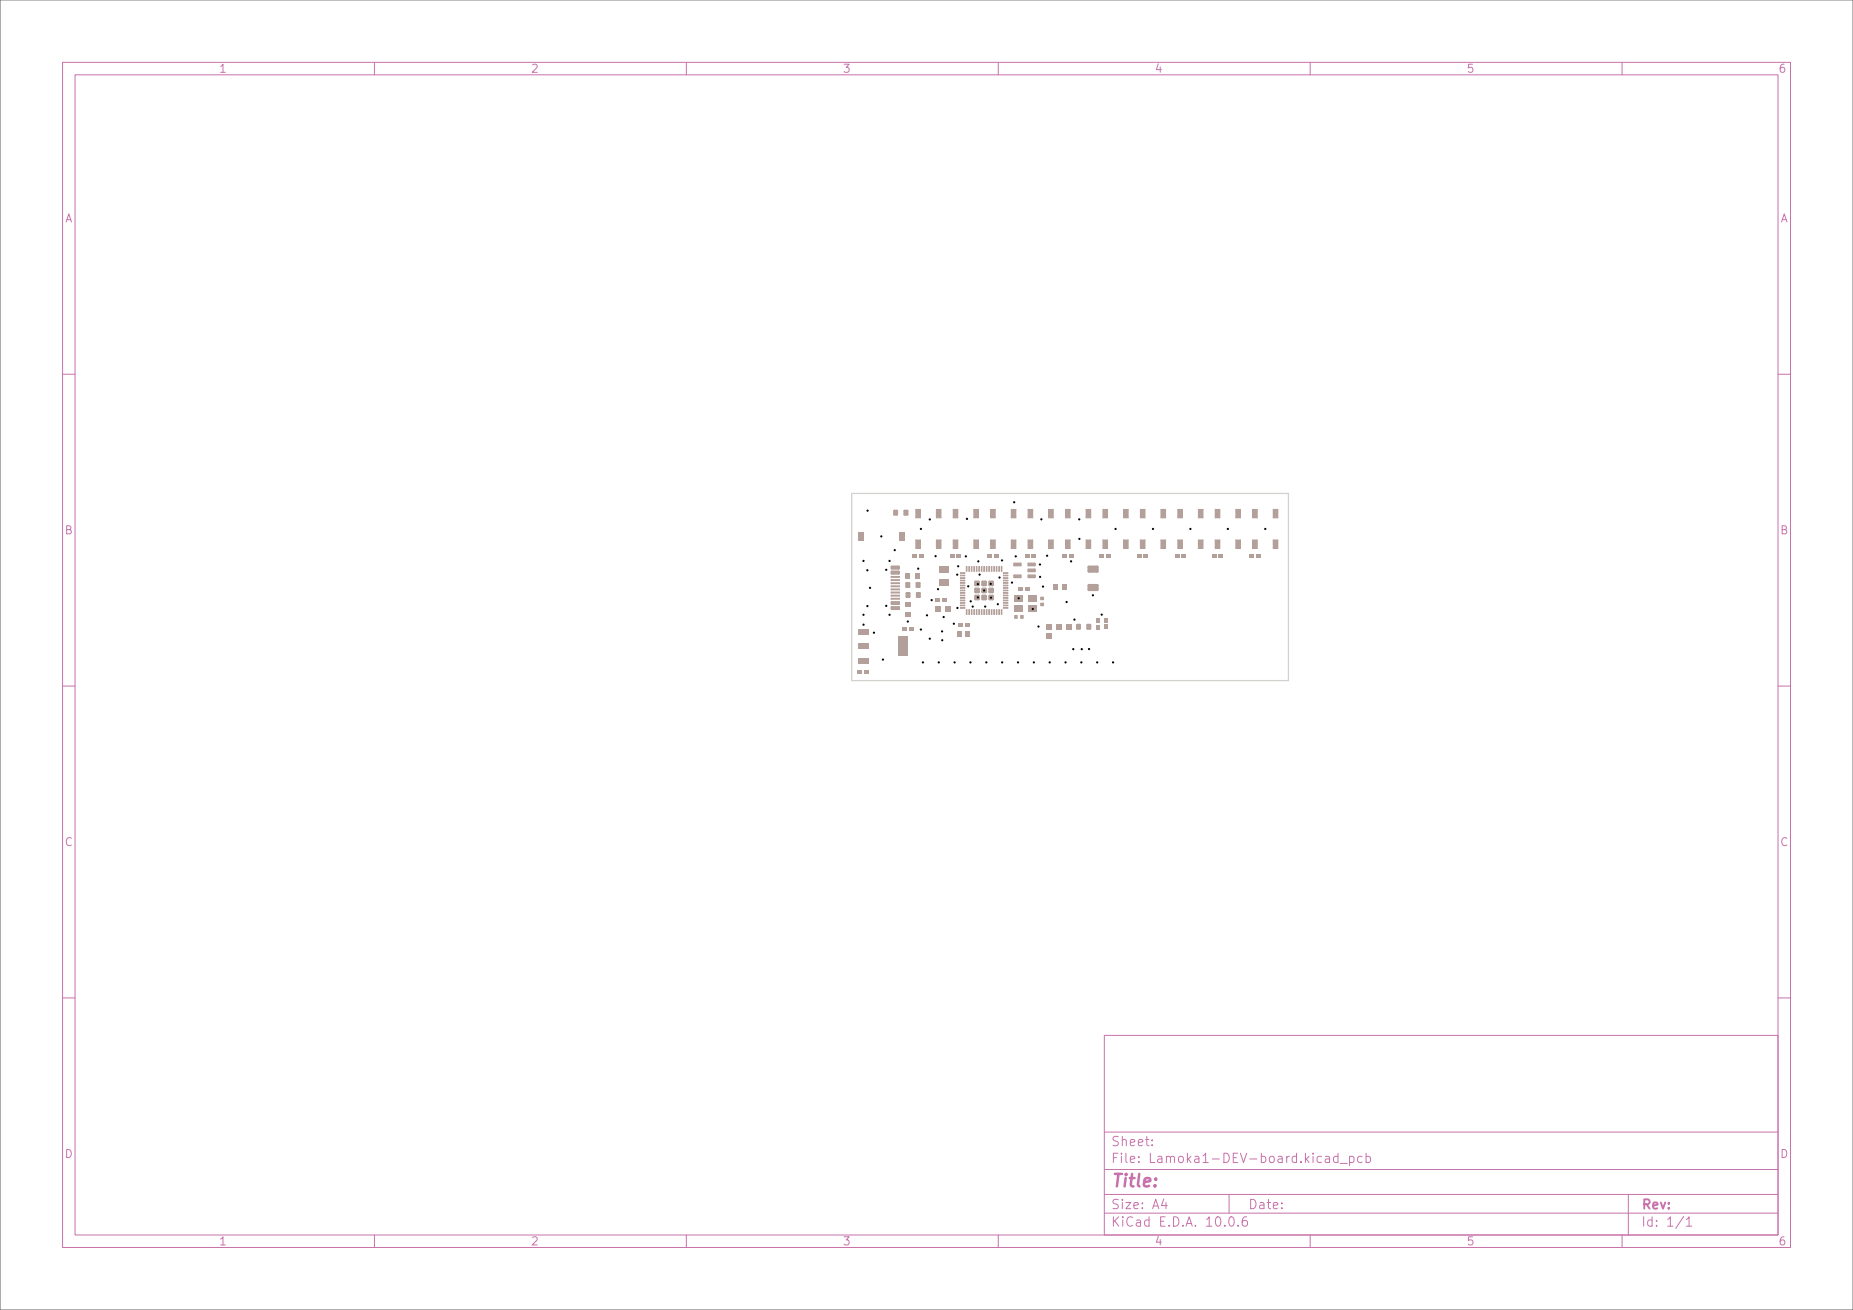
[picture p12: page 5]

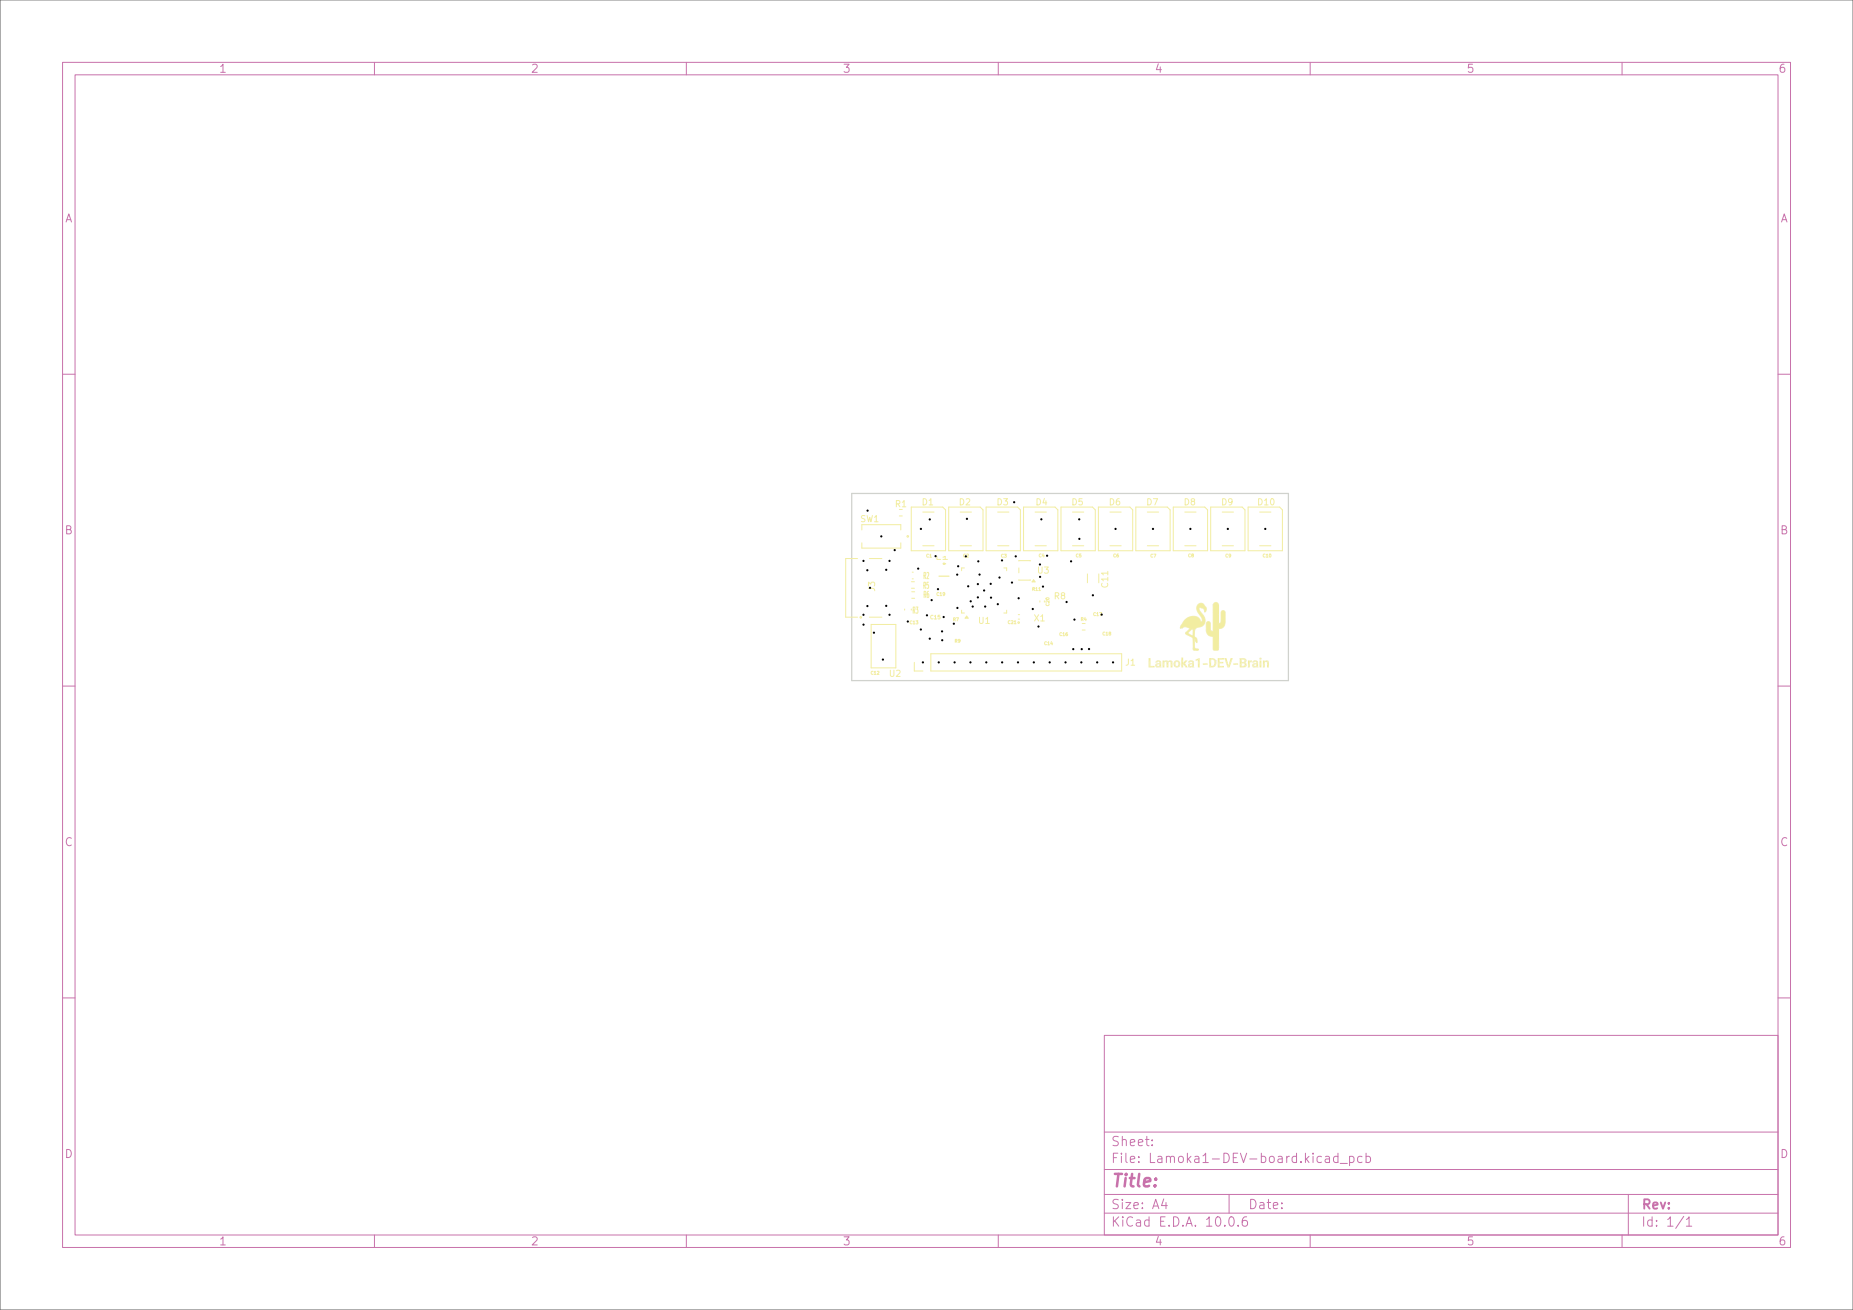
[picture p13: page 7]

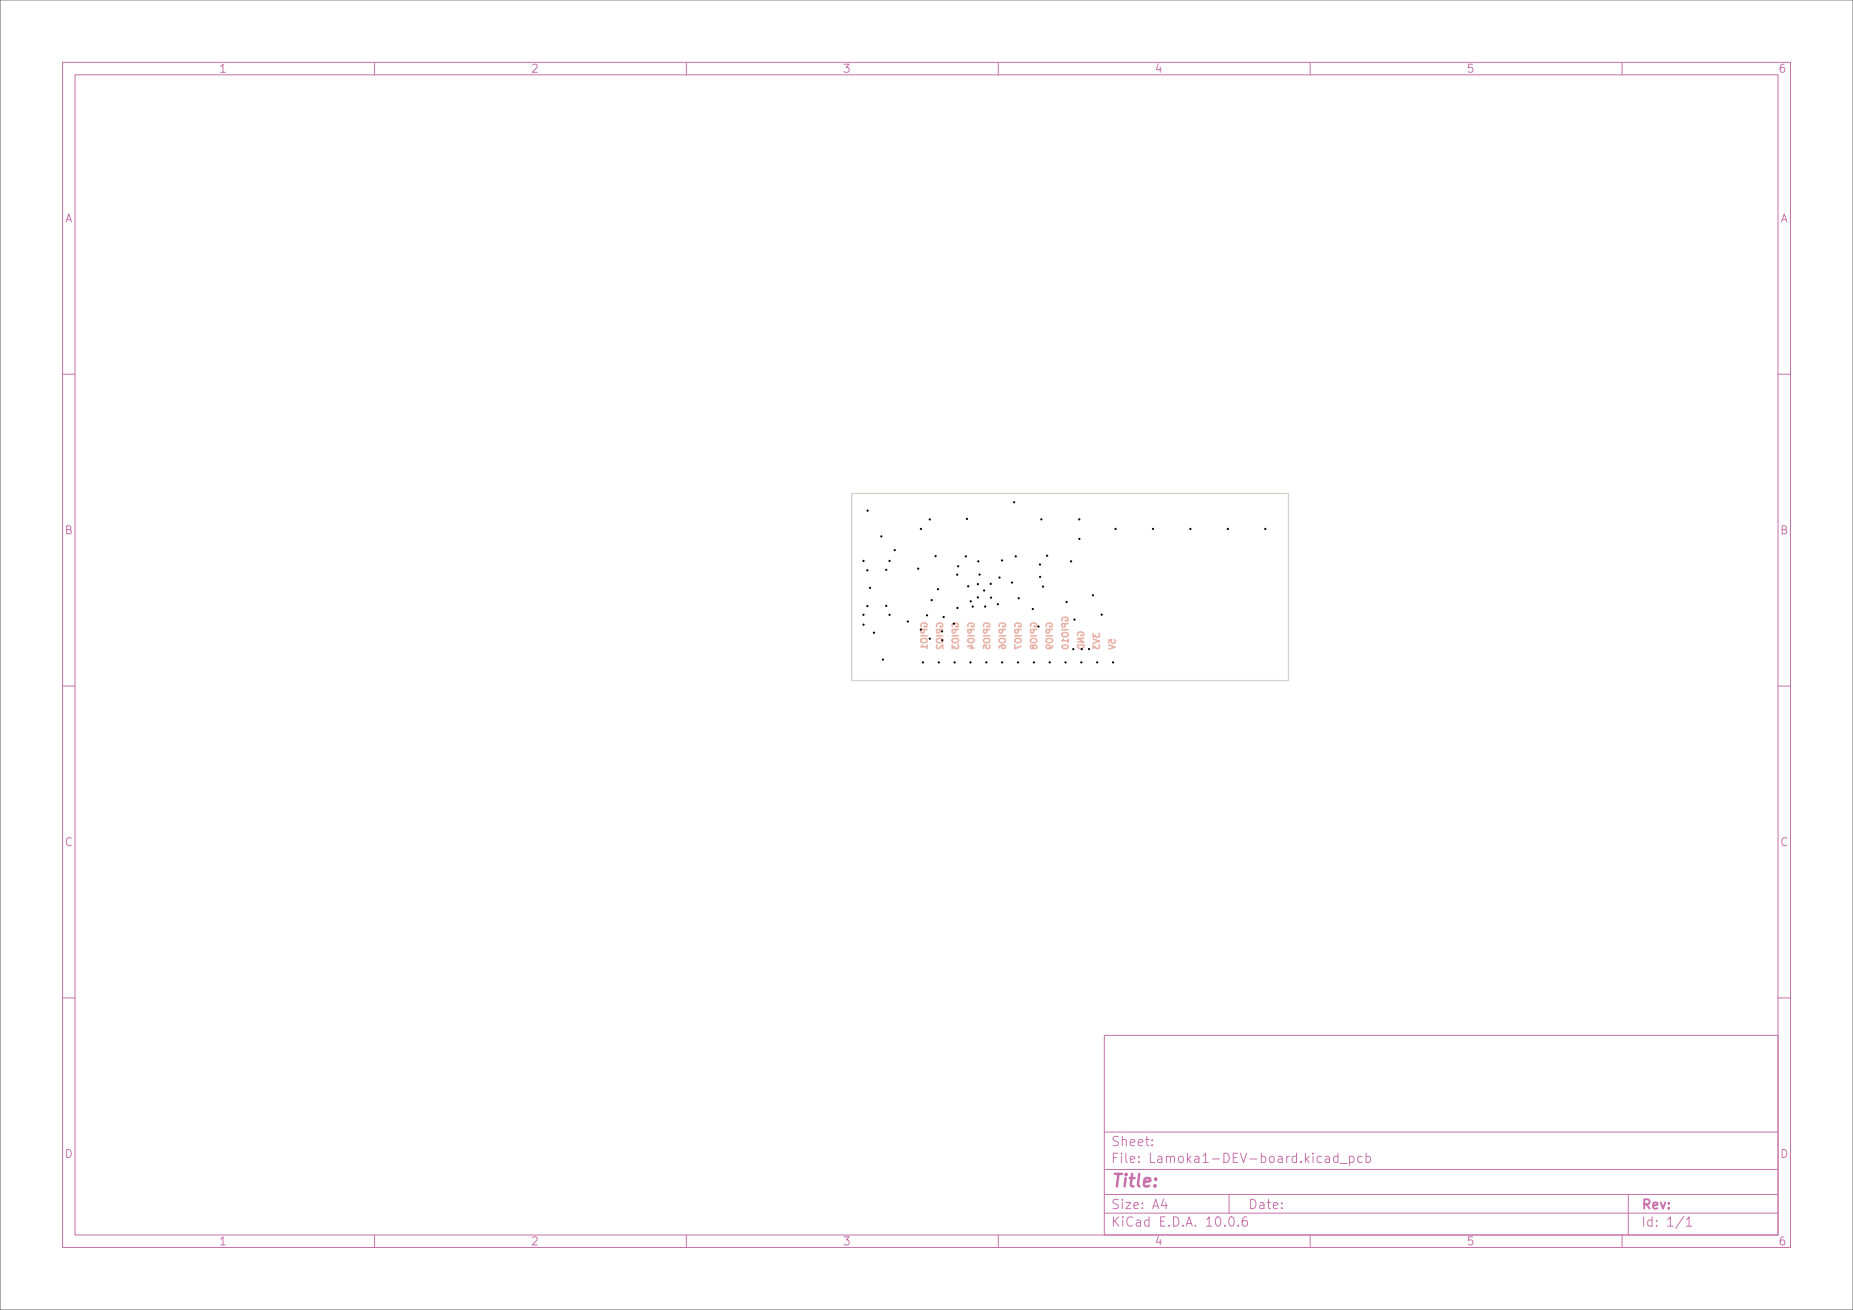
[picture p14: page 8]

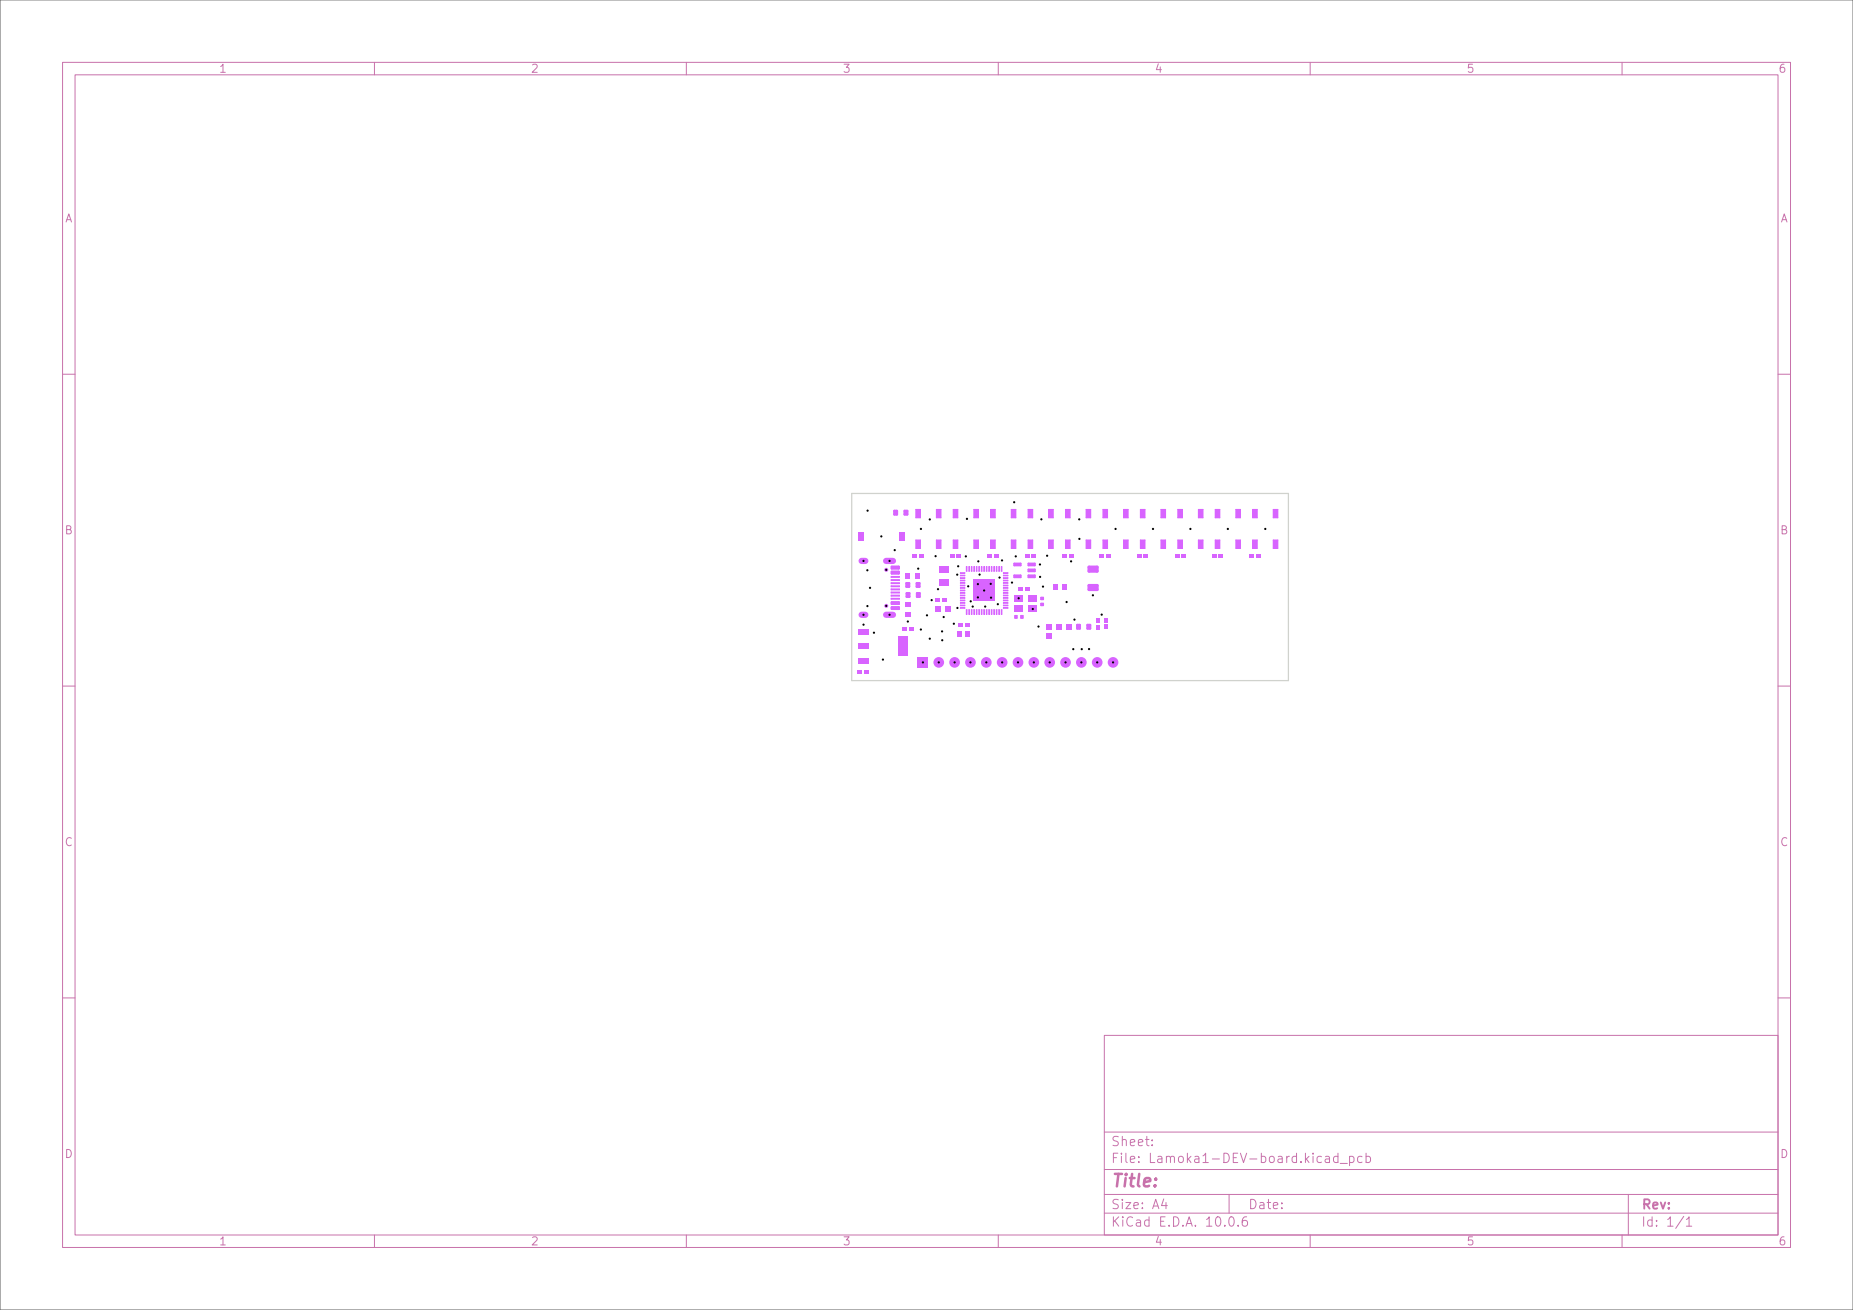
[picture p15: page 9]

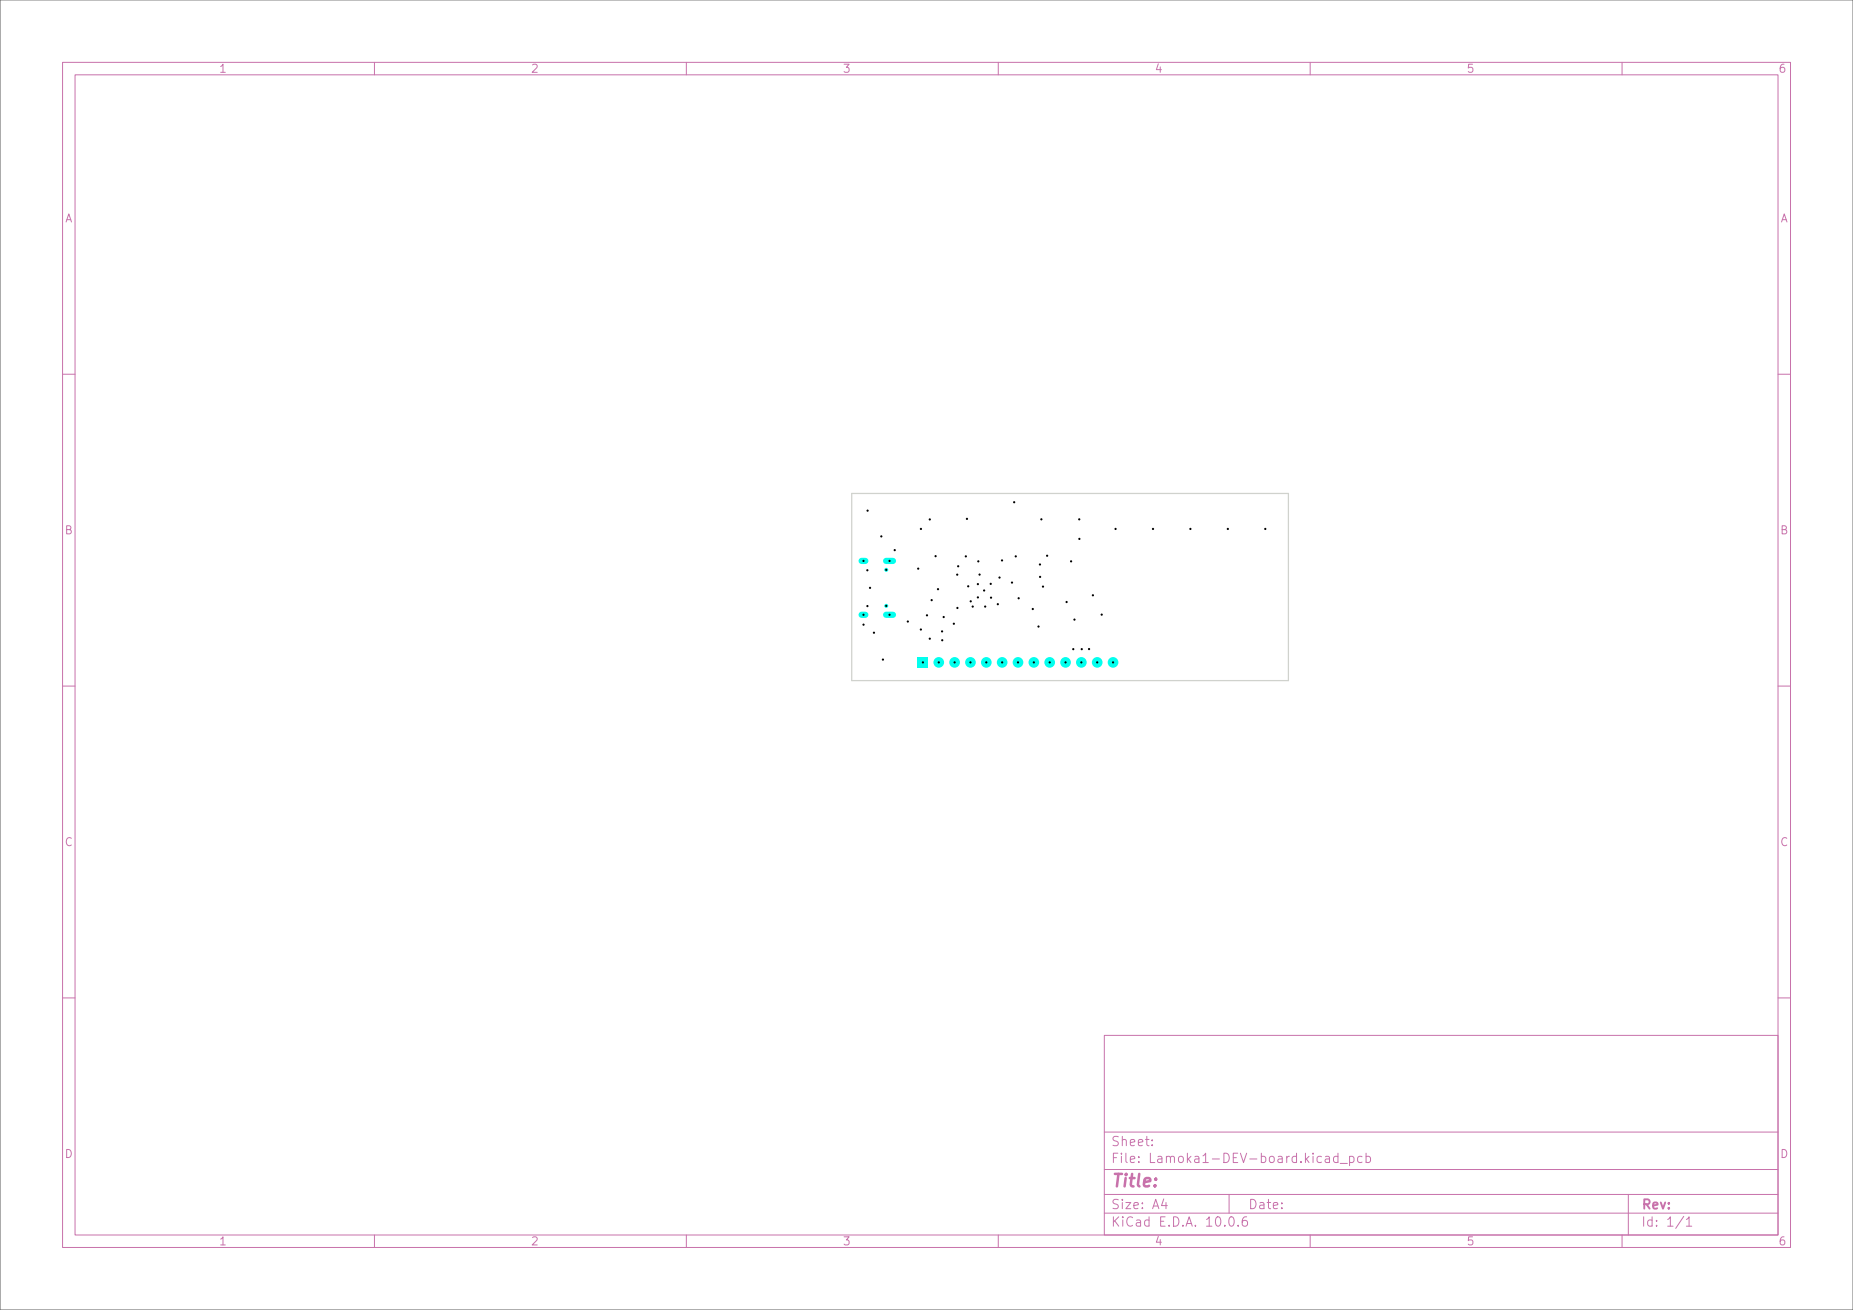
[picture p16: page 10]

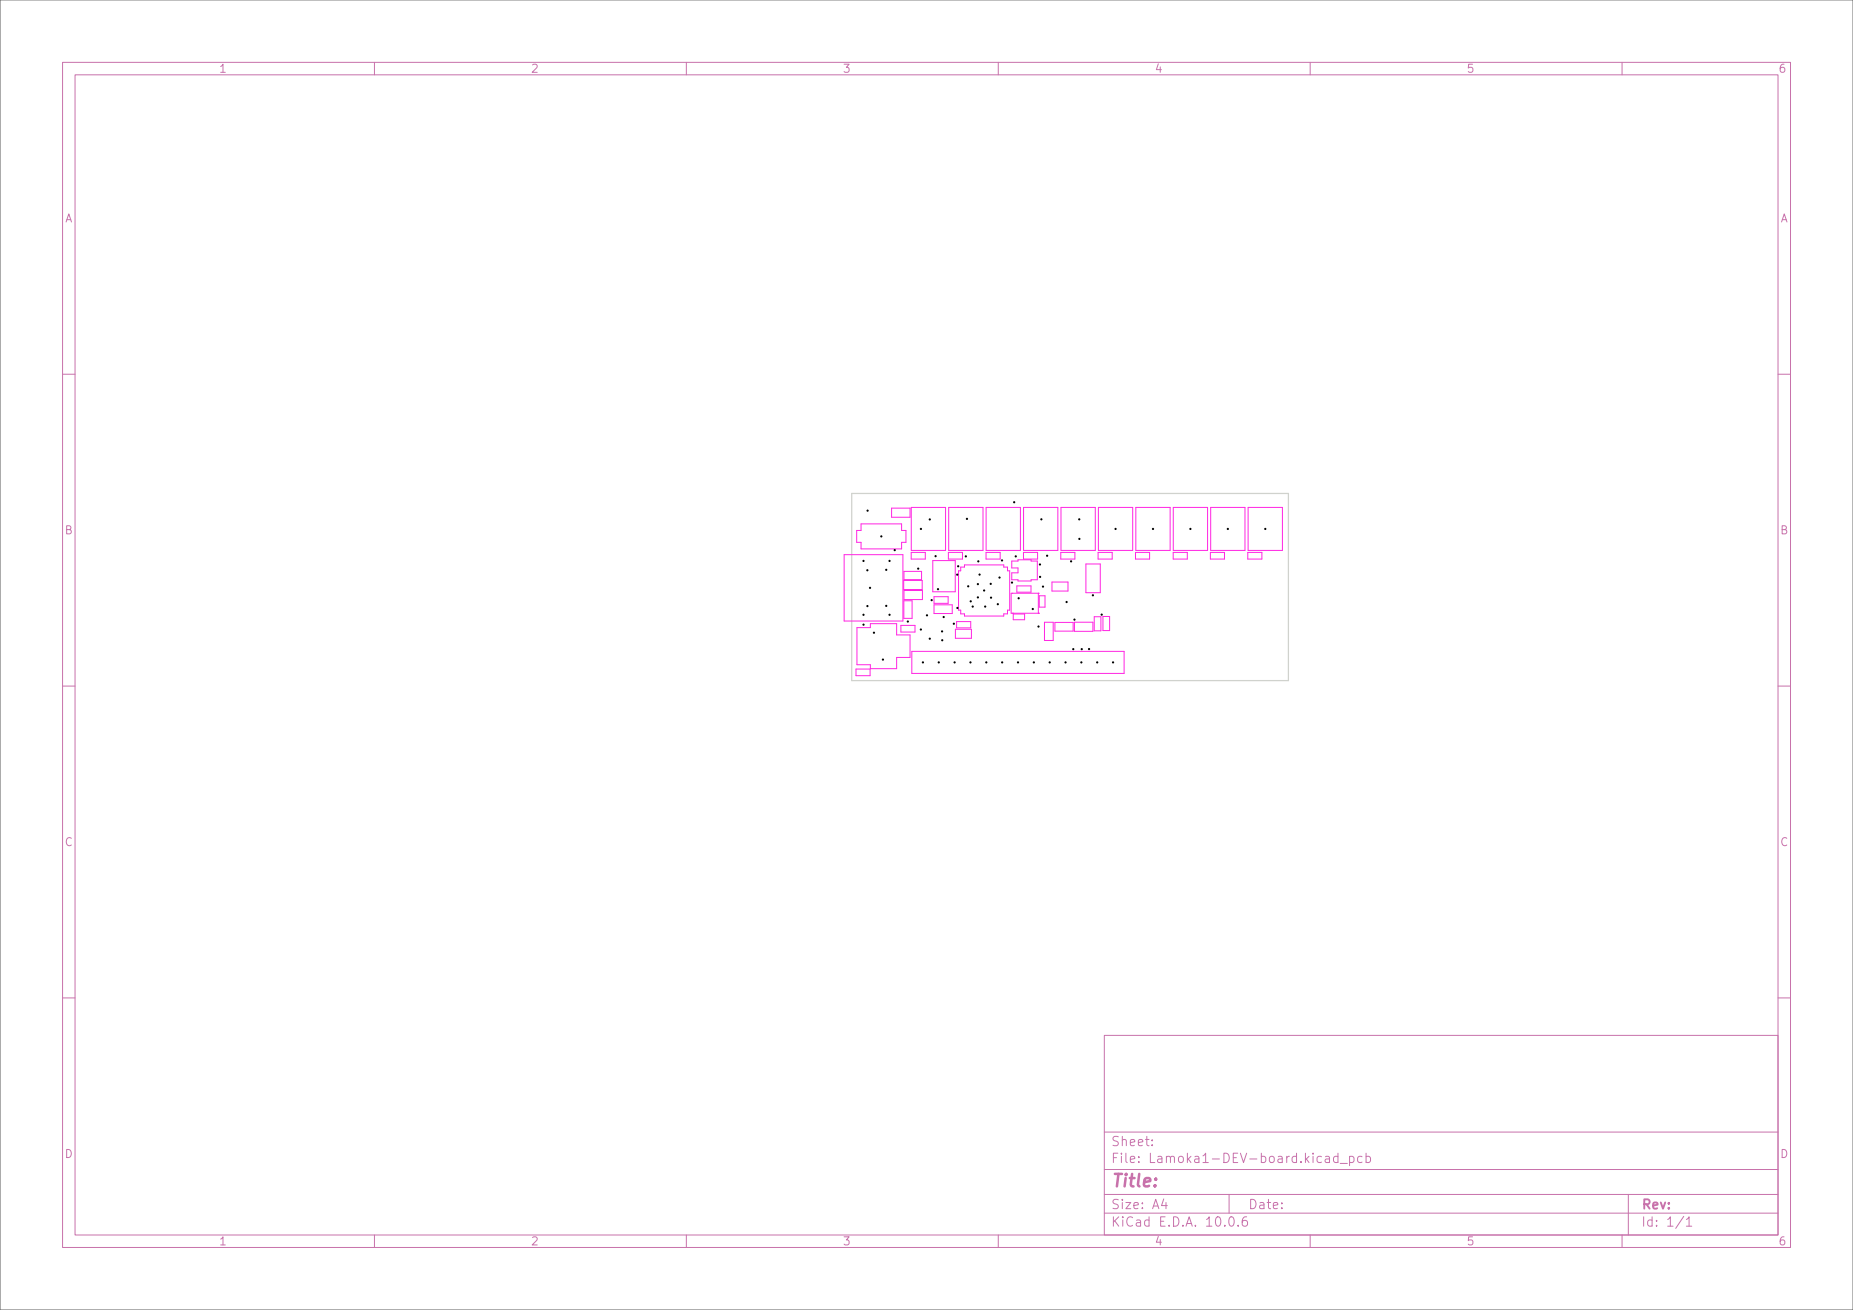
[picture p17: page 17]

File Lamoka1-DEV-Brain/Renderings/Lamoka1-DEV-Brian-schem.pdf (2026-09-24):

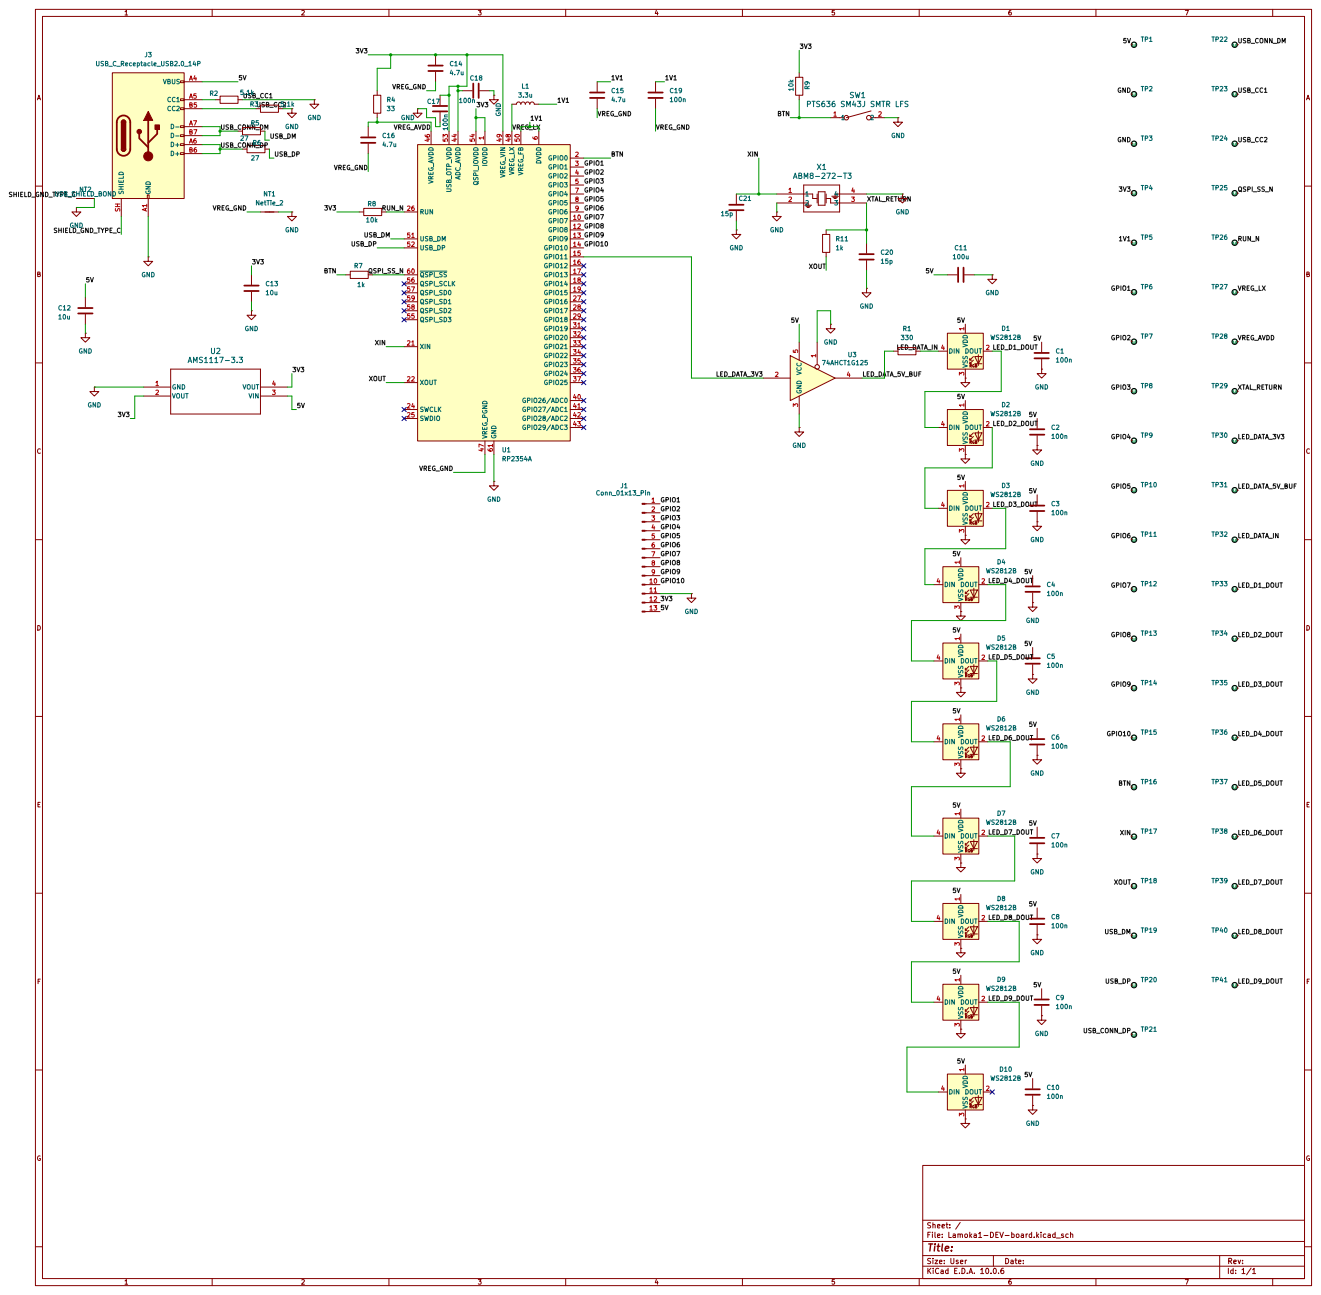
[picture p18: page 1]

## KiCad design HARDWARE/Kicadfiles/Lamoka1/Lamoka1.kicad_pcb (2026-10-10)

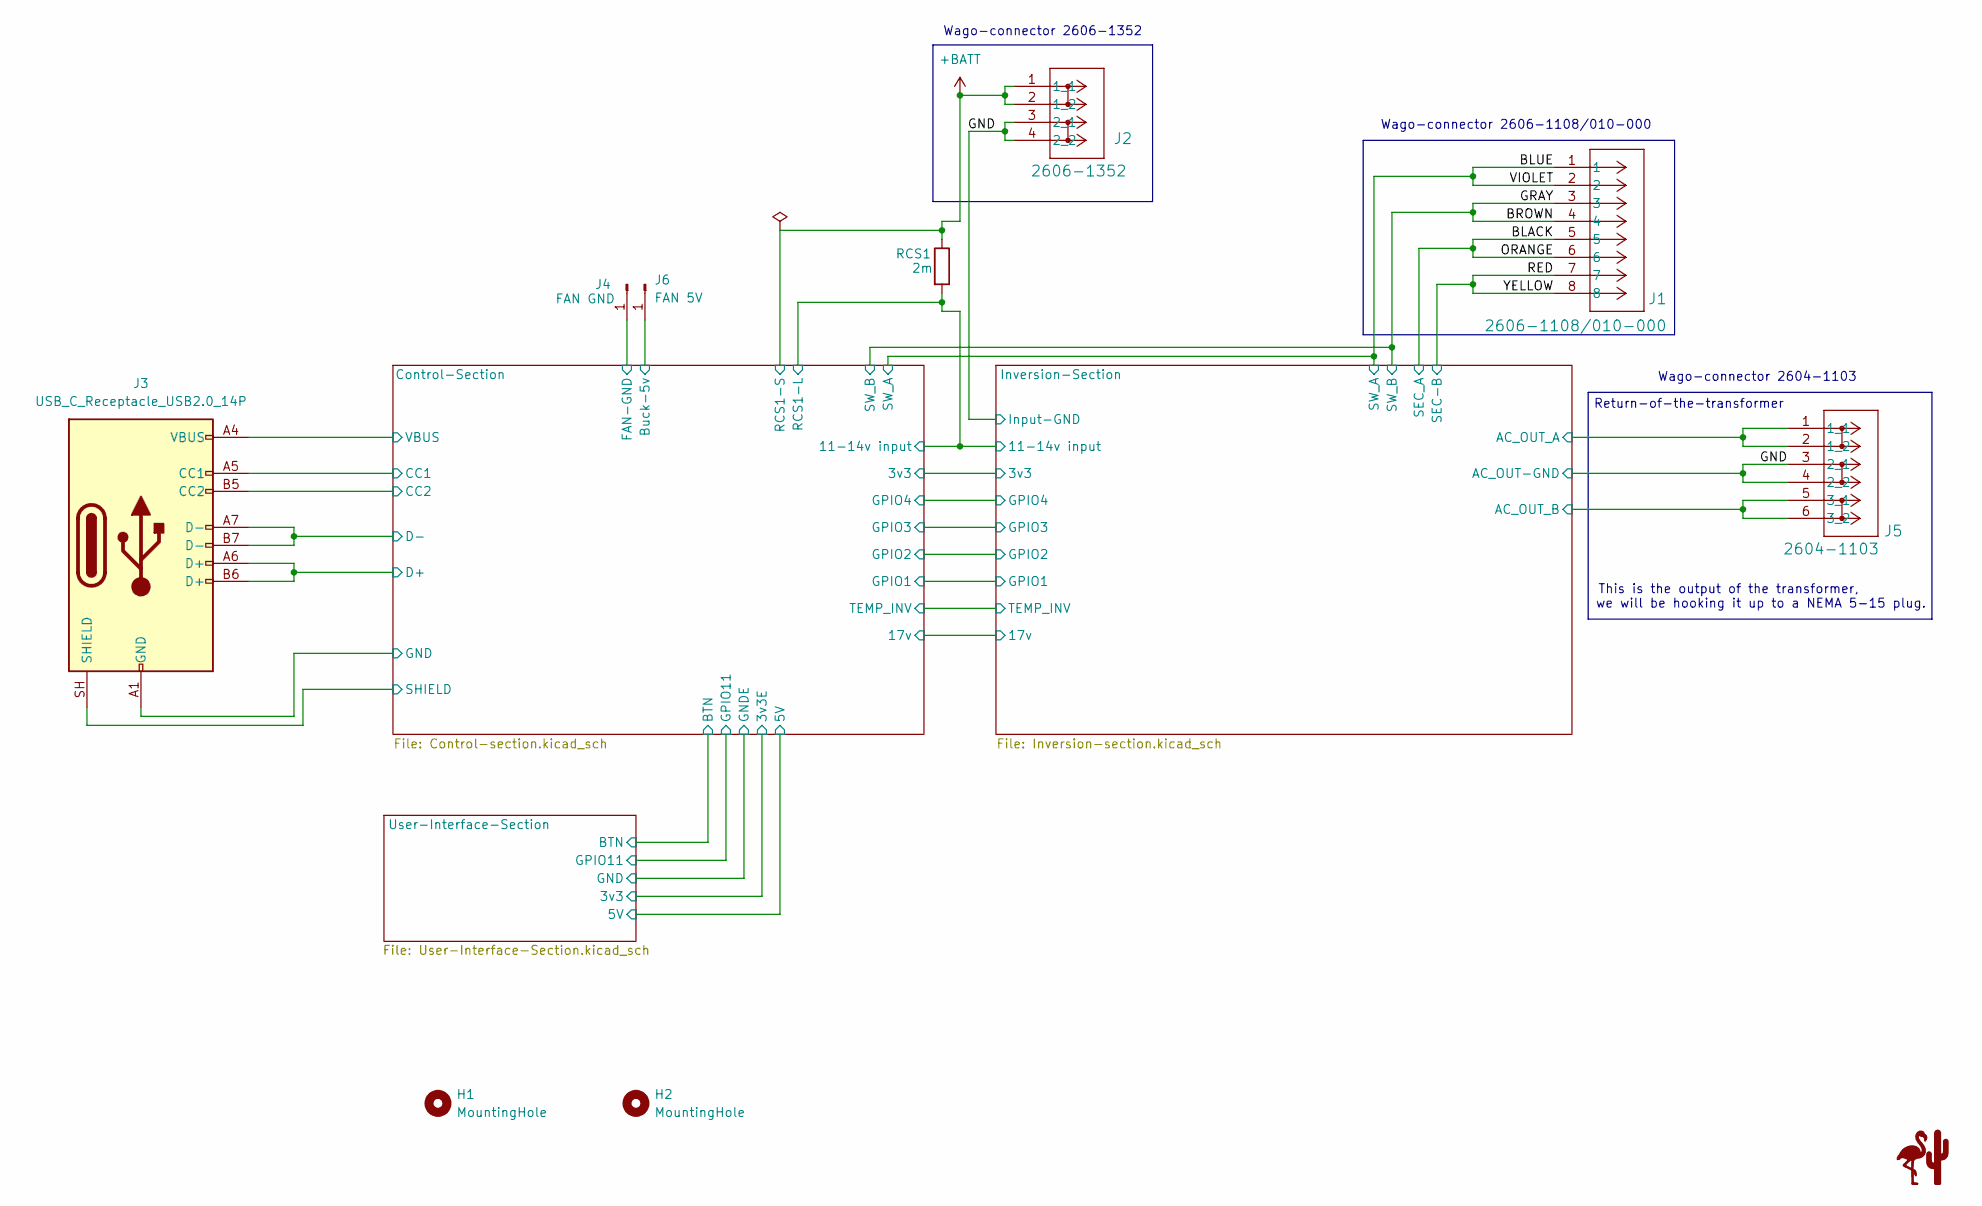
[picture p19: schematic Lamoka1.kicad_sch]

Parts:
H1, H2: MountingHole; MountingHole_3.2mm_M3
J1: 2606-1108/010-000; CONN8_2606-1108&slash_010-000_WAG
J2: 2606-1352; CONN2_2606-1352_WAG
J3: USB_C_Receptacle_USB2.0_14P; USB_C_Receptacle_HRO_TYPE-C-31-M-12; MPN TYPE-C-31-M-12
J4: FAN GND; SolderWirePad_1x01_SMD_3x6mm
J5: 2604-1103; CONN3_2604-1103_WAG
J6: FAN 5V; SolderWirePad_1x01_SMD_3x6mm
RCS1: 2m; R_2512_6332Metric; MPN CSNL2512FT2L00

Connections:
+BATT: J2.1 (1_1), J2.2 (1_2), RCS1.1; also elsewhere on the board
/BLACK: J1.5, J1.6, J5.1 (1_1), J5.2 (1_2)
/BLUE: J1.1, J1.2; also elsewhere on the board
/BROWN: J1.3, J1.4; also elsewhere on the board
/Control-Section/Buck-5v: J6.1 (Pin_1_1); also elsewhere on the board
/Control-Section/CC1: J3.A5 (CC1); also elsewhere on the board
/Control-Section/CC2: J3.B5 (CC2); also elsewhere on the board
/Control-Section/D+: J3.A6 (D+), J3.B6 (D+); also elsewhere on the board
/Control-Section/D-: J3.A7 (D-), J3.B7 (D-); also elsewhere on the board
/Control-Section/USB-5v: J3.A4 (VBUS), J3.A9 (VBUS), J3.B4 (VBUS), J3.B9 (VBUS); also elsewhere on the board
/Inversion-Section/CSP: RCS1.2; also elsewhere on the board
/RED: J1.7, J1.8, J5.5 (3_1), J5.6 (3_2)
GND: J2.3 (2_1), J2.4 (2_2), J3.A1 (GND), J3.A12 (GND), J3.B1 (GND), J3.B12 (GND), J3.SH (SHIELD), J4.1 (Pin_1_1), J5.3 (2_1), J5.4 (2_2); also elsewhere on the board

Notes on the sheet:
This is the output of the transformer,
Wago-connector 2606-1108/010-000
Wago-connector 2604-1103
Return-of-the-transformer
Wago-connector 2606-1352
we will be hooking it up to a NEMA 5-15 plug.

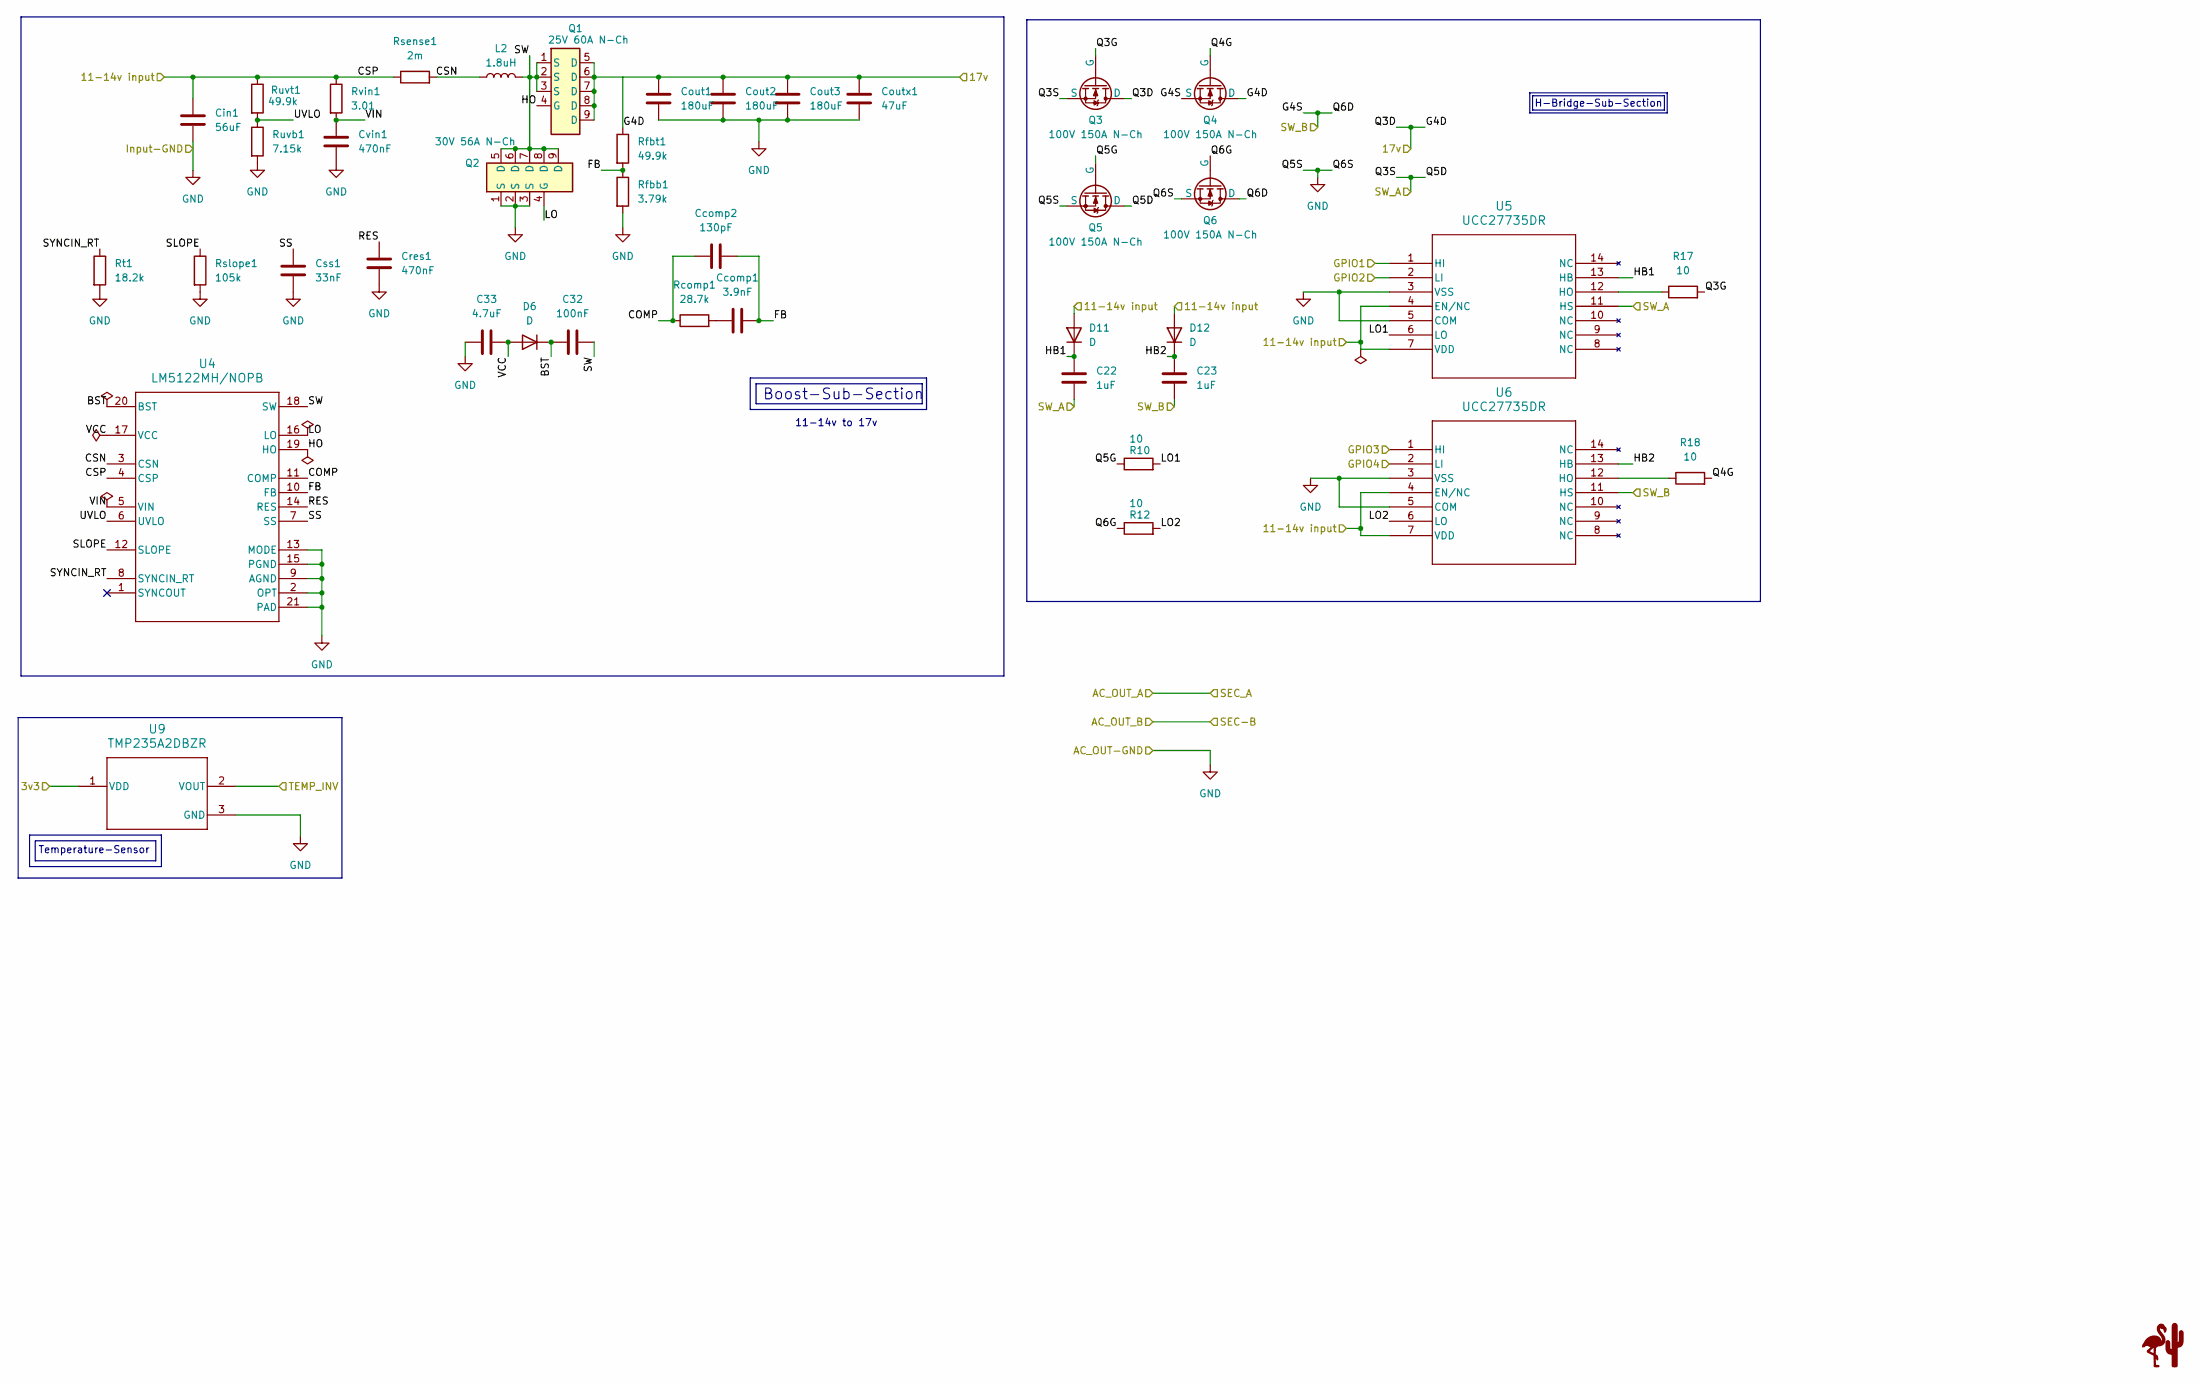
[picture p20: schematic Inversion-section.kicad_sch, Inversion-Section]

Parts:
C22, C23: 1uF; C_0805_2012Metric; MPN GRM21BR71H105KA12L
C32: 100nF; C_0805_2012Metric; MPN 08053C104KAT2A
C33: 4.7uF; C_0805_2012Metric; MPN MSAST21GAB5475MTNAO1
Ccomp1: 3.9nF; C_0805_2012Metric; MPN CGA4C2C0G1H392J060AA
Ccomp2: 130pF; C_0402_1005Metric; MPN GRM1555C1H131GA01D
Cin1: 56uF; CP_Elec_5x5.9; MPN 20SVPF56MX
Cout1, Cout2, Cout3: 180uF; CP_Elec_8x11.9; MPN 25SVPF180M
Coutx1: 47uF; C_1206_3216Metric; MPN C3216X5R1E476M160AC
Cres1: 470nF; C_0805_2012Metric; MPN TMK212BJ474KD-T
Css1: 33nF; C_0402_1005Metric; MPN GRM155R71A333KA01D
Cvin1: 470nF; C_0402_1005Metric; MPN C1005X5R1V474K050BC
D6: D; D_SMA; MPN SK215ATR
D11, D12: D; D_SMA; MPN SS14-E3/61T
L2: 1.8uH; L_Coilcraft_XAL1580-182; MPN XAL1580-182MEB
Q1: 25V 60A N-Ch; DQG0008A; MPN CSD16323Q3
Q2: 30V 56A N-Ch; DQG0008A; MPN CSD17304Q3
Q3, Q4, Q5, Q6: 100V 150A N-Ch; TO-220-3_Vertical; MPN CSD19536KCS
R10, R12, R17, R18: 10; R_1206_3216Metric; MPN RC1206FR-0710RL
Rcomp1: 28.7k; R_0201_0603Metric; MPN RC0201FR-0728K7L
Rfbb1: 3.79k; R_0402_1005Metric; MPN CRCW04023K79FKED
Rfbt1: 49.9k; R_0402_1005Metric; MPN CRCW040249K9FKED
Rsense1: 2m; R_1206_3216Metric; MPN CSNL1206FT2L00
Rslope1: 105k; R_0201_0603Metric; MPN RC0201FR-07105KL
Rt1: 18.2k; R_0402_1005Metric; MPN CRCW040218K2FKED
Ruvb1: 7.15k; R_0402_1005Metric; MPN CRCW04027K15FKED
Ruvt1: 49.9k; R_0402_1005Metric; MPN CRCW040249K9FKED
Rvin1: 3.01; R_0402_1005Metric; MPN CRCW04023R01FKED
U4: LM5122MH/NOPB; PWP20_3P0X4P2; MPN LM5122MH/NOPB
U5, U6: UCC27735DR; SOIC_14L_TEX; MPN UCC27735DR
U9: TMP235A2DBZR; DBZ0003A-IPC_A; MPN TMP235A2DBZR

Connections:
/BLUE: C22.2, Q3.3 (S), Q5.2 (D), U5.11 (HS); also elsewhere on the board
/BROWN: C23.2, Q4.3 (S), Q6.2 (D), U6.11 (HS); also elsewhere on the board
/Control-Section/3v3: U9.1 (VDD); also elsewhere on the board
/Control-Section/GPIO1: U5.1 (HI); also elsewhere on the board
/Control-Section/GPIO2: U5.2 (LI); also elsewhere on the board
/Control-Section/GPIO3: U6.1 (HI); also elsewhere on the board
/Control-Section/GPIO4: U6.2 (LI); also elsewhere on the board
/Control-Section/TEMP_INV: U9.2 (VOUT); also elsewhere on the board
/Inversion-Section/BST: C32.1, D6.1 (K), U4.20 (BST)
/Inversion-Section/COMP: Ccomp2.1, Rcomp1.1, U4.11 (COMP)
/Inversion-Section/CSN: L2.1, Rsense1.2, U4.3 (CSN)
/Inversion-Section/CSP: Cin1.1, D11.2 (A), D12.2 (A), Rsense1.1, Ruvt1.1, Rvin1.1, U4.4 (CSP), U5.4 (EN/NC), U5.7 (VDD), U6.4 (EN/NC), U6.7 (VDD); also elsewhere on the board
/Inversion-Section/FB: Ccomp1.2, Ccomp2.2, Rfbb1.1, Rfbt1.2, U4.10 (FB)
/Inversion-Section/G4D: Cout1.1, Cout2.1, Cout3.1, Coutx1.1, Q1.5 (D), Q1.6 (D), Q1.7 (D), Q1.8 (D), Q1.9 (D), Q3.2 (D), Q4.2 (D), Rfbt1.1; also elsewhere on the board
/Inversion-Section/HB1: C22.1, D11.1 (K), U5.13 (HB)
/Inversion-Section/HB2: C23.1, D12.1 (K), U6.13 (HB)
/Inversion-Section/HO: Q1.4 (G), U4.19 (HO)
/Inversion-Section/LO: Q2.4 (G), U4.16 (LO)
/Inversion-Section/LO1: R10.2, U5.6 (LO)
/Inversion-Section/LO2: R12.2, U6.6 (LO)
/Inversion-Section/Q3G: Q3.1 (G), R17.2
/Inversion-Section/Q4G: Q4.1 (G), R18.2
/Inversion-Section/Q5G: Q5.1 (G), R10.1
/Inversion-Section/Q6G: Q6.1 (G), R12.1
/Inversion-Section/RES: Cres1.1, U4.14 (RES)
/Inversion-Section/SLOPE: Rslope1.1, U4.12 (SLOPE)
/Inversion-Section/SS: Css1.1, U4.7 (SS)
/Inversion-Section/SW: C32.2, L2.2, Q1.1 (S), Q1.2 (S), Q1.3 (S), Q2.5 (D), Q2.6 (D), Q2.7 (D), Q2.8 (D), Q2.9 (D), U4.18 (SW)
/Inversion-Section/SYNCIN_RT: Rt1.1, U4.8 (SYNCIN_RT)
/Inversion-Section/UVLO: Ruvb1.1, Ruvt1.2, U4.6 (UVLO)
/Inversion-Section/VCC: C33.2, D6.2 (A), U4.17 (VCC)
/Inversion-Section/VIN: Cvin1.1, Rvin1.2, U4.5 (VIN)
GND: C33.1, Cin1.2, Cout1.2, Cout2.2, Cout3.2, Coutx1.2, Cres1.2, Css1.2, Cvin1.2, Q2.1 (S), Q2.2 (S), Q2.3 (S), Q5.3 (S), Q6.3 (S), Rfbb1.2, Rslope1.2, Rt1.2, Ruvb1.2, U4.2 (OPT), U4.9 (AGND), U4.13 (MODE), U4.15 (PGND), U4.21 (PAD), U5.3 (VSS), U5.5 (COM), U6.3 (VSS), U6.5 (COM), U9.3 (GND); also elsewhere on the board
unnamed: Ccomp1.1, Rcomp1.2
unnamed: R17.1, U5.12 (HO)
unnamed: R18.1, U6.12 (HO)

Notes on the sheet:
11-14v to 17v
H-Bridge-Sub-Section
Boost-Sub-Section
Temperature-Sensor

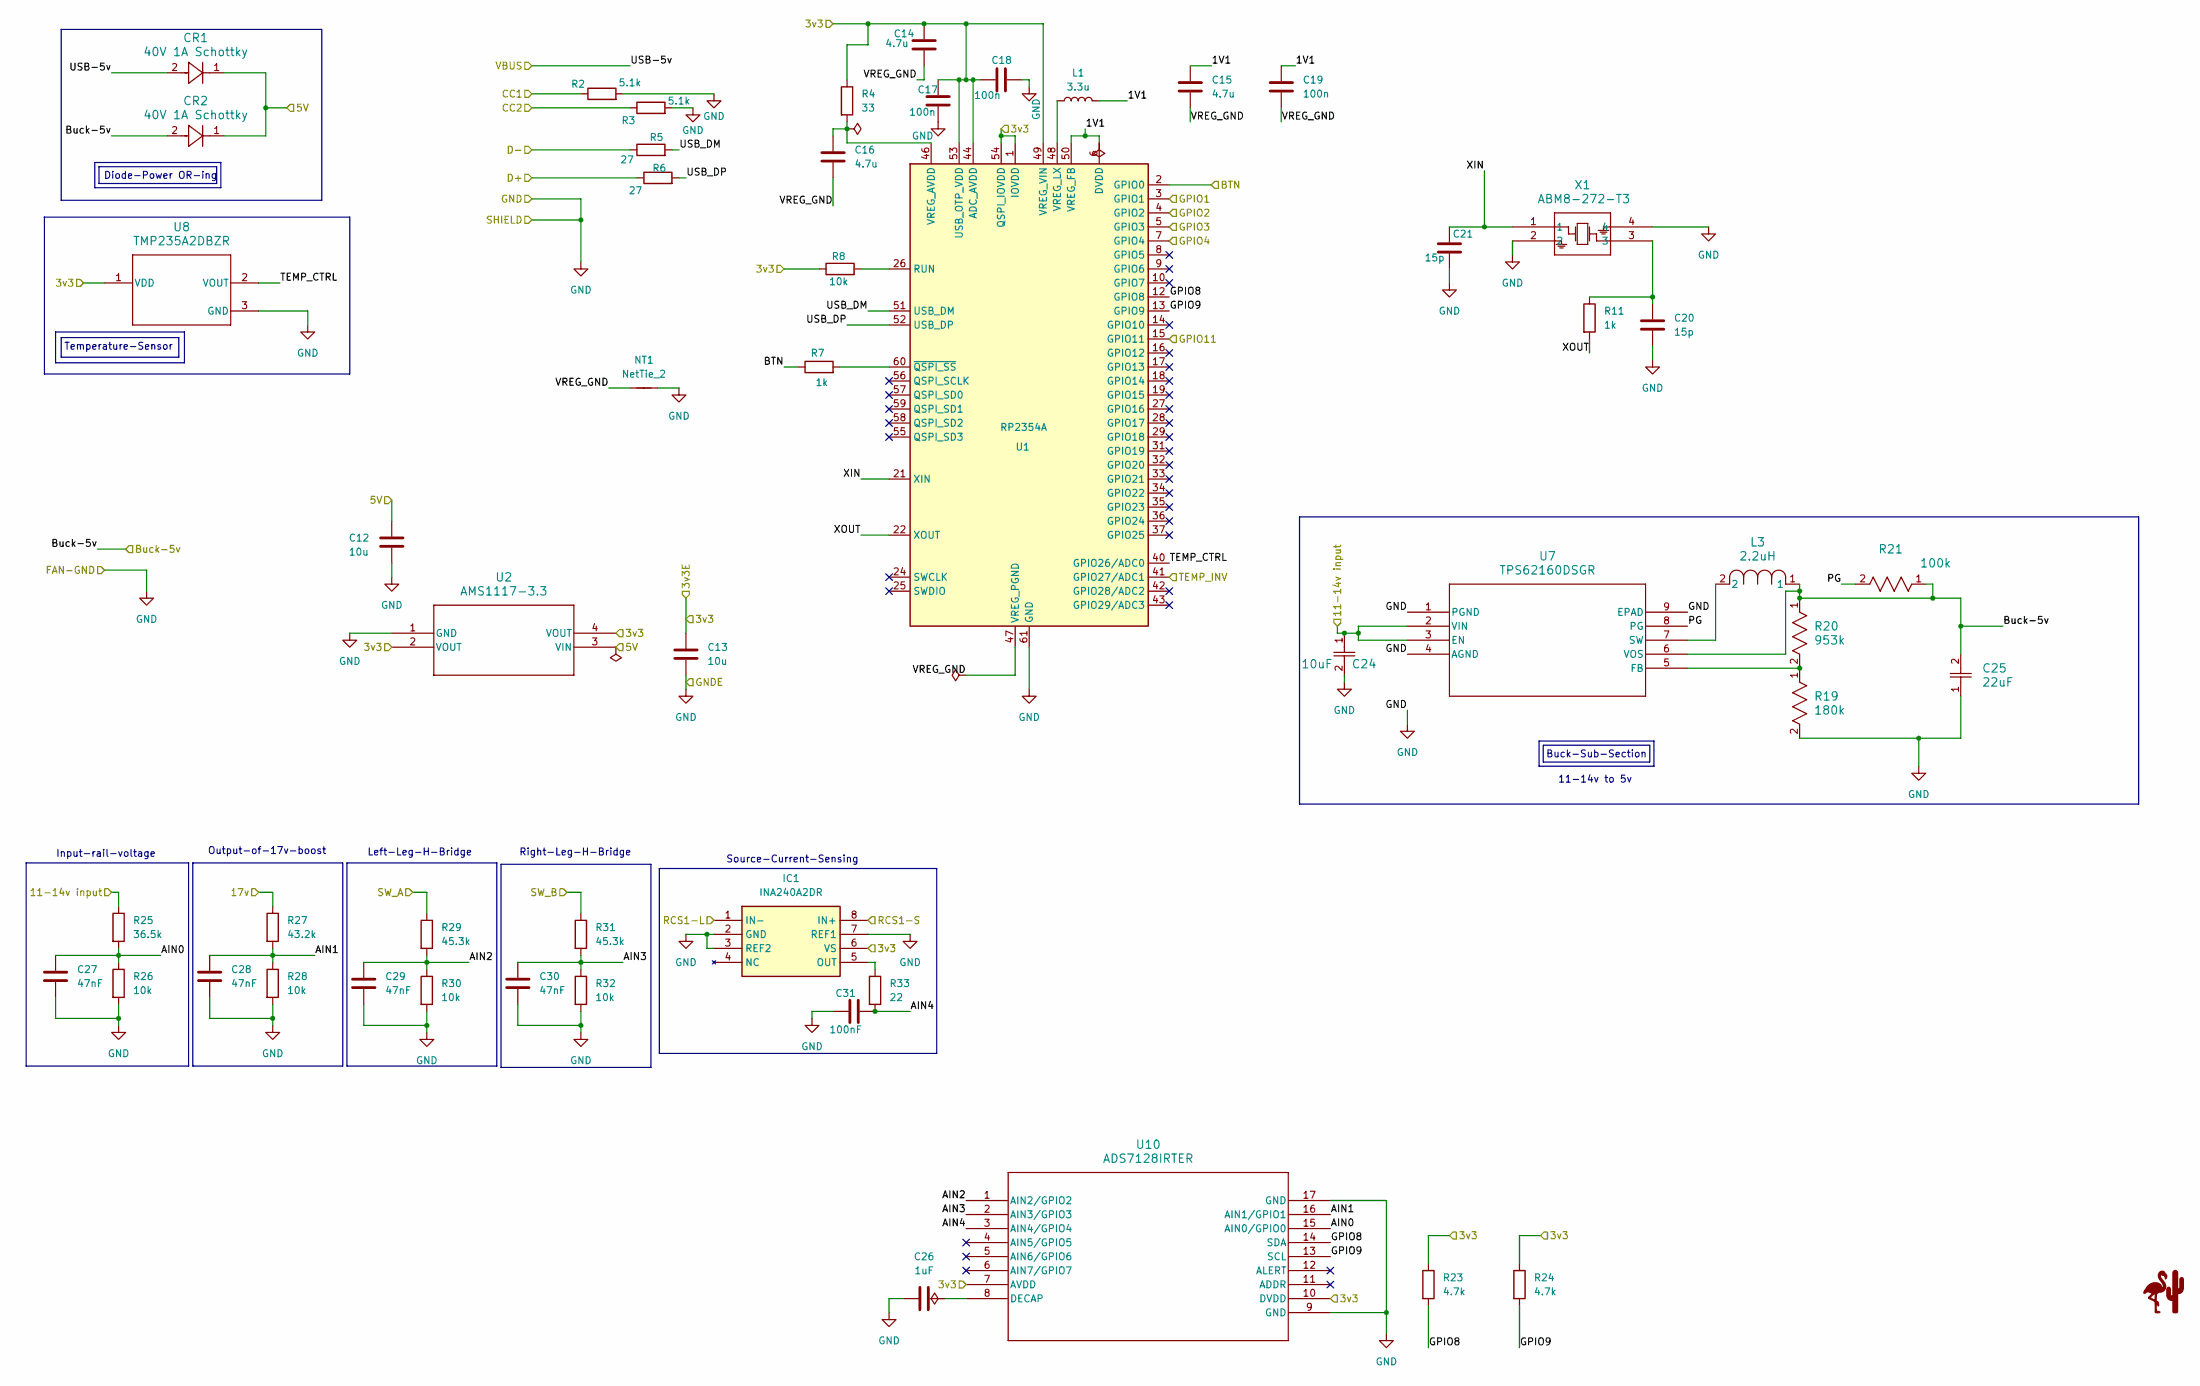
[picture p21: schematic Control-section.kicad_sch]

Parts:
C12, C13: 10u; C_0402_1005Metric; MPN CL05A106MQ5NUNC
C14, C15, C16: 4.7u; C_0603_1608Metric; MPN CL10A475KP8NNNC
C17, C18, C19: 100n; C_0402_1005Metric; MPN CL05B104KO5NNNC
C20, C21: 15p; C_0402_1005Metric; MPN 0402CG150J500NT
C24: 10uF; CAPC2114X145N; MPN TMK212BBJ106KG-T
C25: 22uF; G-31_MUR; MPN GRM31CR71A226KE15L
C26: 1uF; C_0603_1608Metric; MPN CL10A105KA8NNNC
C27, C28, C29, C30: 47nF; C_0603_1608Metric; MPN CL10B473KB8NNNC
C31: 100nF; C_0603_1608Metric; MPN CL10B104KB8NNNC
CR1, CR2: 40V 1A Schottky; DO-214AC_VIS; MPN SS14-E3/61T
IC1: INA240A2DR; SOIC127P600X175-8N; MPN INA240A2DR; Mouser Part Number 595-INA240A2DR
L1: 3.3u; AOTAB201610S3R3101T; MPN AOTA-B201610S3R3-101-T
L3: 2.2uH; IND_PA4332.222NLT_PUL; MPN PA4332.222NLT
NT1: NetTie_2; NetTie-2_SMD_Pad0.5mm
R2, R3: 5.1k; RC0603N_YAG; MPN RC0603FR-075K1L
R4: 33; R_0603_1608Metric; MPN RC0603FR-0733RL
R5, R6: 27; R_0603_1608Metric; MPN RC0603FR-0727RL
R7, R11: 1k; R_0402_1005Metric; MPN RC0402FR-071KL
R8, R26, R28, R30, R32: 10k; R_0603_1608Metric; MPN RC0603FR-0710KL
R19: 180k; RC0603N_YAG; MPN RC0603FR-07180KL
R20: 953k; RC0402N_VIS; MPN CRCW0402953KFKED
R21: 100k; RES_CRCW_0402_VIS; MPN CRCW0402100KFKED
R23, R24: 4.7k; R_0603_1608Metric; MPN RC0603FR-074K7L
R25: 36.5k; R_0603_1608Metric; MPN RC0603FR-0736K5L
R27: 43.2k; R_0603_1608Metric; MPN RC0603FR-0743K2L
R29, R31: 45.3k; R_0603_1608Metric; MPN RC0603FR-0745K3L
R33: 22; R_0603_1608Metric; MPN RC0603FR-0722RL
U1: RP2354A; QFN-60-1EP_7x7mm_P0.4mm_EP3.4x3.4mm; MPN RP2354A
U2: AMS1117-3.3; SOT-223-3_TabPin2; MPN AMS1117-3.3
U7: TPS62160DSGR; DSG8_1P6X0P9; MPN TPS62160DSGR
U8: TMP235A2DBZR; DBZ0003A-IPC_A; MPN TMP235A2DBZR
U10: ADS7128IRTER; WQFN16_RTE_TEX; MPN ADS7128IRTER
X1: ABM8-272-T3; ABM8272T3; MPN ABM8-272-T3

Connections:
+BATT: IC1.8 (IN+); also elsewhere on the board
/BLUE: R29.1; also elsewhere on the board
/BROWN: R31.1; also elsewhere on the board
/Control-Section/1V1: C15.1, C19.1, L1.2, U1.6 (DVDD), U1.23 (DVDD), U1.39 (DVDD), U1.50 (VREG_FB)
/Control-Section/3v3: C13.1, C14.1, C17.1, C18.1, IC1.6 (VS), R4.1, R8.1, R23.1, R24.1, U1.1 (IOVDD), U1.11 (IOVDD), U1.20 (IOVDD), U1.30 (IOVDD), U1.38 (IOVDD), U1.44 (ADC_AVDD), U1.45 (IOVDD), U1.49 (VREG_VIN), U1.53 (USB_OTP_VDD), U1.54 (QSPI_IOVDD), U2.2 (VOUT), U2.4 (VOUT), U8.1 (VDD), U10.7 (AVDD), U10.10 (DVDD); also elsewhere on the board
/Control-Section/5V: C12.2, CR1.1, CR2.1, U2.3 (VIN); also elsewhere on the board
/Control-Section/AIN0: C27.1, R25.2, R26.1, U10.15 (AIN0/GPIO0)
/Control-Section/AIN1: C28.1, R27.2, R28.1, U10.16 (AIN1/GPIO1)
/Control-Section/AIN2: C29.1, R29.2, R30.1, U10.1 (AIN2/GPIO2)
/Control-Section/AIN3: C30.1, R31.2, R32.1, U10.2 (AIN3/GPIO3)
/Control-Section/AIN4: C31.1, R33.2, U10.3 (AIN4/GPIO4)
/Control-Section/BTN: R7.1, U1.2 (GPIO0); also elsewhere on the board
/Control-Section/Buck-5v: C25.2, CR2.2, L3.1, R20.1, R21.1, U7.6 (VOS); also elsewhere on the board
/Control-Section/CC1: R2.1; also elsewhere on the board
/Control-Section/CC2: R3.1; also elsewhere on the board
/Control-Section/D+: R6.1; also elsewhere on the board
/Control-Section/D-: R5.1; also elsewhere on the board
/Control-Section/GPIO1: U1.3 (GPIO1); also elsewhere on the board
/Control-Section/GPIO2: U1.4 (GPIO2); also elsewhere on the board
/Control-Section/GPIO3: U1.5 (GPIO3); also elsewhere on the board
/Control-Section/GPIO4: U1.7 (GPIO4); also elsewhere on the board
/Control-Section/GPIO8: R23.2, U1.12 (GPIO8), U10.14 (SDA)
/Control-Section/GPIO9: R24.2, U1.13 (GPIO9), U10.13 (SCL)
/Control-Section/GPIO11: U1.15 (GPIO11); also elsewhere on the board
/Control-Section/PG: R21.2, U7.8 (PG)
/Control-Section/TEMP_CTRL: U1.40 (GPIO26/ADC0), U8.2 (VOUT)
/Control-Section/TEMP_INV: U1.41 (GPIO27/ADC1); also elsewhere on the board
/Control-Section/USB-5v: CR1.2; also elsewhere on the board
/Control-Section/USB_DM: R5.2, U1.51 (USB_DM)
/Control-Section/USB_DP: R6.2, U1.52 (USB_DP)
/Control-Section/VREG_GND: C14.2, C15.2, C16.2, C19.2, NT1.1, U1.47 (VREG_PGND)
/Control-Section/XIN: C21.1, U1.21 (XIN), X1.1
/Control-Section/XOUT: R11.2, U1.22 (XOUT)
/Inversion-Section/CSP: C24.1, IC1.1 (IN-), R25.1, U7.2 (VIN), U7.3 (EN); also elsewhere on the board
/Inversion-Section/G4D: R27.1; also elsewhere on the board
GND: C12.1, C13.2, C17.2, C18.2, C20.2, C21.2, C24.2, C25.1, C26.2, C27.2, C28.2, C29.2, C30.2, C31.2, IC1.2 (GND), IC1.3 (REF2), IC1.7 (REF1), NT1.2, R2.2, R3.2, R19.2, R26.2, R28.2, R30.2, R32.2, U1.61 (GND), U2.1 (GND), U7.1 (PGND), U7.4 (AGND), U7.9 (EPAD), U8.3 (GND), U10.9 (GND), U10.17 (GND), X1.2, X1.4; also elsewhere on the board
unnamed: C20.1, R11.1, X1.3
unnamed: IC1.5 (OUT), R33.1
unnamed: R8.2, U1.26 (RUN)
unnamed: C16.1, R4.2, U1.46 (VREG_AVDD)
unnamed: L1.1, U1.48 (VREG_LX)
unnamed: R7.2, U1.60 (~QSPI_SS)
unnamed: R19.1, R20.2, U7.5 (FB)
unnamed: L3.2, U7.7 (SW)
unnamed: C26.1, U10.8 (DECAP)

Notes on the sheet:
Left-Leg-H-Bridge
Source-Current-Sensing
Input-rail-voltage
11-14v to 5v
Right-Leg-H-Bridge
Output-of-17v-boost
Temperature-Sensor
Diode-Power OR-ing
Buck-Sub-Section

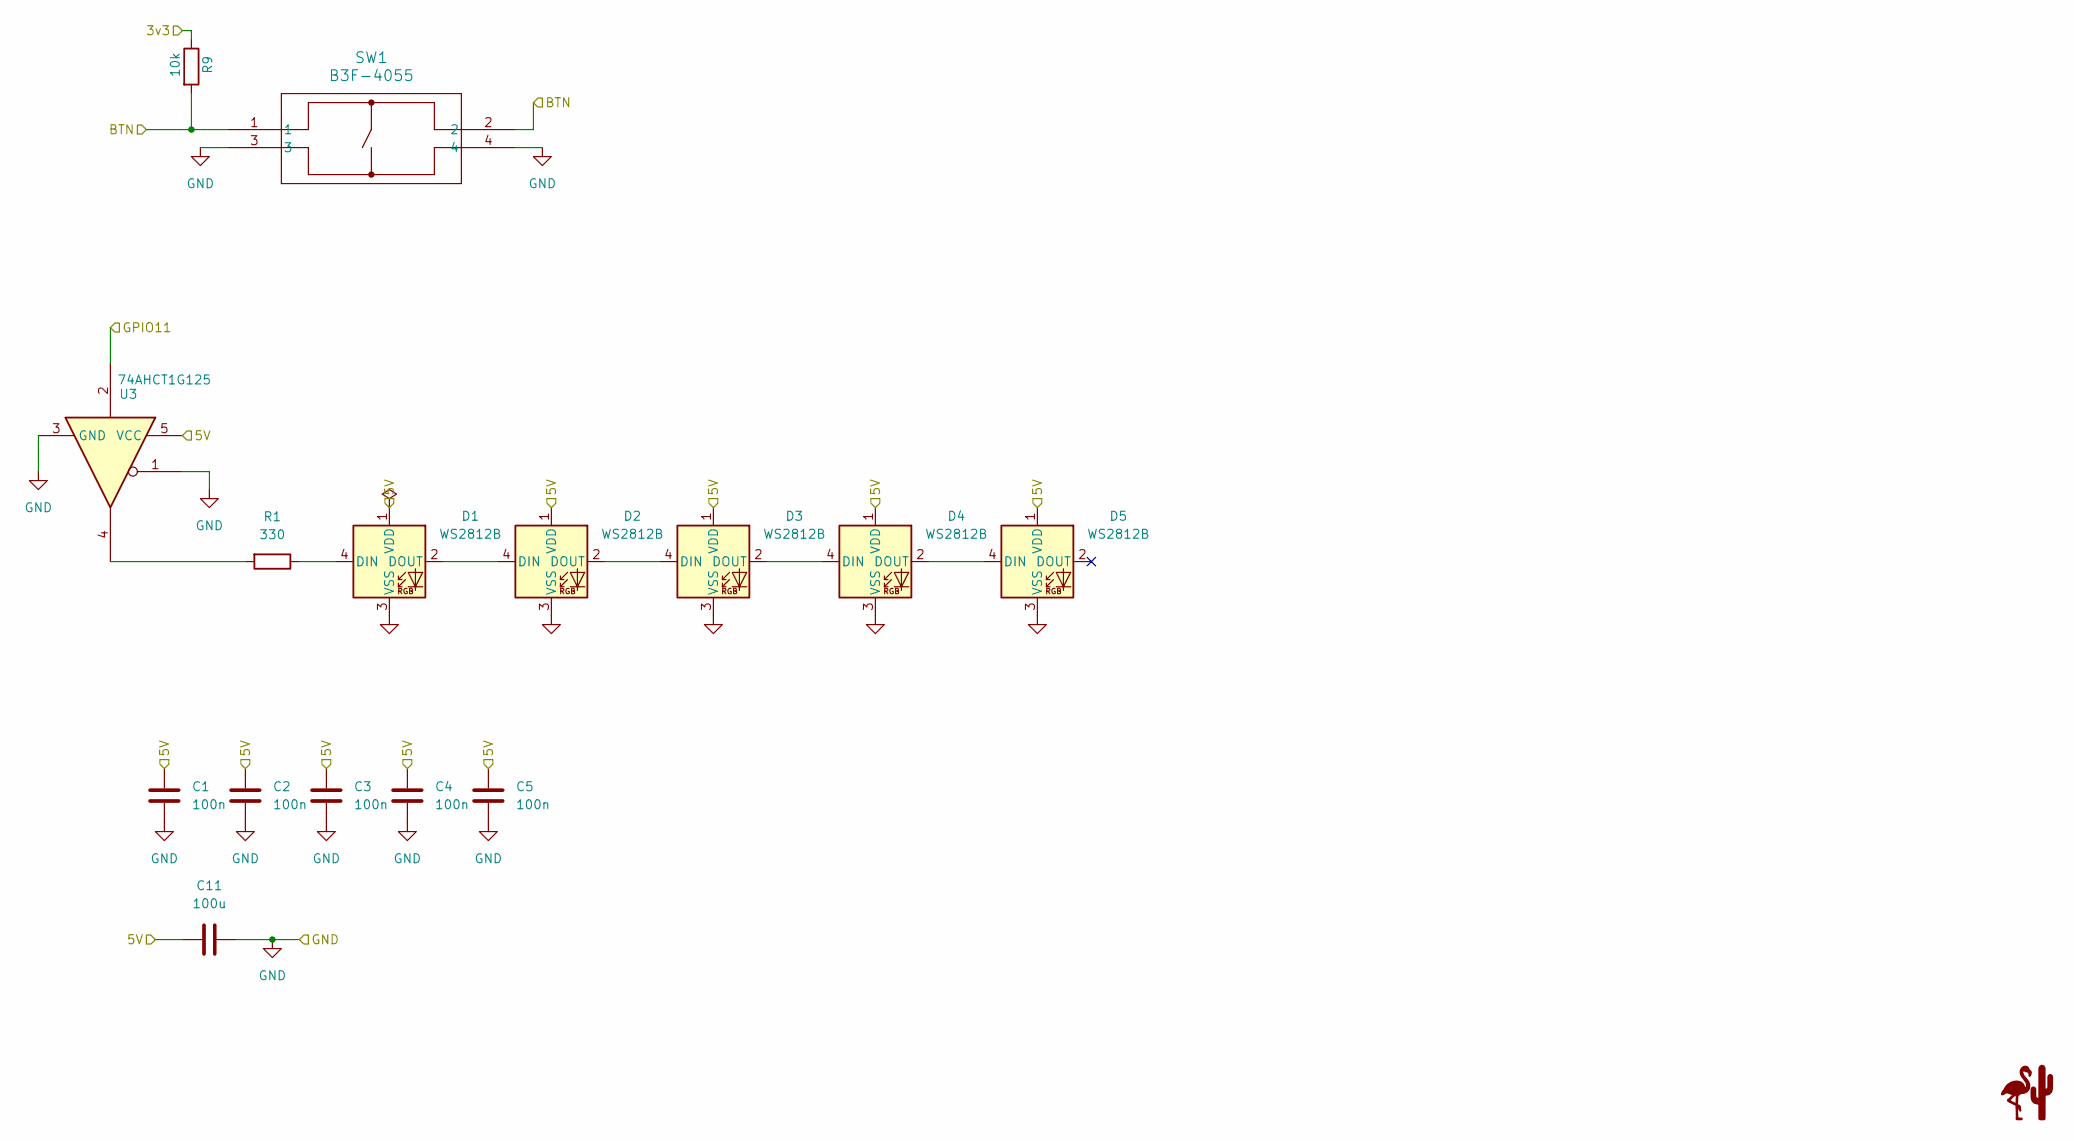
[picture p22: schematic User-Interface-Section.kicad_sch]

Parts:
C1, C2, C3, C4, C5: 100n; C_0603_1608Metric; MPN CL10B104KO8NNNC
C11: 100u; C_1206_3216Metric; MPN GRM31CR61A107MEA8K
D1, D2, D3, D4, D5: WS2812B; LED_WS2812B_PLCC4_5.0x5.0mm_P3.2mm; MPN WS2812B
R1: 330; R_0603_1608Metric; MPN RC0603FR-07330RL
R9: 10k; R_0603_1608Metric; MPN RC0603FR-0710KL
SW1: B3F-4055; SW_B3F-4050_OMR; MPN B3F-4055
U3: 74AHCT1G125; SOT-23-5; MPN SN74AHCT1G125DBVR

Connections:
/Control-Section/3v3: R9.1; also elsewhere on the board
/Control-Section/5V: C1.1, C2.1, C3.1, C4.1, C5.1, C11.1, D1.1 (VDD), D2.1 (VDD), D3.1 (VDD), D4.1 (VDD), D5.1 (VDD), U3.5 (VCC); also elsewhere on the board
/Control-Section/BTN: R9.2, SW1.1, SW1.2; also elsewhere on the board
/Control-Section/GPIO11: U3.2; also elsewhere on the board
GND: C1.2, C2.2, C3.2, C4.2, C5.2, C11.2, D1.3 (VSS), D2.3 (VSS), D3.3 (VSS), D4.3 (VSS), D5.3 (VSS), SW1.3, SW1.4, U3.1, U3.3 (GND); also elsewhere on the board
unnamed: D1.4 (DIN), R1.1
unnamed: D1.2 (DOUT), D2.4 (DIN)
unnamed: D2.2 (DOUT), D3.4 (DIN)
unnamed: D3.2 (DOUT), D4.4 (DIN)
unnamed: D4.2 (DOUT), D5.4 (DIN)
unnamed: R1.2, U3.4

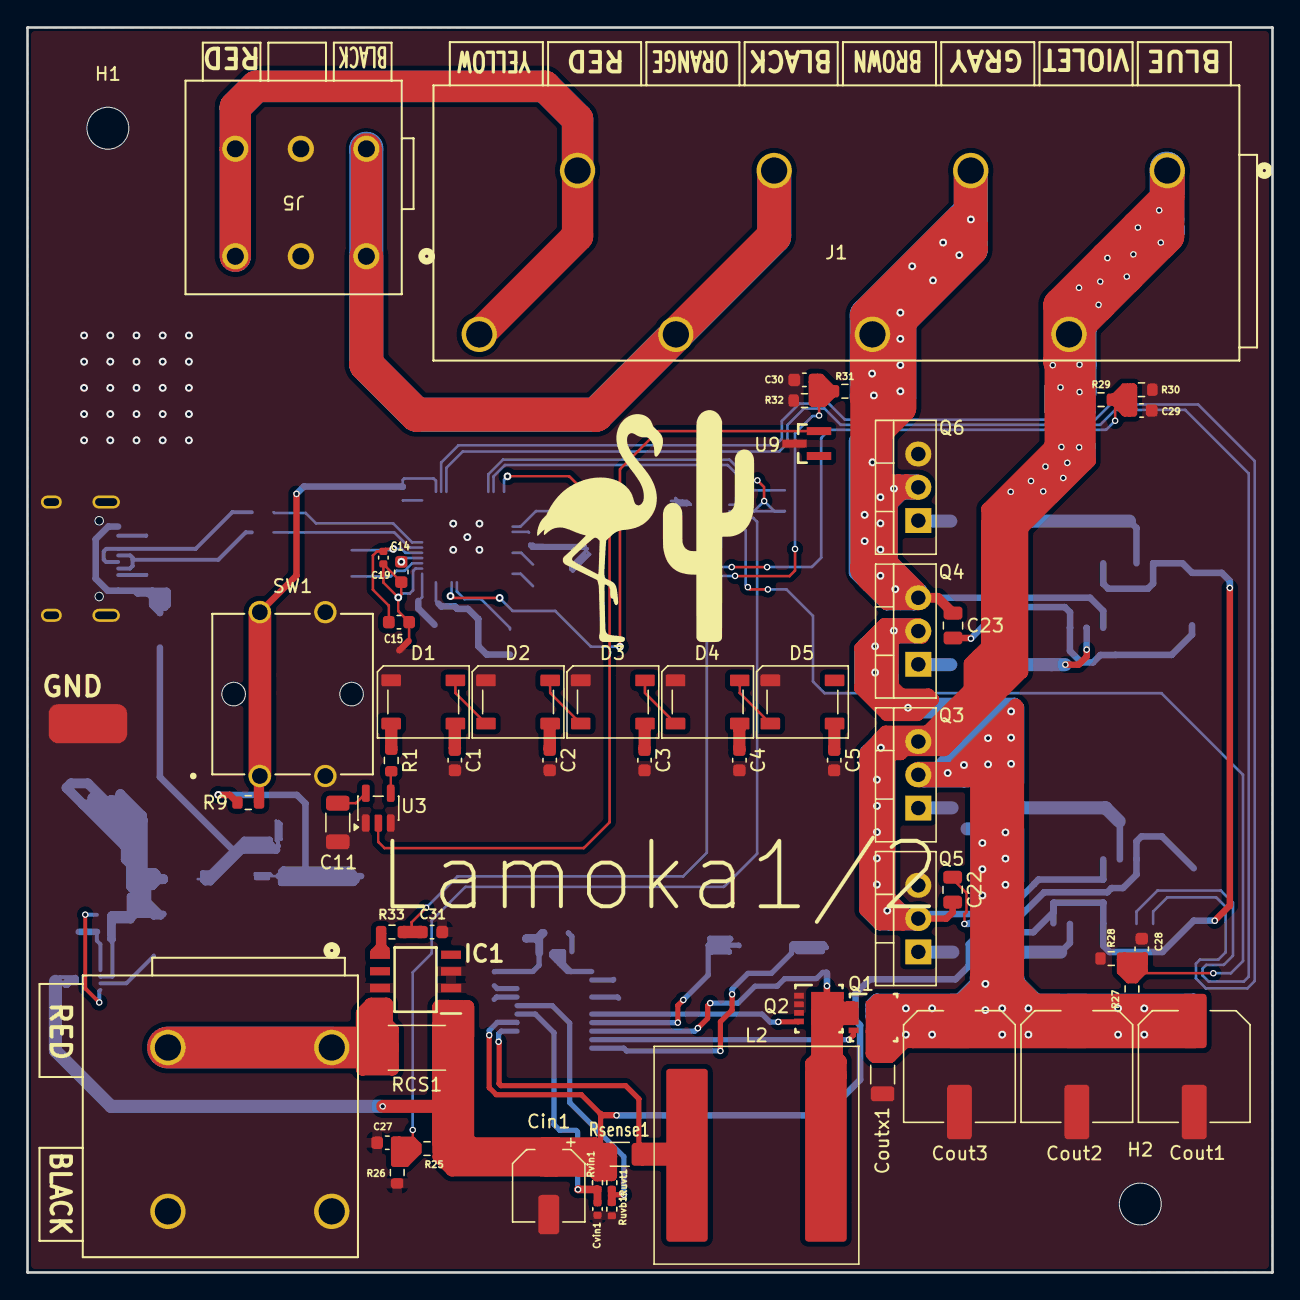
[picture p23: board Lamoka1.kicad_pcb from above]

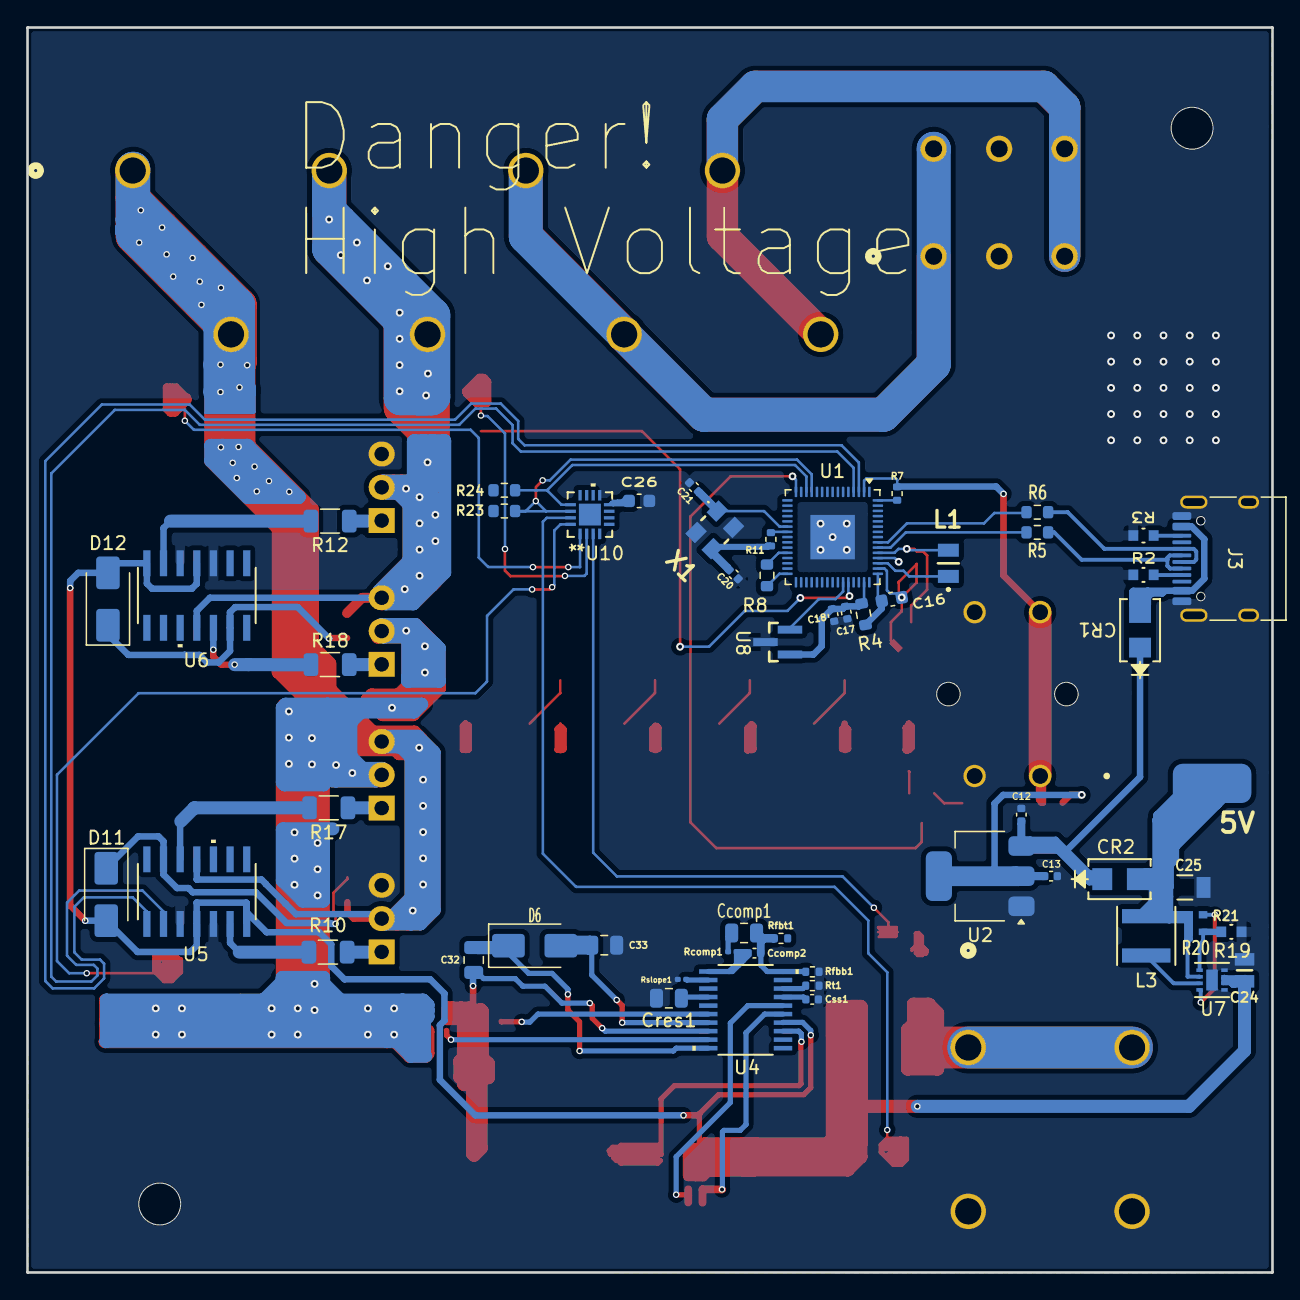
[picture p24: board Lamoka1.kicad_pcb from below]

Board: 2 copper layers, 95.0 x 95.0 mm, 117 parts (56 on the bottom side), 78 nets.

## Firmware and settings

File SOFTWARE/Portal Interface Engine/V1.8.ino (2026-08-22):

#include <Arduino.h>
#include <FastLED.h>
#include "pico/bootrom.h"

/*
 * ================================================================
 * LAMOKA1 DEV BRAIN — PORTAL INTERFACE ENGINE V1.8
 * ================================================================
 *
 * HOME
 * ----
 * 0 = BLUE STATUS BALL
 * 1 = FIREPLACE
 * 2 = LIGHTSABER
 * 3 = RAINBOW
 * 4 = GAMES
 * 5 = SETTINGS
 *
 * HOME COLORS
 * -----------
 * 0-3 = exact cactus green
 * 4   = games orange
 * 5   = settings blue
 *
 * CURSOR
 * ------
 * Every selected item is hot pink (breathing).
 * Cursors now remember the last selected item
 * (Games menu stays on Fireball after exit, etc.).
 *
 * DEFAULT IDLE
 * ------------
 * Blue bouncing status ball.
 *
 * FIREPLACE
 * ---------
 * Enhanced V1.8 realism:
 * - stronger organic wind + source drift
 * - multi-layer heat diffusion + rising
 * - height-aware cooling
 * - lively random licks + rising sparks
 * - richer palette (deep red → orange → yellow → white-hot)
 * - more dramatic tap / double-tap flares
 *
 * FIREBALL
 * --------
 * - D0 green target
 * - white projectile + hot/orange/red trail
 * - right-to-left travel
 * - tap exactly on target = catch
 * - catch → blast + binary score + speed-up
 * - miss → short red flash + immediate re-fire
 * - 3 lives, long-hold exits to Games menu (cursor stays on Fireball)
 *
 * LIGHTSABER
 * ----------
 * Never generates the exact same hue twice in a row.
 *
 * BRIGHTNESS
 * ----------
 * Hard floor = 6
 *
 * BOOTSEL
 * -------
 * reset_usb_boot(0, 0)
 *
 * RULE
 * ----
 * No min() / max() library calls anywhere.
 */

/* ================================================================
 * HARDWARE
 * ================================================================ */
#define LED_PIN           11
#define NUM_LEDS          10
#define BUTTON_PIN        0
#define COLOR_ENTROPY_PIN 5
#define ADC0              26
#define ADC1              27
#define ADC2              28
#define ADC3              29

#define DEFAULT_BRIGHTNESS 6
#define DEFAULT_SPEED      100
#define FRAME_MS           16
#define MENU_TIMEOUT_MS    16000UL

CRGB leds[NUM_LEDS];

/* ================================================================
 * COLORS
 * ================================================================ */
const CRGB COLOR_CACTUS   = CRGB(0, 90, 18);
const CRGB COLOR_HOT_PINK = CRGB(255, 40, 160);
const CRGB COLOR_GAMES    = CRGB(255, 90, 0);
const CRGB COLOR_SETTINGS = CRGB(0, 50, 100);

const CRGB FIRE_GREEN  = CRGB(0, 180, 40);
const CRGB FIRE_RED    = CRGB(150, 0, 0);
const CRGB FIRE_ORANGE = CRGB(255, 45, 0);
const CRGB FIRE_HOT    = CRGB(255, 130, 10);
const CRGB FIRE_WHITE  = CRGB(255, 255, 255);

/* ================================================================
 * ENUMERATIONS
 * ================================================================ */
enum Gesture : uint8_t {
  G_NONE,
  G_TAP,
  G_DOUBLE,
  G_HOLD,
  G_LONG_HOLD,
  G_VERY_LONG
};

enum UIState : uint8_t {
  UI_MODE,
  UI_MENU_MAIN,
  UI_MENU_GAMES,
  UI_MENU_SETTINGS,
  UI_BRIGHTNESS,
  UI_SPEED,
  UI_INFO,
  UI_IN_GAME,
  UI_SLEEP
};

/* ================================================================
 * GLOBAL SETTINGS
 * ================================================================ */
uint8_t globalBrightness = DEFAULT_BRIGHTNESS;
uint8_t globalSpeed      = DEFAULT_SPEED;

/* ================================================================
 * UI GLOBALS  (cursors now persist)
 * ================================================================ */
uint8_t mainCursor           = 0;
uint8_t gamesCursor          = 0;   // remembers last Games selection
uint8_t settingsCursor       = 0;   // remembers last Settings selection
uint8_t currentMainMode      = 0;
uint8_t settingsReturnCursor = 0;
uint32_t menuLastActivity    = 0;
UIState uiState              = UI_MODE;

/* ================================================================
 * LED HELPERS
 * ================================================================ */
void applyBrightness() {
  uint8_t b = globalBrightness;
  if (b < 6) b = 6;
  FastLED.setBrightness(b);
}

void clearLeds() {
  fill_solid(leds, NUM_LEDS, CRGB::Black);
}

CRGB blendColor(const CRGB &a, const CRGB &b, uint8_t amount) {
  return CRGB(
    lerp8by8(a.r, b.r, amount),
    lerp8by8(a.g, b.g, amount),
    lerp8by8(a.b, b.b, amount)
  );
}

void renderCursor(uint8_t index, uint8_t minimumBrightness = 180) {
  if (index >= NUM_LEDS) return;
  CRGB c = COLOR_HOT_PINK;
  c.nscale8(beatsin8(7, minimumBrightness, 255));
  leds[index] = c;
}

/* ================================================================
 * ENTROPY SERVICE
 * ================================================================ */
class EntropyService {
  uint32_t s = 1;

  void mix() {
    uint32_t a = analogRead(ADC0);
    uint32_t b = analogRead(ADC1);
    uint32_t c = analogRead(ADC2);
    uint32_t d = analogRead(ADC3);
    s ^= (a << 16);
    s ^= b;
    s ^= (c << 8);
    s ^= d;
    s ^= micros();
    s ^= ((uint32_t)digitalRead(COLOR_ENTROPY_PIN) << 23);
    s ^= s << 13;
    s ^= s >> 17;
    s ^= s << 5;
    s += 0x9E3779B9UL;
  }

public:
  void begin() {
    pinMode(ADC0, INPUT);
    pinMode(ADC1, INPUT);
    pinMode(ADC2, INPUT);
    pinMode(ADC3, INPUT);
    pinMode(COLOR_ENTROPY_PIN, INPUT);
    s ^= micros();
    for (uint16_t i = 0; i < 300; i++) mix();
  }

  void update() { mix(); }

  uint32_t next() {
    mix();
    s ^= s << 13;
    s ^= s >> 17;
    s ^= s << 5;
    return s;
  }

  uint8_t next8() { return (uint8_t)(next() & 255UL); }

  uint16_t range(uint16_t maximum) {
    if (maximum == 0) return 0;
    return (uint16_t)(next() % ((uint32_t)maximum + 1UL));
  }

  bool coin() { return (next() & 1UL) != 0; }
};

EntropyService entropy;

/* ================================================================
 * BUTTON SERVICE
 * ================================================================ */
class ButtonService {
  bool lastRaw         = HIGH;
  bool wasPressed      = false;
  bool pendingTap      = false;
  bool holdFired       = false;
  bool longFired       = false;
  bool veryLongFired   = false;
  uint32_t pressStart  = 0;
  uint32_t debounceStart = 0;
  uint32_t lastTap     = 0;

public:
  void begin() {
    pinMode(BUTTON_PIN, INPUT_PULLUP);
    lastRaw = digitalRead(BUTTON_PIN);
    debounceStart = millis();
  }

  Gesture poll(bool inMenu) {
    bool raw = digitalRead(BUTTON_PIN);
    uint32_t now = millis();

    if (raw != lastRaw) {
      debounceStart = now;
      lastRaw = raw;
    }
    if (now - debounceStart < 28) return G_NONE;

    bool pressed = !raw;

    if (pressed && !wasPressed) {
      wasPressed = true;
      pressStart = now;
      holdFired = longFired = veryLongFired = false;
      return G_NONE;
    }

    if (pressed) {
      uint32_t held = now - pressStart;
      if (held >= 2800 && !veryLongFired) {
        veryLongFired = true;
        return G_VERY_LONG;
      }
      if (held >= 1200 && !longFired) {
        longFired = true;
        return G_LONG_HOLD;
      }
      if (held >= 550 && !holdFired) {
        holdFired = true;
        return G_HOLD;
      }
    }

    if (!pressed && wasPressed) {
      wasPressed = false;
      uint32_t held = now - pressStart;
      if (!holdFired && !longFired && !veryLongFired && held < 400) {
        if (inMenu) return G_TAP;
        if (lastTap && now - lastTap < 380) {
          lastTap = 0;
          pendingTap = false;
          return G_DOUBLE;
        }
        lastTap = now;
        pendingTap = true;
      }
    }

    if (!inMenu && pendingTap && lastTap && now - lastTap >= 380) {
      pendingTap = false;
      return G_TAP;
    }

    return G_NONE;
  }
};

ButtonService button;

/* ================================================================
 * BASE MODE
 * ================================================================ */
class Mode {
public:
  virtual ~Mode() {}
  virtual void enter() {}
  virtual void update(Gesture) {}
  virtual void render() {}
};

/* ================================================================
 * STATUS — BLUE BOUNCING BALL
 * ================================================================ */
class ModeStatus : public Mode {
  int8_t p = 0;
  int8_t d = 1;
  uint32_t last = 0;

public:
  void enter() override {
    p = 0;
    d = 1;
    last = millis();
  }

  void render() override {
    clearLeds();
    uint16_t iv = (uint16_t)(28 + 8000 / (globalSpeed + 50));
    if (millis() - last >= iv) {
      last = millis();
      p += d;
      if (p >= 9) { p = 9; d = -1; }
      if (p <= 0) { p = 0; d = 1; }
    }

    for (int t = 0; t < 3; t++) {
      int q = p - d * t;
      if (q >= 0 && q < 10) {
        leds[q] = CRGB(0, 25 + t * 35, 70 + t * 55);
      }
    }
    leds[p] = CRGB(0, 70, 255);
  }
};

/* ================================================================
 * FIREPLACE — V1.8 REALISTIC UPGRADE
 * ================================================================ */
class ModeFire : public Mode {
  uint8_t heat[10];
  int16_t source = 4;
  int16_t target = 4;
  int8_t  sourceVel = 0;
  uint32_t lastMove = 0;
  uint8_t flare = 0;

  void chooseTarget() {
    // Prefer mid-low positions for natural fire base
    target = (int16_t)(1 + entropy.range(6));
  }

public:
  void enter() override {
    memset(heat, 0, sizeof(heat));
    source = target = 4;
    sourceVel = 0;
    lastMove = millis();
    flare = 0;
    for (uint8_t i = 0; i < 10; i++) {
      heat[i] = (uint8_t)(30 + entropy.range(50));
    }
  }

  void update(Gesture g) override {
    if (g == G_TAP) {
      flare = 160;
    }
    if (g == G_DOUBLE) {
      flare = 240;
      chooseTarget();
      sourceVel = (int8_t)(entropy.range(5) - 2);
    }
  }

  void render() override {
    uint32_t now = millis();

    // Organic source movement with velocity damping
    if (now - lastMove > 180UL + entropy.range(220)) {
      chooseTarget();
      lastMove = now;
      sourceVel = (int8_t)(entropy.range(3) - 1);
    }

    // Smooth source + light velocity
    if (source < target) source++;
    else if (source > target) source--;
    source += sourceVel;
    if (source < 1)  { source = 1;  sourceVel = 0; }
    if (source > 8)  { source = 8;  sourceVel = 0; }
    if (sourceVel) sourceVel = sourceVel > 0 ? sourceVel - 1 : sourceVel + 1;

    // Multi-octave wind
    uint8_t wind1 = inoise8(now / 70);
    uint8_t wind2 = inoise8(now / 140 + 50);
    int8_t drift = (int8_t)(((int)wind1 - 128) / 28 + ((int)wind2 - 128) / 40);

    // Height-aware cooling (hotter at base, cooler higher)
    for (uint8_t i = 0; i < 10; i++) {
      uint8_t cooling = (uint8_t)(2 + entropy.range(3) + (i * 3) / 8);
      heat[i] = heat[i] > cooling ? heat[i] - cooling : 0;
    }

    // Source injection with organic fuel
    int16_t rawSource = source + drift;
    if (rawSource < 0) rawSource = 0;
    if (rawSource > 9) rawSource = 9;
    uint8_t sourcePos = (uint8_t)rawSource;

    uint8_t fuel = (uint8_t)(120 + entropy.range(70) + (flare ? 40 : 0));
    heat[sourcePos] = qadd8(heat[sourcePos], fuel);
    if (sourcePos > 0) heat[sourcePos - 1] = qadd8(heat[sourcePos - 1], fuel / 2);
    if (sourcePos < 9) heat[sourcePos + 1] = qadd8(heat[sourcePos + 1], fuel / 3);

    // Stronger diffusion
    uint8_t old[10];
    memcpy(old, heat, sizeof(heat));
    for (uint8_t i = 1; i < 9; i++) {
      uint16_t average = (uint16_t)old[i - 1] + (old[i] * 2) + old[i + 1];
      heat[i] = lerp8by8(old[i], (uint8_t)(average / 4), 160);
    }

    // Rising heat (stronger upward bias)
    for (int i = 9; i >= 1; i--) {
      uint16_t rising = (uint16_t)heat[i - 1] * 3 / 2;
      if (i >= 2) rising += heat[i - 2] / 2;
      heat[i] = lerp8by8(heat[i], (uint8_t)(rising > 255 ? 255 : rising), 180);
    }

    // Random flame licks + rising sparks
    if (entropy.next8() > 200) {
      int q = sourcePos + (int)entropy.range(4) - 1;
      if (q < 1) q = 1;
      if (q > 8) q = 8;
      uint8_t f = (uint8_t)(70 + entropy.range(120));
      heat[q] = qadd8(heat[q], f);
      if (q < 9) heat[q + 1] = qadd8(heat[q + 1], f / 2);
      if (q < 8 && entropy.coin()) heat[q + 2] = qadd8(heat[q + 2], f / 4);
    }

    // Occasional high spark
    if (entropy.next8() > 245) {
      uint8_t spark = (uint8_t)(5 + entropy.range(4));
      heat[spark] = qadd8(heat[spark], (uint8_t)(100 + entropy.range(80)));
    }

    // Dramatic flare decay
    if (flare) {
      heat[sourcePos] = qadd8(heat[sourcePos], flare);
      if (sourcePos < 9) heat[sourcePos + 1] = qadd8(heat[sourcePos + 1], flare * 2 / 3);
      if (sourcePos < 8) heat[sourcePos + 2] = qadd8(heat[sourcePos + 2], flare / 3);
      flare = flare > 9 ? flare - 9 : 0;
    }

    // Force a living base glow
    if (heat[0] < 40) heat[0] = 40 + entropy.range(20);

    // Rich realistic palette
    for (uint8_t i = 0; i < 10; i++) {
      uint8_t noise = inoise8(now / 32 + i * 41);
      heat[i] = scale8(heat[i], (uint8_t)(210 + (noise >> 4)));
      uint8_t h = heat[i];

      if (h < 20) {
        leds[i] = blendColor(CRGB(4, 0, 0), CRGB(30, 1, 0), (uint8_t)(h * 12));
      } else if (h < 55) {
        leds[i] = blendColor(CRGB(30, 1, 0), CRGB(120, 8, 0),
                             scale8((uint8_t)(h - 20), 255));
      } else if (h < 100) {
        leds[i] = blendColor(CRGB(120, 8, 0), CRGB(255, 40, 0),
                             scale8((uint8_t)(h - 55), 255));
      } else if (h < 155) {
        leds[i] = blendColor(CRGB(255, 40, 0), CRGB(255, 140, 10),
                             scale8((uint8_t)(h - 100), 255));
      } else if (h < 210) {
        leds[i] = blendColor(CRGB(255, 140, 10), CRGB(255, 220, 60),
                             scale8((uint8_t)(h - 155), 255));
      } else {
        // White-hot core
        leds[i] = blendColor(CRGB(255, 220, 60), CRGB(255, 250, 200),
                             scale8((uint8_t)(h - 210), 255));
      }
    }
  }
};

/* ================================================================
 * LIGHTSABER — never same hue twice in a row
 * ================================================================ */
class ModeSaber : public Mode {
  uint8_t hue = 0;
  uint8_t lastHue = 255;          // force first launch to be different
  uint8_t sat = 220;
  uint8_t pattern = 0;
  uint8_t instability = 30;
  uint8_t power = 0;
  uint8_t clash = 0;
  bool extending = true;
  uint32_t ignition = 0;

  void launch() {
    // Guarantee a different hue from the previous blade
    do {
      hue = entropy.next8();
    } while (hue == lastHue);
    lastHue = hue;

    sat = (uint8_t)(175 + entropy.range(65));
    pattern = (uint8_t)entropy.range(6);
    instability = (uint8_t)(20 + entropy.range(80));
    power = 0;
    extending = true;
    ignition = millis();
  }

public:
  void enter() override { launch(); }

  void update(Gesture g) override {
    if (g == G_TAP) {
      if (extending) extending = false;
      else launch();
    }
    if (g == G_DOUBLE) launch();
    if (g == G_HOLD) clash = 16;
  }

  void render() override {
    clearLeds();
    uint8_t rate = (uint8_t)(7 + globalSpeed / 30);
    if (pattern == 1) rate += 4;
    if (pattern == 3 && rate > 2) rate--;

    if (extending) power = qadd8(power, rate);
    else           power = qsub8(power, 10);

    uint8_t len = scale8(power, 10);

    for (uint8_t i = 0; i < len; i++) {
      uint8_t b = qsub8(255, (uint8_t)(i * 11));

      if (pattern == 3 && entropy.next8() < instability) b = scale8(b, 120);
      if (pattern == 5 && entropy.next8() > 220)         b = 255;
      if (pattern == 4) b = scale8(b, beatsin8(12, 145, 255));
      if (pattern == 2) b = scale8(b, beatsin8(9, 185, 255));
      if (pattern == 1 && i == 0) b = 255;

      leds[i] = CHSV(hue, sat, b);
      if (i < 2) {
        leds[i] = blendColor(leds[i], CRGB::White, pattern == 1 ? 95 : 75);
      }
    }

    if (extending && millis() - ignition < 170 && len) {
      leds[0] = blendColor(leds[0], CRGB::White, 180);
    }

    if (clash) {
      for (uint8_t i = 0; i < len; i++) {
        if (entropy.next8() > 90) {
          leds[i] = blendColor(leds[i], CRGB::White, 210);
        }
      }
      clash--;
    }

    if (len && entropy.next8() > 220) {
      uint8_t p = entropy.next8() % len;
      leds[p] = blendColor(leds[p], CRGB::White, 150);
    }
  }
};

/* ================================================================
 * RAINBOW
 * ================================================================ */
class ModeRainbow : public Mode {
  uint8_t hue = 0;
  uint8_t spd = 3;
  bool rev = false;

public:
  void enter() override { hue = entropy.next8(); }

  void update(Gesture g) override {
    if (g == G_TAP)    spd = (uint8_t)(spd % 10 + 1);
    if (g == G_DOUBLE) rev = !rev;
  }

  void render() override {
    uint8_t s = (uint8_t)(spd * (globalSpeed + 40) / 75);
    if (!s) s = 1;
    if (rev) hue -= s;
    else     hue += s;
    fill_rainbow(leds, NUM_LEDS, hue, 16);
  }
};

/* ================================================================
 * MODE INSTANCES
 * ================================================================ */
ModeStatus  modeStatus;
ModeFire    modeFire;
ModeSaber   modeSaber;
ModeRainbow modeRainbow;

Mode* mainModes[] = {
  &modeStatus,
  &modeFire,
  &modeSaber,
  &modeRainbow
};
const uint8_t MAIN_MODE_COUNT = 4;

/* ================================================================
 * FIREBALL GAME
 * ================================================================ */
class AppFireball {
  static const int TARGET_LED  = 0;
  static const int START_SPEED = 115;
  static const int SPEEDUP     = 10;
  static const int MIN_SPEED   = 30;

  enum GameState : uint8_t {
    GAME_RUNNING,
    GAME_BLAST,
    GAME_SCORE,
    GAME_MISSED,
    GAME_OVER
  };

  GameState state        = GAME_RUNNING;
  uint16_t  score        = 0;
  uint8_t   lives        = 3;
  int       firePosition = NUM_LEDS - 1;
  int       fireSpeed    = START_SPEED;
  uint32_t  lastMove     = 0;
  uint32_t  stateStart   = 0;

  uint8_t displayedScore() const {
    return score > 10 ? 10 : (uint8_t)score;
  }

  void drawGame() {
    clearLeds();
    leds[TARGET_LED] = FIRE_GREEN;

    if (firePosition >= 0 && firePosition < NUM_LEDS) {
      leds[firePosition] = FIRE_WHITE;
    }
    if (firePosition + 1 < NUM_LEDS) leds[firePosition + 1] = FIRE_HOT;
    if (firePosition + 2 < NUM_LEDS) leds[firePosition + 2] = FIRE_ORANGE;
    if (firePosition + 3 < NUM_LEDS) leds[firePosition + 3] = FIRE_RED;
  }

  void beginRound() {
    firePosition = NUM_LEDS - 1;
    lastMove = millis();
    state = GAME_RUNNING;
  }

  void startBlast() {
    stateStart = millis();
    state = GAME_BLAST;
  }

  void catchFireball() {
    score++;
    fireSpeed -= SPEEDUP;
    if (fireSpeed < MIN_SPEED) fireSpeed = MIN_SPEED;
    startBlast();
  }

  void missFireball() {
    if (lives > 0) lives--;
    stateStart = millis();
    state = (lives == 0) ? GAME_OVER : GAME_MISSED;
  }

  void renderBlast() {
    clearLeds();
    uint32_t elapsed = millis() - stateStart;
    uint8_t frame = (uint8_t)(elapsed / 45UL);
    if (frame > 7) frame = 7;

    for (int i = 0; i < NUM_LEDS; i++) {
      int distance = abs(i - TARGET_LED);
      if (distance <= frame) {
        int level = 255 - distance * 50 - frame * 18;
        if (level < 10) level = 10;
        leds[i] = CRGB((uint8_t)level, (uint8_t)(level / 2), (uint8_t)(level / 12));
      }
    }
  }

  void renderScore() {
    clearLeds();
    uint8_t shown = displayedScore();
    for (uint8_t i = 0; i < 10; i++) {
      if (shown & (1U << i)) leds[i] = COLOR_CACTUS;
    }
  }

public:
  void enter() {
    score = 0;
    lives = 3;
    fireSpeed = START_SPEED;
    firePosition = NUM_LEDS - 1;
    lastMove = millis();
    state = GAME_RUNNING;
    stateStart = millis();
  }

  void update(Gesture g) {
    if (state == GAME_OVER) {
      if (g == G_TAP) enter();
      return;
    }
    if (state == GAME_BLAST || state == GAME_SCORE || state == GAME_MISSED) return;

    if (state == GAME_RUNNING && g == G_TAP) {
      if (firePosition == TARGET_LED) catchFireball();
    }
  }

  void render() {
    if (state == GAME_RUNNING) {
      uint32_t now = millis();
      if (now - lastMove >= (uint32_t)fireSpeed) {
        lastMove = now;
        firePosition--;
        if (firePosition < TARGET_LED) missFireball();
      }
      if (state == GAME_RUNNING) drawGame();
      return;
    }

    if (state == GAME_BLAST) {
      uint32_t elapsed = millis() - stateStart;
      renderBlast();
      if (elapsed >= 360) {
        state = GAME_SCORE;
        stateStart = millis();
      }
      return;
    }

    if (state == GAME_SCORE) {
      renderScore();
      if (millis() - stateStart >= 750) beginRound();
      return;
    }

    if (state == GAME_MISSED) {
      clearLeds();
      uint32_t elapsed = millis() - stateStart;
      if (elapsed < 70) fill_solid(leds, NUM_LEDS, FIRE_RED);
      if (elapsed >= 140) beginRound();
      return;
    }

    if (state == GAME_OVER) {
      clearLeds();
      uint8_t pulse = beatsin8(4, 30, 180);
      fill_solid(leds, NUM_LEDS, CRGB(pulse, 0, 0));
      uint8_t shown = displayedScore();
      for (uint8_t i = 0; i < 10; i++) {
        if (shown & (1U << i)) leds[i] = COLOR_CACTUS;
      }
    }
  }
};

AppFireball appFireball;
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
void loop() {
  static uint32_t lastFrame = 0;
  uint32_t now = millis();

  if (uiState == UI_SLEEP) {
    updateShutdown();
    delay(5);
    return;
  }

  entropy.update();

  if (inAnyMenu() && now - menuLastActivity > MENU_TIMEOUT_MS) {
    returnToIdle();
  }

  Gesture g = button.poll(inAnyMenu() || uiState == UI_IN_GAME);
  if (g != G_NONE) handleUI(g);

  if (now - lastFrame >= FRAME_MS) {
    lastFrame = now;
    renderUI();
    FastLED.show();
  }
}

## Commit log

2026-06-21 Working on boost section
    [DQJ0008A.stp, Inverter.kicad_pcb, Inverter.kicad_sch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]
2026-06-21 ADD footprints for items
    [boostconverter.kicad_sch]
2026-06-22 ADD some better foot printing, better documentation
    [boostconverter.kicad_sch]
2026-06-22 ADD more footprint, 3D models
    [CSD19531Q5A.stp, DQJ0008A.stp, LM5122MHE_NOPB.stp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]
2026-06-24 ADD alot of work (I dont even remember what i did lol)
    [SDM1U100S1F-7.stp, boostconverter.kicad_pcb, boostconverter.kicad_sch]
2026-06-24 ADD alot of random stuff (footprints, etc)
    [CNC5L1X7R1H106K160AE.stp, GJ821BR71H105KA12K.stp, boostconverter.kicad_pcb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]
2026-06-25 REFORMAT we needed some hierarchical sheets
    [Boost.kicad_sch, CNC5L1X7R1H106K160AE.stp, CSD19531Q5A.stp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]
2026-06-26 ADD the schematic for testing the boost section is all done and configured
    [Boost.kicad_sch, Lamoka1.csv, Lamoka1.kicad_pcb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]
2026-06-26 FIX making things look better
    [Boost.kicad_sch, Lamoka1.csv, Lamoka1.kicad_pcb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]
2026-06-28 Improve on the values for the schematic of boost converter
    [Boost.kicad_sch, Lamoka1.csv, Lamoka1.kicad_pcb]
2026-06-29 FIX values and add info
    [Boost.kicad_sch, Lamoka1.csv, Lamoka1.kicad_pcb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]
2026-06-29 URGENT had to fix a connection
    [Boost.kicad_sch, Lamoka1.kicad_pcb]
2026-06-30 FIX add net system for schematic of boost converter
2026-06-30 REAL actually fixing it for the net system
    [Boost.kicad_sch, Lamoka1.csv, Lamoka1.kicad_pcb]
2026-06-30 ADD more misc "housekeeping" work for boost converter
    [Boost.kicad_sch, Higherboost.kicad_sch, Lamoka1.csv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]
2026-06-30 Make boost schem more neat, ADD top priority image
    [Boost.kicad_sch]
2026-07-01 Improving everything for boost converter section
    [Boost.kicad_sch, Lamoka1.csv, Lamoka1.kicad_pcb]
2026-07-01 Fix CI error: set image to latest KiCad
2026-07-02 Working on getting the PCB layout setup for the boost converter
    [Boost.kicad_sch, Lamoka1.csv, Lamoka1.kicad_pcb]
2026-07-02 Reconfiguring the BOM, other misc tasks
    [Boost.kicad_sch, Lamoka1.csv, Lamoka1.kicad_pcb]
2026-07-03 Take things out so boost converter can be standalone
    [Boost.kicad_sch, Lamoka1.csv, Lamoka1.kicad_pcb]
2026-07-05 Doing random things with the boost converter
    [Boost.kicad_sch, Lamoka1.kicad_pcb]
2026-07-06 FIX make boost converter standalone
    [Boost.kicad_sch, Lamoka1.csv, Lamoka1.kicad_pcb]
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2026-07-14 Cleaning up the DEV-Brains folder
    [Lamoka1-DEV-board.kicad_pcb, Lamoka1-DEV-board.kicad_sch]
2026-07-14 Improve Lamoka1-DEV-Brain folder contents
    [Lamoka1-DEV-board.kicad_pcb, Lamoka1-DEV-board.kicad_sch]
2026-07-14 ADD warning and 3D print files to DEV-Brain
    [Lamoka1-DEV-Brain_1to1_P1S-0.4mm_PRINT.stl, Lamoka1-DEVC-Brain.3mf]
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2026-07-18 FIX some things, random issues
    [Boost.kicad_sch, ChargingSection.kicad_sch, Higherboost.kicad_sch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]
2026-07-22 ADD charging section and multiple color Dev-Brain 3d print
    [Boost.kicad_sch, ChargingSection.kicad_sch, Control.kicad_sch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]
2026-07-23 ADD better DEV-Brain models, Slight improvements to the Lamoka1 charging section
    [3-models-1-plate.3mf, ChargingSection.kicad_sch, Lamoka1-DEV-Brain_1to1_P1S-0.4mm_PRINT.stl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]
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2026-07-24 Better multiple color model for Lamoka1-DEV-Brain
    [3-models-1-board.3mf, 3-models-1-plate.3mf, Control.kicad_sch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]
2026-07-24 ADD values to Lamoka1 charging section, and Lamoka1 control button
    [Control.kicad_sch]
2026-07-24 ADD best model so far
    [3-models-1-board.3mf]
2026-07-31 Improvement to charging section
    [ChargingSection.kicad_sch]
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2026-08-03 FIX whole Lamoka1 general stuff
    [Boost.kicad_sch, ChargingSection.kicad_sch, Lamoka1.csv]
2026-08-18 ADD Dev-Brain software and simple method to purchase
    [Bill of materials.csv, Boost.kicad_sch, Pick and Place file.csv]
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2026-08-21 General fixes to Kicad
    [Boost.kicad_sch]
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2026-08-22 New PIE version, misc hardware schem improments for Lamoka1
    [Boost.kicad_sch, Control.kicad_sch]
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2026-08-25 docs: Document prototype P1 schematic design improvements
    Major updates to boost converter topology with LM5122 driver,
    connect all section interfaces (charging, control), fix net connectivity.
    This represents a near-complete functional schematic for the Lamoka1
    inverter/charger system. All three main sections now have proper
    interconnections for the RP2354A control implementation.
    [Boost.kicad_sch, ChargingSection.kicad_sch, Control.kicad_sch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]
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2026-08-25 Revert "General automated improvements"
    This reverts commit 3ef05bc7b444b140291ba00422bcdc30a4dbf2f6.
    [Inverter.kicad_sch]
2026-08-25 Revert "docs: Document prototype P1 schematic design improvements"
    This reverts commit 9a36aaba68a23f8da8ed8c8f957268abdd88419f.
    [Boost.kicad_sch, ChargingSection.kicad_sch, Control.kicad_sch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]
2026-08-25 Revert "docs: Add inverter design documentation"
    This reverts commit e24f26d40478289c236e3021b02ba032543aac87.
    [Inverter.kicad_sch]
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2026-09-14 ADD in the better method for making the Lamoka1 schems
    [Boost.kicad_sch, Control-section.kicad_sch, Control.kicad_sch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]
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2026-09-15 Moving everything to the correct locations
    [Control-section.kicad_sch, Inversion-section.kicad_sch, Lamoka1.kicad_pcb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]
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2026-09-16 ADD logo, repo grade, and cosmetic/finishing H bridge connections
    [Control-section.kicad_sch, Inversion-section.kicad_sch, Lamoka1.kicad_sch]
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2026-09-17 ADD fan connection, and finish buck converter 5v
    [Control-section.kicad_sch, Inversion-section.kicad_sch, Lamoka1.kicad_sch]
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2026-09-18 Correcting orientation of H bridge NMOSs in design notes
    [Inversion-section.kicad_sch]
2026-09-18 Giving Q1 and Q2 values that represent their respected MPNs. Changing temp sensor outputs to ADC pins instead of regular GPIO. Correcting design notes to reflect new GPIO pin change
    [Control-section.kicad_sch, Inversion-section.kicad_sch]
2026-09-18 ADD better format for connectors, output connector, transformer connector, and more
    [Control-section.kicad_sch, Inversion-section.kicad_sch, Lamoka1.kicad_sch]
2026-09-20 MPN fixes, footprint fixes, ADD MUX and voltage sensing. ADD photo in main readme
    [Control-section.kicad_sch, Inversion-section.kicad_sch, Lamoka1.csv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]
2026-09-21 ADD source current monitoring, and other features, some more correcting of MPN and footprints
    [Control-section.kicad_sch, Lamoka1.csv, Lamoka1.kicad_pcb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]
2026-09-21 General work on schem, BOM, footprints. Rout 11-14v to 5v buck converter
    [Control-section.kicad_sch, Inversion-section.kicad_sch, Lamoka1.csv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]
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2026-09-22 Fix energy flow/current sense location chart
2026-09-22 Fix flow chart again
2026-09-22 Fix the same flow chart, yet again
2026-09-22 Pretty annoying, but here is yet another fix of the energy flow chart
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2026-09-23 Route in pin header for user interface board, and put in connector for fan, other changes as well
    [Control-section.kicad_sch, Lamoka1.kicad_pcb, Lamoka1.kicad_sch]
2026-09-24 ADD H bridge section, tighten everything in PCB routing to be neater. ADD mounting holes M3, etc
    [Control-section.kicad_sch, Inversion-section.kicad_sch, Lamoka1.csv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]
2026-09-24 More various routing, finish assigning of all components in inversion and control section. ADD interactive BOM, clean up documentation
    [Control-section.kicad_sch, Lamoka1-DEV-board.kicad_pcb, Lamoka1.csv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]
2026-09-25 Route 1v1 converter for control section of Lamoka1
    [Lamoka1.kicad_pcb]
2026-09-27 Route in crystall oscillator for control section. Fix a ton of DRC issues, etc
    [Inversion-section.kicad_sch, Lamoka1.kicad_pcb]
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2026-09-28 General fixes to DRC, etc (Lamoka1/2)
    [Lamoka1-DEV-board.kicad_pcb, Lamoka1.csv, Lamoka1.kicad_pcb]
2026-09-28 misc fixes to Lamoka1/2
    [Control-section.kicad_sch, Lamoka1.kicad_pcb]
2026-09-29 Get DRC down all the way, other misc improvements
    [Control-section.kicad_sch, Inversion-section.kicad_sch, Lamoka1.kicad_pcb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]
2026-09-29 Some more slight improvements, general. ADD picture to main readme, etc
    [Lamoka1.kicad_pcb, Lamoka1.kicad_sch]
2026-09-30 Make Kicad its own language, fix that kind of stuff
2026-09-30 spelling issues, add links for dev brain, general improvements to repo, etc
    [Lamoka1-DEV-board-B_Cu.gbr, Lamoka1-DEV-board-B_Mask.gbr, Lamoka1-DEV-board-B_Paste.gbr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]
2026-09-30 misc fixes
    [Control-section.kicad_sch, Inversion-section.kicad_sch, Lamoka1-DEV-board.kicad_pcb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]
2026-10-02 General fixes, laying H bridge transformers side by side for more effective heat dissapation. fixed footprints to datasheet specific
    [Inversion-section.kicad_sch, Lamoka1.csv, Lamoka1.kicad_pcb]
2026-10-04 major reform on the size of the Lamoka1/2
    [Control-section.kicad_sch, Inversion-section.kicad_sch, Lamoka1.csv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]
2026-10-05 misc fixes to the Lamoka1/2, more routing and all that fun stuff
    [Lamoka1.kicad_pcb]
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2026-10-08 MORE ROUTING FOR THE LAMOKA1/2, JUST CONTROL RELATED STUFF HERE
    [Lamoka1.kicad_pcb]
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2026-10-10 Routing H bridge paths, other various routing. Lamoka1/2
    [Lamoka1.kicad_pcb]
2026-10-18 Improving openSSF and Repograde rankings, Fixing misc PCB errors
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

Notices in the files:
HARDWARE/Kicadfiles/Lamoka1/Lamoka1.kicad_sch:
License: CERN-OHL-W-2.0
